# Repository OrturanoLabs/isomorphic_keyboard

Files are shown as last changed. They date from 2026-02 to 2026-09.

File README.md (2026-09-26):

# Isomorphic keyboard

An open-source, **modular isomorphic keyboard**. The instrument is built from identical
12-key tiles that plug into each other in any arrangement. A pico-ice (Lattice iCE40UP5K)
rediscovers the arrangement on every scan and plays it over **MIDI**. Tiles can be added,
removed and moved while playing.

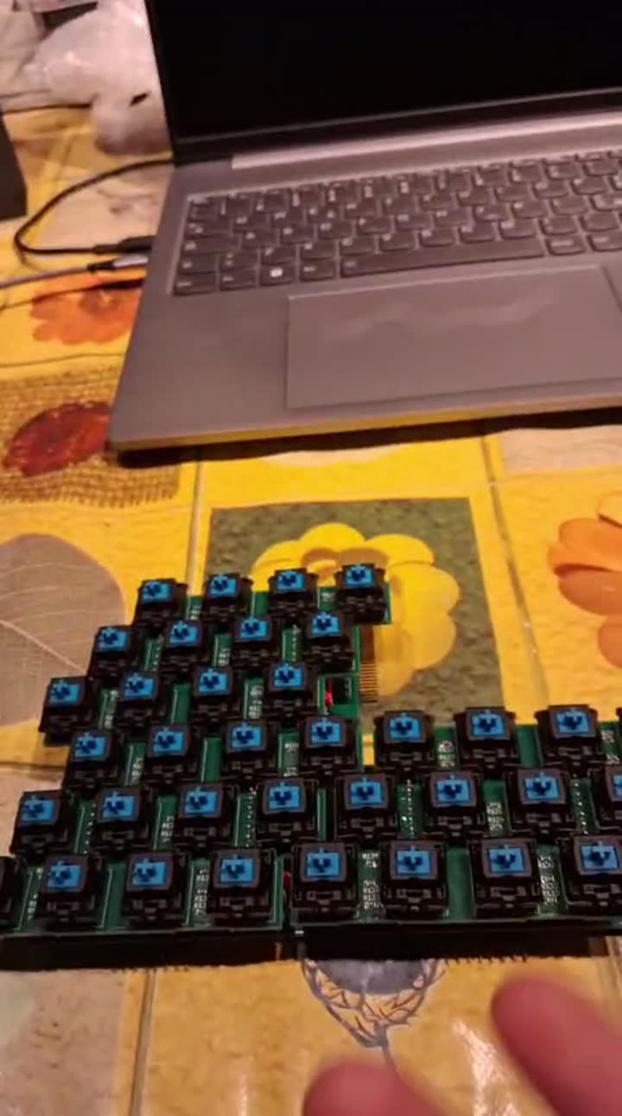
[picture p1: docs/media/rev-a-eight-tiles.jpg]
Eight rev-A tiles


## Status

- **rev A** (tag `rev-a-prototype`): working prototype. Double-stack tiles (key board over
  logic board), hot-plug, automatic above/below/beside detection, MIDI DIN output.
- **rev B** (branch `rev-b`, in progress): the same function with cleaner signals
  (termination, 4-layer stack-up) and a PCB ready for automated assembly.

## Repository layout

| Path | Content |
|---|---|
| `docs/` | documentation: [index](docs/index.md), [engineering ledger](docs/LEDGER.md) |
| `hardware/kicad/tile/` | KiCad project of the tile (key board + logic board) |
| `hardware/simulation/` | behavioural VHDL model of a tile and grid testbenches |
| `hardware/fabrication/rev-a/` | gerbers and BOM of the manufactured rev-A boards |
| `firmware/ice40/` | controller firmware (VHDL) for the pico-ice |
| `firmware/experiments/` | earlier bring-up designs, kept for reference |
| `tools/` | rootless container recipes, `kicad-cli` / OSS CAD Suite wrappers, check scripts |
| `LICENSES/` | full license texts |

## Quick start

```sh
# firmware (rootless podman)
podman build -t localhost/oss-cad-suite:2026-09-26 tools/containers/oss-cad-suite
cd firmware/ice40 && ../../tools/oss.sh make && make upload-flash

# hardware
flatpak install --user flathub org.kicad.KiCad
flatpak run org.kicad.KiCad hardware/kicad/tile/isomorphic_tile.kicad_pro
```

See [docs/build/firmware.md](docs/build/firmware.md) and
[docs/build/hardware.md](docs/build/hardware.md).

## Licenses

| Part | License |
|---|---|
| Hardware (`hardware/`) | CERN-OHL-S v2 |
| Firmware and tools (`firmware/`, `tools/`) | GPL-3.0 |
| Documentation (`docs/`) | CC BY 4.0 |
| Vendored Open Logic subset (`firmware/ice40/src/open-logic/`) | PSI HDL Library License 1.0 |

Full texts are in `LICENSES/`. Each top-level folder has its own `LICENSE.md`.

© Orturano Labs

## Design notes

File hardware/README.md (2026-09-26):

# Hardware

| Folder | Content |
|---|---|
| `kicad/tile/` | KiCad project `isomorphic_tile`: key board (12 Cherry MX keys) and logic board (shift registers, chaining logic, edge connectors), fabricated as one panel |
| `simulation/` | behavioural VHDL model of a tile (`tile.vhdl`, `74hc165.vhdl`) and grid testbenches (`tile_tb*.vhdl`); run with `make` (GHDL), view with GTKWave |
| `fabrication/rev-a/` | gerbers and BOM of the rev-A boards as manufactured |

Start with [docs/architecture/overview.md](../docs/architecture/overview.md) and
[docs/build/hardware.md](../docs/build/hardware.md). The latter covers the mandatory
ERC/DRC/invariant checks.

License: CERN-OHL-S v2 (see `LICENSE.md`).

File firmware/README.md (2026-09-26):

# Firmware

| Folder | Content |
|---|---|
| `ice40/` | controller for the pico-ice (iCE40UP5K): tile scan, topology discovery, debouncing, MIDI UART |
| `experiments/` | earlier bring-up designs: `i2c_picoice` (I2C master test), `scan_low_rate` (slow tile scan), `scan_low_rate_i2c` (slow scan + I2C output) |

There is no microcontroller firmware yet: the pico-ice FPGA sends MIDI directly.

Build, flash and simulation: [docs/build/firmware.md](../docs/build/firmware.md).
Protocol: [docs/architecture/protocol.md](../docs/architecture/protocol.md).

License: GPL-3.0 (see `LICENSE.md`). The vendored Open Logic subset keeps its own license.

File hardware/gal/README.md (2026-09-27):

# GAL experiment: rev-A/B glue logic in one ATF22V10C

`tile_glue.pld` puts the seven glue ICs of the rev-A/B tile (U101 2G126, U102 2G08,
U105 1G04, U106 2G32, U107 2G125, U108 2G74, U109 '161) into **one ATF22V10C** (Microchip,
in production, 5 V, TSSOP-24/SOIC-24). The two '165 shift registers stay, so a tile would
have 3 ICs instead of 9. The scan protocol and the FPGA firmware are unchanged.

| Macrocell | Function |
|---|---|
| Q0–Q3 (buried) | 4-bit counter of board-clock edges, cleared by the latch ('161) |
| BW | sticky column-end flag = B_W output ('74 + 2G08 + 2G32) |
| TCLK / LCLK | board clock forwarded up (W = 0) or left (W = 1) ('125/'126) |
| LATCH / NPL | latch merge to the neighbours and, inverted, to the '165 /PL ('32 + '04) |
| DS | serial input of the '165 chain: left when W = 1, top otherwise |

**All 10 macrocells are used: no margin left.**

The 22V10 allows a **single product term** for both the output enable and the
asynchronous reset. That forced two adaptations:

- T_clk is driven **low** when unselected instead of floating. At most this makes a
  falling edge, and the registers count rising edges.
- The asynchronous reset (AR) uses the feedback of the LATCH output.

Build (open source, rootless):

```sh
podman build -t localhost/galette tools/containers/galette
cd hardware/gal && podman run --rm --userns=keep-id -v "$PWD":/work:Z localhost/galette tile_glue.pld
```

This produces `tile_glue.jed`, plus `.chp` (pin diagram), `.fus` and `.pin`. Program it
with [Afterburner](https://github.com/ole00/afterburner), an open-source Arduino-based
GAL programmer. It lists ATF22V10B/CQZ; check ATF22V10C support before buying.

**Status:** assembled and fits. **Not simulated yet.** The equations were derived by
hand from the rev-A netlist.

**Verdict:** the GAL answers "fewer parts, no firmware on the tile". It does not provide
a return path for per-key LEDs, which is why rev C goes the microcontroller way.

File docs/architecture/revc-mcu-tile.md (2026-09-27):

# Rev C tile with a microcontroller (architecture draft)

Status: **draft for review**. It supersedes the "74xx logic folded on one board" idea of
[revc-single-board.md](revc-single-board.md). The geometry work there (lattice,
edge windows, contact placement) still applies.

## Why the architecture changes

Rev C goals (owner, 2026-09-27):

- a single board;
- the minimum equilateral MX lattice (18.36 mm);
- few, simple, widely available parts;
- modular;
- **strictly open-source tooling**;
- room for a **return path**: per-key LEDs, or any tile-side output.

With 74xx logic, a return path costs extra shift registers and 1–2 extra lines per edge
(7–9 contacts per edge). The 18.4 mm tile has no room for that: the 74xx version already
leaves 13 connections unrouted on 4 layers, and the top edge fits only 7 contacts.

A small microcontroller per tile replaces all nine logic ICs:

- one **bidirectional** data line per edge carries key events up and LED commands down,
  so no extra contacts are needed;
- per-key addressable LEDs hang off one pin.

Why not a small FPGA per tile: it would need 1.2 V + 3.3 V regulators, cannot use 5 V
I/O, needs an external configuration flash, comes in fine-pitch packages and costs
2–6 €, for a job (12 keys, a few messages, 12 LEDs) that a 1 € microcontroller does
easily. The FPGA stays where parallel work pays off: the controller.

## Tile block diagram

```
          top edge: VCC DATA_T GND                (passive pads)
        +-------------------------------------------------+
 left   |  12 x MX switch --> GPIO (internal pull-ups)     |  right
 edge   |                                                  |  edge
 pads   |  ATtiny1616 (VQFN-20, 5 V, 20 MHz)               |  springs
 VCC    |    DATA_L  DATA_R  DATA_T  DATA_B  (1 wire each) |  VCC
 GND    |    LED --> SK6812MINI-E x 12 (optional, chained)  |  GND
 DATA_L |    UPDI (programming pad)                        |  DATA_R
        +-------------------------------------------------+
          bottom edge: VCC DATA_B GND             (springs)
```

## Parts per tile

| Part | Qty | Notes |
|---|---|---|
| ATtiny1616-MNR (VQFN-20 3×3 mm; the SOIC-20 wide does not fit) | 1 | 1.8–5.5 V; 20 MHz at ≥ 4.5 V; open toolchain (avr-gcc, avrdude/pymcuprog, SerialUPDI) |
| 100 nF + 1–4.7 µF decoupling | 2 | |
| series resistor on each edge data line (~100 Ω) | 4 | edge-rate control and ESD/short protection on the hot-plug contacts |
| Kailh MX hot-swap socket | 12 | as rev B |
| SK6812MINI-E reverse-mount RGB LED + 100 nF | 12 + (3–12) | **optional**; in the Cherry MX drawing the LED window is **south** of the centre hole, opposite the pins/socket (north), so there is no conflict |
| edge contacts | 3 per edge | VCC, DATA, GND: springs on the right/bottom edges, pads on the left/top edges |

That is about 7 parts without LEDs, instead of about 63 in rev B. There are no key
resistors: the switch goes to GND and the pin uses its internal pull-up.

## Switches and LEDs

- The Cherry MX drawing ("1-Pole w/LED") puts the LED window **south** of the centre hole:
  two 1 mm holes at ±1.27 mm, 5.08 mm from the centre. The switch pins, and therefore the
  hot-swap socket, are **north**, so the LED and the socket do not collide.
- For a reverse-mount SMD LED under the PCB, use "RGB"/"SMD-ready" switches with a clear
  top housing or light pipe: Cherry MX RGB, and most Gateron/Kailh/Outemu RGB variants.
  The KiCad footprint `LED_SMD:LED_SK6812MINI-E_3.2x2.8mm_P1.5mm_ReverseMount` includes
  the PCB cut-out.
- SK6812MINI-E pins (KiCad symbol `LED:SK6812MINI-E`): 1 VSS, 2 DIN, 3 VDD, 4 DOUT.
- Keycaps: 3D printed. Use translucent material, or add a window over the LED.

## Pin budget (ATtiny1616, 20-pin; from the Microchip datasheet DS40002204A)

- 17 GPIO are usable, because PA0 stays **UPDI** so the tile can always be reprogrammed.
- Use: 12 keys + 4 edge data lines + 1 LED data = **17**.
- The one USART can map its TX pin to PB2 (default) or PA1 (alternate), and supports
  one-wire half-duplex (loop-back + open-drain). So 2 edges use the hardware USART and
  the other 2 use timer/pin-change based software serial. At the planned 100–250 kbit/s
  and 20 MHz this is comfortable.
- Which port carries which key, edge line or LED data is decided by the board layout (pin
  swapping, see below) and stored in `hardware/kicad/revc-mcu-tile/pinmap.json`.

## Power (5 V)

- The whole tile runs from 5 V, with no regulator (MCU and LEDs are specified for 5 V).
- The controller side (pico-ice, 3.3 V I/O) needs **one** level-shifted adapter to the
  first tile's bottom edge.
- LED budget: about 5 mA average per LED at moderate brightness × 120 keys (10 tiles) ≈
  0.6 A, all flowing through the contacts near the controller. Use 2 VCC + 2 GND
  contacts per edge, have the firmware cap the brightness, and feed from USB (≤ 0.9 A for
  USB 3, 0.5 A for USB 2) or an external 5 V supply.

## Protocol (first sketch)

- **Physical:** each edge is one open-drain, pulled-up line (idle high) with half-duplex
  UART framing. An unconnected edge reads high with no traffic, and a neighbour answers
  a probe, which gives presence detection without the rev-A/B GND tricks.
- **Enumeration:** the controller talks to the tile on its bottom edge. Each tile
  forwards discovery on its other edges, and the result is a spanning tree rooted at the
  controller with a relative position (row, column) for every tile, the same information
  the rev-A/B W/first/endcol logic produces.
- **Hot-plug:** periodic re-discovery (every ~100 ms) plus an event when an edge changes
  state.
- **Upstream:** key-down / key-up events, (tile id, key).
- **Downstream:** LED frames (tile id, 12 × RGB) and configuration.
- **Latency:** ~10 hops at 250 kbit/s with small frames is well under 1 ms.

## Controller

- The pico-ice RP2040 (pico-sdk, BSD) runs the tile protocol, the note mapping, USB-MIDI
  and DIN MIDI.
- The iCE40 is no longer required for scanning. It stays available for other uses.

## Open questions

1. ATtiny1616 (≈1.2 $, most established open toolchain, SOIC hand-solderable) vs
   CH32V003 (≈0.14 $, TSSOP-20, open ch32fun toolchain). The draft uses the ATtiny1616.
2. ~~SOIC-20 vs VQFN-20~~: VQFN-20 (the SOIC does not fit between sockets and LEDs).
3. ~~Contact count~~: 3 per edge (VCC, DATA, GND).
4. Programming in production: UPDI pad per tile, or UPDI through an edge contact to
   flash tiles in place.

## Design flow: circuit -> schematic -> board

`hardware/kicad/tile/scripts/revc_mcu_route.sh` runs the whole flow, open source end to end
(KiCad 10 + KiCadRoutingTools in a rootless container):

1. `revc_mcu_circuit.py` defines the circuit once: parts, fixed pin roles, nets, chain
   order. The assignment of the 15 interchangeable MCU pins comes from
   `hardware/kicad/revc-mcu-tile/pinmap.json` (step 3).
2. `revc_mcu_schematic.py` draws it as a KiCad schematic (`revc_mcu.kicad_sch`, stock KiCad
   symbols embedded, stable UUIDs so the file diffs cleanly).
3. `kicad-cli` exports the netlist; `revc_mcu_build.py` builds the board and takes **every
   net** from that netlist. It stops if the board and the schematic do not have the same
   components and footprints, and it links each footprint to its symbol. After placement it
   does the **pin swapping**: it gives the 15 interchangeable signals (12 keys, top and
   left edge lines, LED data) the MCU pins whose angle around the package matches, in
   order, the direction each signal goes, so that the fan-out of the 0.4 mm-pitch VQFN has
   no crossings. If that changes `pinmap.json`, the flow redraws the schematic and builds
   the board again. `pinmap.json` is also what the firmware reads (port of each key, edge
   line and LED data). Fixed by design: PA0 = UPDI, PB2 and PA1 = bottom and right edges
   (USART TX, default and alternate location).
4. ERC on the schematic (errors stop the flow).
5. Routing (below), then DRC **with the schematic parity check**: the board must match the
   schematic net by net, footprint by footprint, field by field.

The result is kept in `hardware/kicad/revc-mcu-tile/` (schematic, board, project, DRC rules,
footprint libraries) and opens as a normal KiCad project: "Update PCB from Schematic" works.
To change the circuit, edit `revc_mcu_circuit.py` and re-run the flow; edits made by hand
in the schematic are overwritten by the next run.

## Routed layout (2 layers)

The routed board passes ERC (clean), DRC with 0 errors, 0 unconnected items and 0 schematic
parity issues. `tools/scripts/check_via_in_pad.py` finds no via within 0.2 mm of a same-net
SMD pad.

- **Stack-up:** 2 layers. The top (switch side, no parts) is an almost continuous GND
  plane, the reference for every signal. The bottom carries all parts, the signals, VCC as
  0.3–0.4 mm tracks and a GND pour stitched to the top plane on a 3 mm grid.
- **Rules:** 0.15 mm track and clearance (needed by the 0.40 mm-pitch VQFN), 0.6/0.3 mm
  vias, 0.25 mm hole clearance, 0.3 mm from the board edge.
- **No via-in-pad:** a via-only rule area surrounds every SMD land (0.3 mm, 0.2 mm on the
  MCU), so no pad needs filled and capped vias.
- **LED chain:** it starts at D6, next to the MCU (which sits between D6 and D7), and every
  link goes to a neighbouring key: D6 D5, D1 D2 D3 D4, D8 D7, D12 D11 D10 D9. LEDs whose
  chain runs left to right are turned 180° so that DOUT faces the next LED. The chain
  order by key index is `5 4 0 1 2 3 7 6 11 10 9 8` (`CHAIN` in `revc_mcu_circuit.py`);
  the firmware maps chain positions with it.
- **Reference designators:** SW1–SW12 and D1–D12 follow the keys in row-major order (row 0
  = top row, left to right), with D<n> under SW<n>. J1–J4 are the edge contacts (right,
  left, bottom, top), R1–R4 the series resistors (bottom, right, top, left edge), C1–C6
  the capacitors, TP1 the UPDI pad.
- **MCU orientation:** the flow tries the orientation of the last clean board (stored in
  `pinmap.json`), then the one that faces the VDD pin to C1, then all four, and keeps the
  first board that is fully clean. The routing result depends on small placement details,
  so a search is more reliable than a single fixed choice. The stored board has the MCU at
  90°.
- **LED cut-outs:** a track-and-via rule area fences each reverse-mount LED cut-out (routers
  see only the outer outline). A custom DRC rule (`revc_mcu.kicad_dru`) accepts the
  library land pattern's pads next to their own cut-out.
- **Decoupling:** 100 nF + 4.7 µF at the MCU (C1, C2) and 100 nF next to the corner LEDs
  (C3–C6 at D1, D4, D9, D12).

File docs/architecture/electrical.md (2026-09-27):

# Electrical design (rev A)

Source: `hardware/kicad/tile/isomorphic_tile.kicad_sch` with the hierarchical sheets
`tile`, `counter`, `keyboard` and `power`.

## Power

- A single 3.3 V rail (`VCC`) comes from the controller and is chained through pin 1 of
  every edge connector. There is no regulator on the tile.
- The key board has its own `VCC_T` / `GND_T` nets, joined to `VCC` / `GND` through the
  stacking connectors (J105/J106 ↔ J108/J107, pins 1 and 8).
- Decoupling on the logic board is 2 × 100 nF (0805), 2 × 4.7 µF (1206) and 1 × 100 µF
  electrolytic (THT).

## Logic parts

The symbol values and the ordered part numbers disagree in rev A. Until the chip markings
of a built tile have been checked, treat the **MPN column** as the intended part.

| Ref | Function | Symbol value (rev A) | MPN (rev A BOM) |
|---|---|---|---|
| U101 | 2× buffer, active-high OE (`L_clk` out, `L_data` in) | 74AUC2G126 | 74LVC2G126DCTRG4 |
| U102 | 2× AND (W, column-end detect) | 74AUC2G08 | SN74LVC2G08IDCTRQ1 |
| U103, U104 | 8-bit PISO shift register | 74HC165 | SN74LVC165ADR |
| U105 | inverter (latch → `~rst`) | 74AHC1G04 | SN74LVC1G04DBVR |
| U106 | 2× OR (latch merge, flag feedback) | 74LVC2G32 | SN74LVC2G32DCTR |
| U107 | 2× buffer, active-low OE (`T_clk` out, `T_data` in) | 74AUC2G125 | SN74LVC2G125DCTR |
| U108 | D flip-flop (column-end flag, `B_W`) | 74LVC2G74 | SN74LVC2G74DCTR |
| U109 | 4-bit counter (frame boundary `Tc`) | 74LS161 | SN74HC161DR |

74AUC parts are specified only up to 2.7 V. They must not be used on the 3.3 V rail.

## Keys

Each key connects `VCC_T` to a node with a 10 kΩ pull-down (R122–R133). A 100 Ω series
resistor (R110–R121) connects that node to the stacking header. Pressed = '1'.

## Signal integrity (rev A)

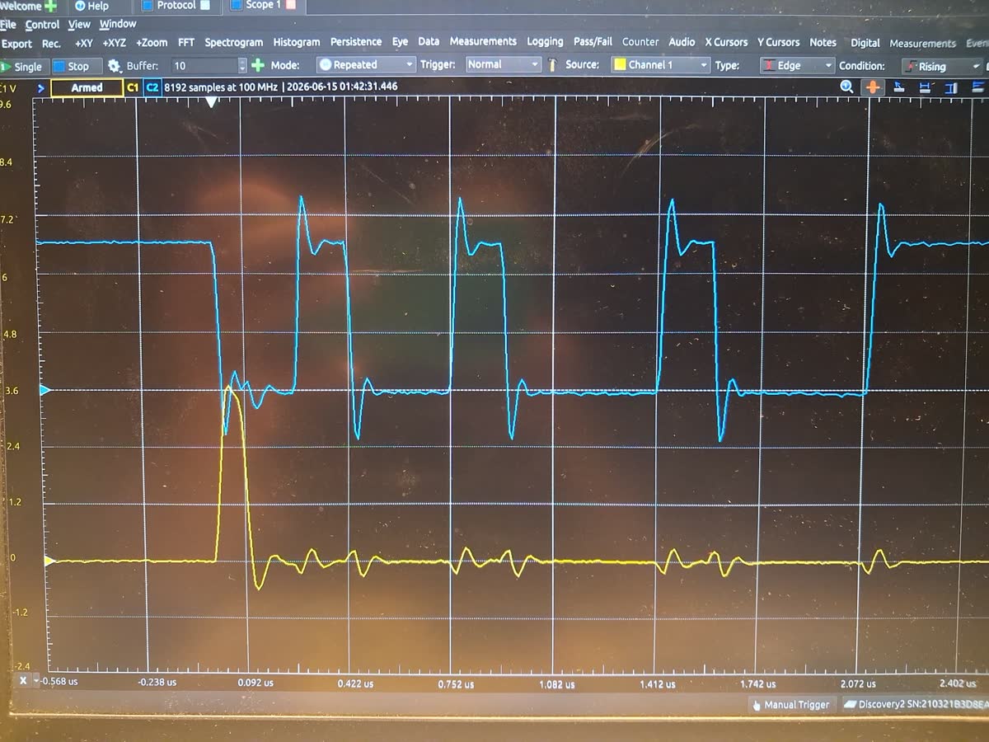
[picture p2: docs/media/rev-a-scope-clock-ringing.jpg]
AD2 capture of the rev-A clock


The 2026-06-15 capture shows the following on the board clock:

- about 40 % overshoot;
- about 1 V undershoot below ground;
- 20–30 MHz ringing after every edge;
- coupled spikes on the neighbouring channel.

Contributing factors found in the rev-A design:

- **No source termination.** The LVC drivers (U101, U107, U104 Q7, U106, U108) have
  about 15–25 Ω output impedance and edges of about 1–2 ns, which is fast enough for a
  few centimetres of track plus a connector to act as a transmission line. They drive the
  inter-board lines directly.
- **Multi-drop nets.** `B_clk` is 141 mm long and joins J103, J104, a pull-up and 6 IC
  inputs. `L_latch` and `B_data` each leave through two connectors.
- **Return path.** The board has 2 layers, with a GND pour on top and a VCC pour on the
  bottom, and both pours are cut up by tracks. Signals on B.Cu are referenced to VCC. The
  edge connectors have few ground pins (J101: 1 of 6; J103: 2 of 8).
- **Measurement set-up.** The Analog Discovery 2 has about 30 MHz of bandwidth, the probe
  had a long ground lead, and the controller link used 20 cm dupont wires without a
  ground alongside. All of these add ringing of their own.

### Rev B (branch `rev-b`)

The rev-B work addresses these points without changing the logic,
the connector pinout or the connector positions. It adds series resistors at the drivers,
per-IC decoupling, a 4-layer stack-up with a solid ground plane, and controlled-impedance
routing of the inter-board nets. Results will be recorded here and in
[the ledger](../LEDGER.md).

Rev-B design, function unchanged:

- 33 Ω series resistors R201–R207 at every driver that leaves the tile: `L_clk`, `T_clk`,
  `L_latch`, `T_latch`, `B_data`, `R_data` and `B_W`. The driver side is named `*_drv`.
- One 100 nF (0603) capacitor next to each logic IC (C201–C209).
- A 4-layer, 1.6 mm stack-up: L1 signal, L2 GND (`GND_T` on the key board), L3 VCC
  (`VCC_T`), L4 signal. The prepreg is 0.21 mm, so the 0.3 mm `Interboard` tracks are about
  55 Ω. There is a 4 mm grid of ground stitching vias.

### Simulation results (`hardware/si/`, updated 2026-09-27)

Models:

- The TI parts use their **vendor IBIS data** (`models/*.ibs`, converted by
  `ibis_lite.py`). LVC outputs switch in about 0.5–0.75 ns, and LVC inputs have **no clamp
  to VCC** (they are 5 V tolerant), so overshoot is not limited by the receivers.
- The pico-ice driver and the dupont link are **calibrated on the rev-A capture**, which
  was digitised from the phone photo (`digitize_scope.py`, `fit_measurement.py`). The AD2
  front end is modelled as 24 pF || 1 MΩ with a 30 MHz Butterworth.

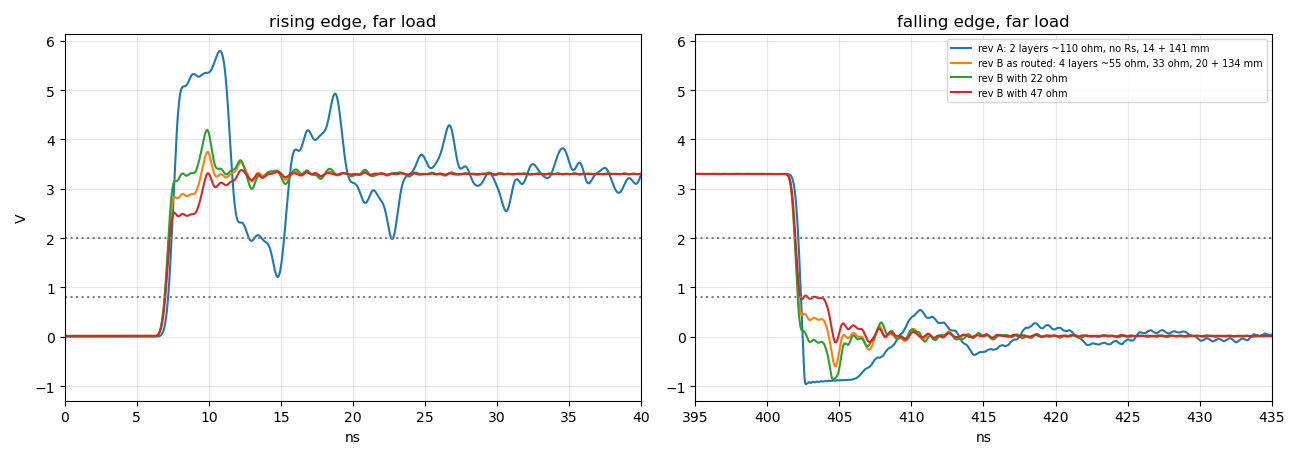
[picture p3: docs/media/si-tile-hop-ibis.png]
Tile hop with IBIS models


| Tile-to-tile clock hop (IBIS, far load) | Overshoot | Undershoot | Crossings of VIH on a rising edge |
|---|---|---|---|
| rev A (2 layers, ~110 Ω, no series R) | 76 % | −0.96 V | **7: the edge rings back below 2.0 V** |
| rev B as routed (4 layers, ~55 Ω, 33 Ω) | 14 % | −0.60 V | 1 |
| rev B with 22 Ω | 27 % | −0.86 V | 1 |
| rev B with 47 Ω | 2 % | −0.11 V | 1 (but the falling edge dwells on VIL) |

These are lossless, typical-corner models, so they are pessimistic: rev A does work on
the bench. The conclusion is relative: **rev A has little or no margin against double
clocking, rev B with 33 Ω has a large one.** 33 Ω is the right value; 47 Ω makes the far
end step at the threshold.

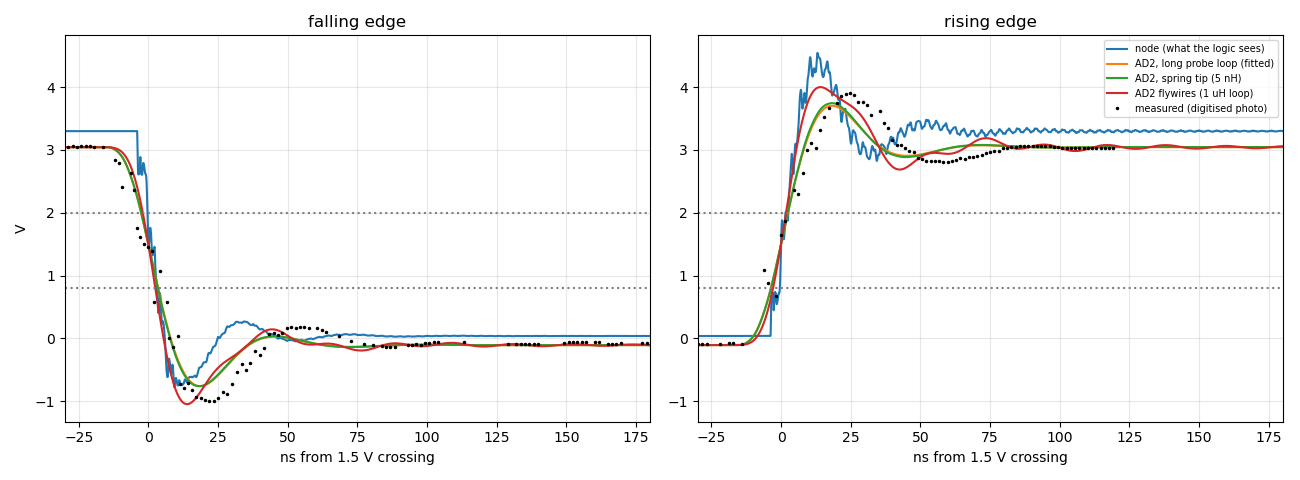
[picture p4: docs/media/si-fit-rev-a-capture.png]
Calibrated model vs the rev-A capture


Controller link (pico-ice → first tile over dupont wires), calibrated model (RMS error
0.20 V against the digitised capture):

- The AD2 view reproduces the capture. The node the logic sees has about **38 %
  overshoot, −0.8 V undershoot and a stepped rising edge**, most of which the 30 MHz AD2
  cannot show.
- A spring ground tip on the AD2 would barely change the picture (RMS 0.207 V vs 0.203 V).
  The instrument bandwidth, not the ground lead, hides the problem. See
  [measuring](../build/measuring.md).
- A series resistor at the pico-ice outputs (on an adapter board), from `controller_fix.py`:

| Series R | Overshoot | Undershoot | Clean single crossings |
|---|---|---|---|
| 0 Ω (today) | 38 % | −0.78 V | no (3 on VIH) |
| 100 Ω | 13 % | −0.35 V | **yes** |
| 150–220 Ω | 1–5 % | ≈0 V | no (slow step on VIH) |

  **Recommendation: 100 Ω.** Confirm it on the bench: the fitted driver resistance ended
  at its bound, so the model is not unique.

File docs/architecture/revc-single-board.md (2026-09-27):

# Rev C study: a single-board tile

Question: can the double stack (key board over logic board) become **one PCB**, keeping
the key lattice and the logic unchanged?

Short answer: **the electronics fit, the edge connectors do not.** A single-board tile is
geometrically possible only with a new tile-to-tile contact system. Such a tile would be a
new generation: it can mate with other rev-C tiles but not with rev-A/B tiles.

All numbers below come from scripts in `hardware/kicad/tile/scripts/revc_*.py` run on the
rev-B board. Outputs are written to `production/revc/`.

## Geometry of the stack (rev A/B)

- The logic board sits under the key board. J105/J106 on the logic board mate with J107/J108
  under the key board, which gives the transform logic → key coordinates
  **(+10.96, −60.90) mm**. Rev A has a 0.04 mm mismatch between the two stacking connector
  pairs.
- Tile lattice (from the edge connectors, 13.9 mm between mated header and socket pads):
  - right neighbour **(+80, 0) mm**, with a 3 mm gap between the key boards;
  - upper neighbour **(+10, −51.96) mm**, which is 3 rows of 17.32 mm, with about 1 mm gap.
- The right-angle 2.54 mm edge connectors live **under** the neighbour's key-board
  overhang, about 11 mm below the keys. That free space is what makes the stack work.

## The skew: oblique tiles, orthogonal links

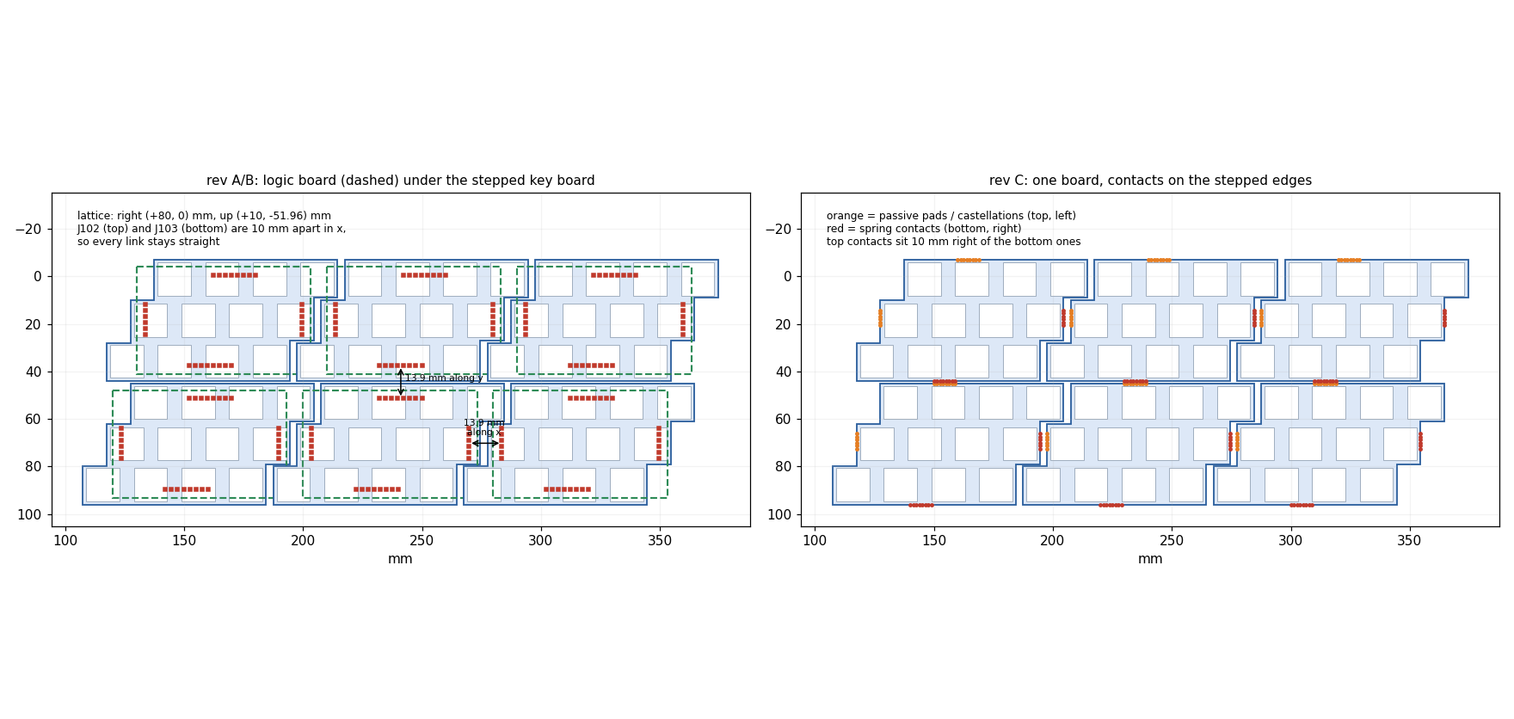
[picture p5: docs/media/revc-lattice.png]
Tiling of rev A/B and rev C


The key lattice is hexagonal: every row is shifted by 10 mm. The tiles therefore repeat
on an **oblique** lattice (right +80/0 mm, up +10/−51.96 mm), and the key board has a
stepped outline so that neighbours interlock.

**How rev A/B solve it.** The logic board is an ordinary rectangle, and so are its edge
links:

- left/right links are pure x;
- top/bottom links are pure y.

The skew is absorbed by the connector **positions**: the top connector J102 is 10 mm to
the right of the bottom connector J103, which is exactly the lattice shift of the tile
above. The rectangles do not interlock. The 13.9 mm of mated header+socket sit in the
free space under the neighbour's overhanging key board, about 11 mm below the keys.

**How rev C solves it.** The stepped outline is made only of horizontal and vertical
segments, so the links can stay orthogonal on the key board itself:

- **left/right**: the vertical edge segments of the same row face each other with a 3 mm
  gap (row 1: x 204.5 ↔ 207.5, row 2: 194.5 ↔ 197.5, row 3: 184.5 ↔ 187.5), so a contact
  row on the row-2 segment mates along x;
- **top/bottom**: the top edge (y 45, x 127.5–204.5) faces the bottom edge of the tile above
  (y 44.04, x 117.5–194.5) over 67 mm with a 0.96 mm gap, so contacts mate along y. As in
  rev A/B, the top contacts sit 10 mm to the right of the bottom contacts.

The skew is still absorbed by positions, only now at the edges instead of on a hidden
rectangle. The oblique tiling also gives each tile up to 6 neighbours (up-right and
down-left touch too, along short step segments). They are not needed electrically,
because the scan chain uses the same 4 directions as today.

**Putting a tile in place (compare the 2026-06-30 videos).** With 2.54 mm headers a tile
is re-attached by **sliding it sideways** into its neighbour. A tile that has neighbours
on two orthogonal sides has to enter along two directions at once, and this only works
thanks to the play of the pins. Spring contacts with a lead-in (or pogo pins with rounded
tips) plus magnets would let a rev-C tile be **dropped in from above** and pulled into
place, whatever neighbours it has. This is a usability gain, not only a manufacturing one.

## Folding the logic board onto the key-board bottom

`revc_feasibility.py` moves every logic footprint by the stack transform, flips it to the
bottom side (the top carries the switches), removes J105–J108 and the logic-board outline,
and closes the key-board outline.

**Edge connectors at their rev-A/B positions: 61 conflicts.** Every pin of J101–J104 lands
under a switch body (the THT pin end would stick up into the switch). Many of them also
hit a 4 mm centre hole, a 3 mm switch-pin hole, a 1.75 mm peg hole, or a hot-swap socket
pad. The connectors cannot stay where they are.

**Logic parts:** with the collision-free placer from rev B:

| Variant | Placed | No room |
|---|---|---|
| rev-B parts as they are | 40 / 42 | U109 (SOIC-16), C105 (6.3 mm electrolytic) |
| U109 as TSSOP-16 (same chip, SN74HC161PWR), C105 as a 1210 ceramic | **42 / 42** | – |

The same logic ICs and the same schematic function fit between the hot-swap sockets on
the bottom of the key board. Changing only the package of U109 is not a logic change.

## Room for tile-to-tile contacts

`revc_edges.py` measures the free windows along every edge on the bottom side. It keeps
0.5 mm clear of the switch holes (the switch posts stick out below the board) and 0.3 mm
clear of the socket pads and courtyards. Main results:

| Edge | At 0.5 mm from the edge | At 2 mm | At 4 mm |
|---|---|---|---|
| top (77 mm) | 76.4 mm continuous | windows of 6.2 mm (between sockets) | 4.2 mm |
| bottom segments | 10–27 mm | 10–27 mm | 10–27 mm |
| left segments (16–18 mm) | 9–10 mm | 7.7–10.3 mm | 6.8–8.1 mm |
| right segments (16–18 mm) | 15–17 mm | 11–12 mm | 6.4–7.1 mm |

Consequences:

- A 2.54 mm right-angle header (≥ 8 mm deep) cannot sit at any edge.
- A contact row at 1.27 mm pitch fits: 6 contacts = 7.6 mm and 8 contacts = 10.2 mm.
  It fits on every edge if the **passive half** (castellated half-holes or edge pads,
  ≤ 0.5 mm deep) is on the **top and left** edges, where only a thin strip is free, and the
  **active half** (spring contacts or right-angle pogo pins, 2–4 mm deep) is on the
  **bottom and right** edges, where the windows are deep.
- The gaps to the neighbours are about 3 mm (left/right) and about 1 mm (top/bottom). That
  is within the travel of common spring contacts. Magnets in the free bottom windows would
  give alignment and retention.
- Hot-plug: make the GND contact first-mate (longer spring or wider pad), as rev A/B
  implicitly do.

## Could the edge connectors stay through-hole (everything else SMD)?

No. `revc_tht_search.py` tries **every** position (0.25 mm grid) for a right-angle THT edge
connector:

- 1x6 columns for left/right, 1x8 rows for top/bottom;
- 2.54 mm pitch (1.7 mm pads) and 1.27 mm pitch (1.0 mm pads).

A position is valid only if:

- the pads are fully on the board, with 0.3 mm to the edge;
- on the switch side, no pad lands in a switch body or hole;
- on the bottom, the connector body has a clear corridor from the pin row to the edge (no
  socket, no switch post).

**Result: 0 feasible positions on every edge, for both pitches.** On the top side the switch
bodies come within 1.1–1.5 mm of every edge, so a THT pad near the edge is impossible.
Further inside, the body would have to run under a row of switches (posts, sockets) to
reach the edge. So a single-board tile is necessarily **all-SMD, connectors included**
(SMD right-angle 1.27 mm pairs, or spring contacts + pads).

## Pros and cons

| | Double stack (rev A/B) | Single board (rev C concept) |
|---|---|---|
| PCBs per tile | 2 (1 panel) | 1 |
| Hand-soldered parts | 4 edge + 4 stacking connectors | none (springs/castellations are SMD or part of the PCB) |
| Height | about 11 mm stack + switches | 1.6 mm + switches |
| Tile-to-tile link | robust 2.54 mm headers, also the mechanical joint | spring contacts + magnets; mechanical design needed |
| Compatible with rev A/B tiles | yes | **no** (the contacts are at a different height) |
| Interchangeable key layouts on one logic board | yes | no |
| Assembly | two sides (key board B, logic board F) | one side (bottom) + switches pushed in |

## Routability

`revc_route_test.py` runs the rev-B flow on the folded board:

1. merge the stacking-connector nets 1:1 (`BTNs_L<k>` ↔ `BTNs<k>`, `VCC_T`/`GND_T` →
   `VCC`/`GND`);
2. inner GND/VCC planes over the whole board and power fan-out;
3. Freerouting, then ground pours and zone fill.

Result: **routed completely, KiCad DRC 0 errors and 0 unconnected items.** The edge
contacts are not on the board yet. Remaining warnings: silkscreen and library notes.

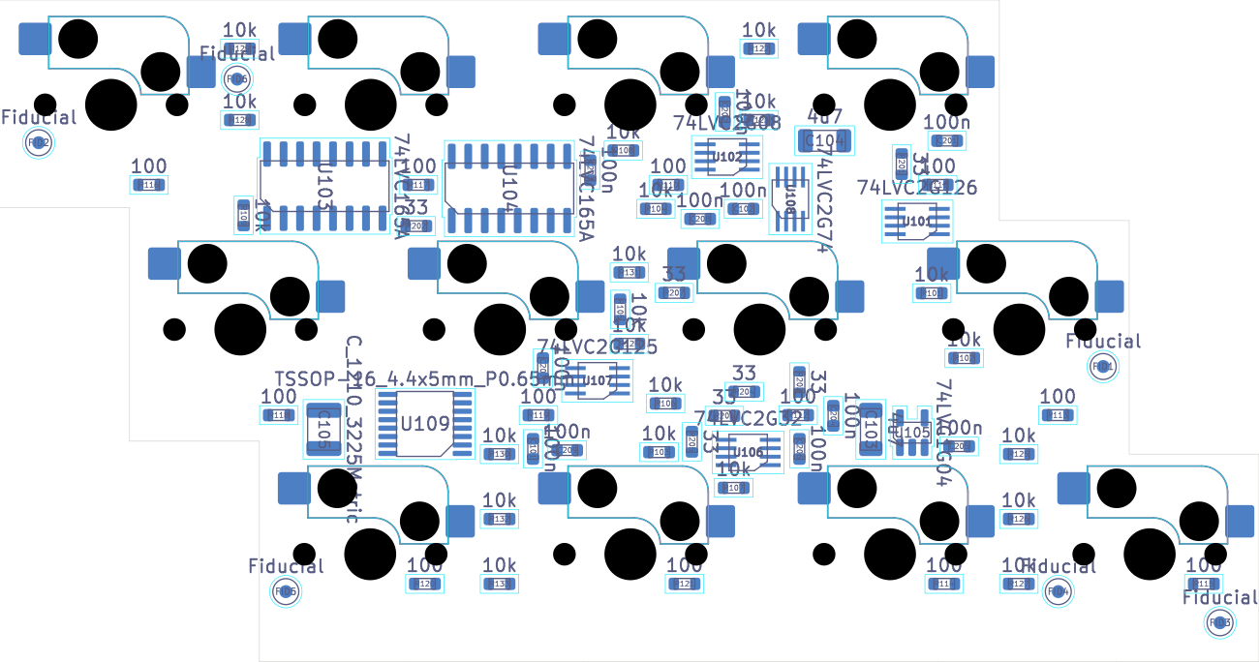
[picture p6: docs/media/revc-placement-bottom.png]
Rev C placement, bottom side


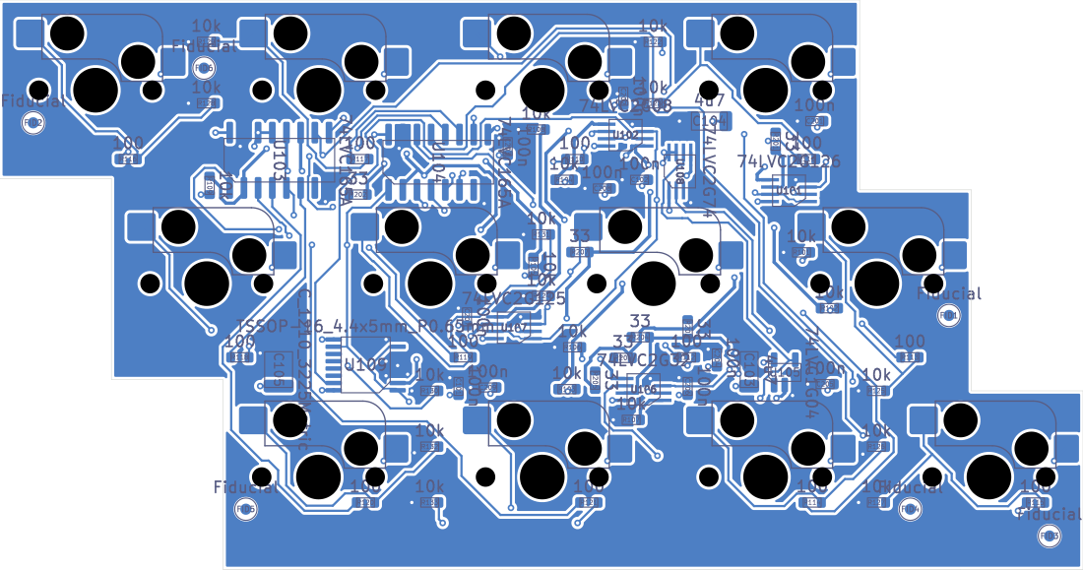
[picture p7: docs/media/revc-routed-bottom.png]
Rev C routed, bottom side


## Verdict and next steps

1. A single-board tile is **feasible**. The same logic fits and routes on the bottom of the
   key board with 4 layers; only U109 changes package (TSSOP-16) and C105 becomes a 1210
   ceramic.
2. It needs a **new edge-contact system**: castellations on the top and left edges, spring
   contacts on the bottom and right edges, and magnets. The 2.54 mm headers cannot be used.
   This is the real design work: part selection (contact travel ≥ gap tolerance), contact
   resistance on the clock/latch nets, first-mate GND, and mechanical retention.
3. Rev-C tiles would be a new generation, not mixable with rev A/B, unless an adapter tile
   is made.
4. Prototype suggestion before committing: order one rev-B panel (the function is proven)
   and, in parallel, a small rev-C test coupon with two half-tiles to qualify the spring
   contacts for hot-plug and for the SI of the scan clock through a spring contact.

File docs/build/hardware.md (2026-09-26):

# Working on the hardware

## KiCad project

- Project: `hardware/kicad/tile/isomorphic_tile.kicad_pro`. It is one project that
  contains both the key board and the logic board (see [mechanical](../architecture/mechanical.md)).
- Rev A is saved in the **KiCad 9** format. The project will be migrated to **KiCad 10** in
  a dedicated commit after rev A is merged into `main`. After that, KiCad 9 can no longer
  open it.
- KiCad is installed as a user-level flatpak:

  ```sh
  flatpak install --user flathub org.kicad.KiCad
  tools/kicad-cli.sh version          # kicad-cli wrapper
  ```

  The flatpak sandbox has its own private `/tmp`. Give it access to extra host paths with
  `KICAD_EXTRA_FS=/path/one:/path/two tools/kicad-cli.sh ...`.
- `kicad-cli` rewrites `*.kicad_prl` even for read-only commands. The file is git-ignored.

## Checks before every hardware commit

```sh
# reference design (tag rev-a-prototype) -> production/reference/ref.{kicad_pcb,net}
tools/scripts/export_reference.sh

cd hardware/kicad/tile
K=../../../tools/kicad-cli.sh
KICAD_EXTRA_FS=/tmp $K sch erc --format json -o /tmp/erc.json isomorphic_tile.kicad_sch
KICAD_EXTRA_FS=/tmp $K pcb drc --schematic-parity --format json -o /tmp/drc.json isomorphic_tile.kicad_pcb
$K sch export netlist --format kicadsexpr -o ../../../production/new.net isomorphic_tile.kicad_sch
cd ../../..
tools/scripts/check_invariants.py pcb production/reference/ref.kicad_pcb hardware/kicad/tile/isomorphic_tile.kicad_pcb
tools/scripts/check_invariants.py netlist production/reference/ref.net production/new.net \
    --series <added series resistors> --ignore <added capacitors>
```

(In zsh, `$K` must be a single word such as the script path above. zsh does not split a
variable that holds a whole command line.)

`check_invariants.py` fails when a switch or connector has moved or rotated, when the
outline has changed, or when any logic connection has changed. Series resistors inserted
into a net and decoupling capacitors that were only added are tolerated when you list them.

## Rev-B PCB pipeline (scripted)

The rev-B board was produced from the rev-A board by scripts, so every step can be
repeated and reviewed:

```sh
# 0. rev-B schematic edits (already applied; the script refuses to run twice)
#    hardware/kicad/tile/scripts/revb_schematic.py
# 1. netlist of the current schematic
(cd hardware/kicad/tile && ../../../tools/kicad-cli.sh sch export netlist --format kicadsexpr \
    -o ../../../production/new.net isomorphic_tile.kicad_sch)
# 2. stage 1: footprints from the netlist, 4 layers + inner planes, single-sided placement,
#    fiducials, power fan-out, DSN export -> production/isomorphic_tile.dsn
#    (start from the rev-A board: git show <rev-a commit>:hardware/kicad/tile/isomorphic_tile.kicad_pcb)
flatpak run --filesystem="$PWD" --command=python3 org.kicad.KiCad \
    hardware/kicad/tile/scripts/revb_pcb.py production/new.net
# 3. autoroute (rootless container, about 3 minutes)
podman build -t localhost/freerouting:2.4.1 tools/containers/freerouting
(cd production && podman run --rm --userns=keep-id -e HOME=/tmp -v "$PWD":/work:Z -w /work \
    localhost/freerouting:2.4.1 -de isomorphic_tile.dsn -do isomorphic_tile.ses -mp 40 --gui.enabled=false)
# 4. stage 2: import the routes, ground stitching, outer pours, zone fill, clean-ups
flatpak run --filesystem="$PWD" --command=python3 org.kicad.KiCad \
    hardware/kicad/tile/scripts/revb_pcb.py --route-in "$PWD/production/isomorphic_tile.ses"
```

The autorouted result is a **starting point for review in the KiCad GUI**, not a finished
layout. It passes DRC with 0 errors, 0 unconnected items and 0 schematic-parity issues;
the remaining warnings are silkscreen cosmetics. A human should still review the clock
routing, the silkscreen and the courtyard edits before ordering.

## Behavioural simulation of the tiles

```sh
cd hardware/simulation
../../tools/oss.sh make          # runs tile_tb and tile_tb_2, VCD in build/
make TB=tile_tb wave             # GTKWave on the host
```

## Fabrication records

`hardware/fabrication/rev-a/` holds the gerbers and the BOM of the boards that were
actually manufactured for rev A. Newer outputs are generated into `production/`, which is
git-ignored and published as release assets.

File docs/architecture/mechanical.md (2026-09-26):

# Mechanical design (rev A)

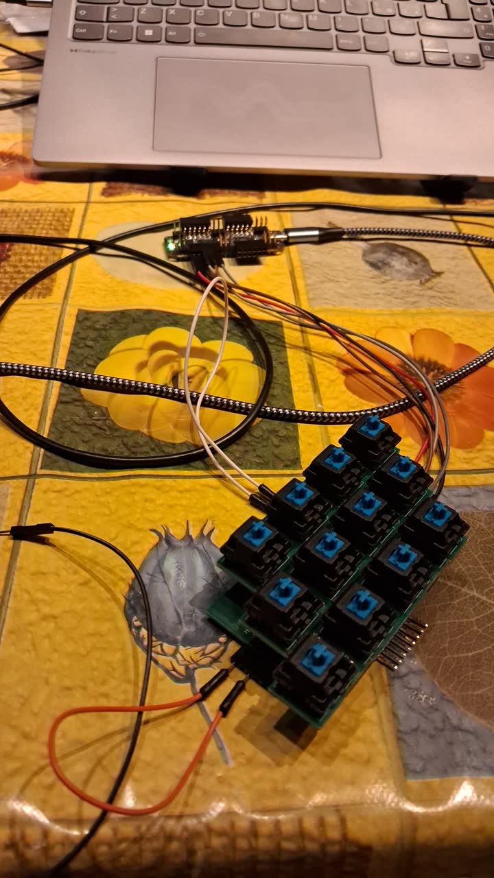
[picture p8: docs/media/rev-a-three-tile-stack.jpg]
Three stacked tiles on the bench


## Tile

- Board thickness 1.6 mm, 2 layers (rev A).
- The **key board** is 97 × 51 mm with a stepped outline so that neighbouring tiles
  interlock. It carries 12 Cherry MX 1u switches in 3 rows of 4:
  - key pitch 20 mm horizontally;
  - row pitch 17.32 mm (20 mm × sin 60°);
  - each row is shifted by 10 mm, which gives a hexagonal lattice.
- The **logic board** is 73.25 × 45.25 mm and sits under the key board. The two are joined
  by stacking connectors J105/J106 (vertical sockets on the logic board) and J107/J108
  (vertical headers on the key board).
- Both boards are fabricated as one panel. They are joined by two tabs at x = 118.5–132.25
  and x = 159.5–173.25, with 0.5 mm NPTH mouse bites at y = 95.75 and y = 109.
- Tile to tile, the logic boards use right-angle 2.54 mm connectors:

| Ref | Edge | Type |
|---|---|---|
| J101 | left | 1×6 socket, horizontal |
| J104 | right | 1×6 header, horizontal |
| J102 | top | 1×8 socket, horizontal |
| J103 | bottom | 1×8 header, horizontal |

**Frozen for all future revisions:** switch positions, connector positions and rotations,
connector pinouts, and the board outlines. `tools/scripts/check_invariants.py pcb`
enforces the switch and connector positions and the outline against the rev-A reference.

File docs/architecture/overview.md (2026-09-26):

# System overview

Eight rev-A tiles playing

The keyboard is built from identical **tiles**. Each tile carries 12 keys on a hexagonal
(isomorphic) lattice. Tiles plug into each other edge to edge (above, below, left, right),
and any contiguous arrangement of columns is read by a single controller. The controller
rediscovers the arrangement on **every scan**, so tiles can be unplugged, moved and
replugged while the instrument is playing. The rev-A prototype does exactly this
(videos of 2026-06-30).

```
             ┌────────┐┌────────┐
             │ tile   ││ tile   │      clock / latch flow up each column and then left
             └───┬────┘└───┬────┘      data flows back down and right
   ┌────────┐┌───┴────┐┌───┴────┐
   │ tile   ││ tile   ││ tile   │
   └────────┘└────────┘└───┬────┘
                           │ J103 (bottom of the bottom-right tile)
                    ┌──────┴──────┐
                    │  pico-ice   │  iCE40UP5K: scan, debounce, MIDI
                    └──────┬──────┘
                           │ MIDI (31250 baud, DIN)
```

## Building blocks

| Block | Where | What |
|---|---|---|
| Key board | `hardware/kicad/tile` (sheet `keyboard`) | 12 Cherry MX switches, 10 kΩ pull-downs, 100 Ω series resistors, stacking headers J107/J108 |
| Logic board | `hardware/kicad/tile` (sheets `tile`, `counter`, `power`) | two '165 shift registers, chaining logic (W buffers, column-end detector), edge connectors J101–J104, stacking sockets J105/J106 |
| Controller | `firmware/ice40` | pico-ice (iCE40UP5K @ 12 MHz): scan FSM, debouncers, change detection, MIDI UART |
| Tile model | `hardware/simulation` | behavioural VHDL model of a tile and grid testbenches |

The key board and the logic board of a tile are two PCBs **stacked** on top of each other
(hence the branch name `double_stack`). They are fabricated together in one panel from a
single KiCad project and separated along mouse-bite tabs.

Further reading:

- [Scan protocol and topology discovery](protocol.md)
- [Electrical design](electrical.md)
- [Mechanical design](mechanical.md)
- [Known issues](../known-issues.md)

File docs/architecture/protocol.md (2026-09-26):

# Scan protocol and topology discovery

This page describes how the controller reads an arbitrary arrangement of tiles through a
single 3-wire link. It is derived from the rev-A schematic
(`hardware/kicad/tile/`) and the firmware (`firmware/ice40/src/top.vhd`).

## Signals between tiles

Every tile has four edge connectors. The mating pairs are top↔bottom and left↔right:

| Pin | J102 top (socket) | J103 bottom (header) | J101 left (socket) | J104 right (header) |
|---|---|---|---|---|
| 1 | VCC | VCC | VCC | VCC |
| 2 | `T_clk` (out) | `B_clk` (in, pull-up) | `L_clk` (out) | `B_clk` (in, same net as J103.2) |
| 3 | `T_data` (in, pull-down) | `B_data` (out) | `L_data` (in, pull-down) | `B_data` (out, same net as J103.3) |
| 4 | `T_endcol` (in, pull-up) | GND | `L_endrow` (in, pull-up) | GND |
| 5 | GND | `B_first` (in, pull-up) | `L_latch` (out) | `R_latch` (in, pull-down) |
| 6 | `L_latch` (out) | `B_latch` (in, pull-down) | GND | GND |
| 7 | `T_W` (in, pull-up) | `B_W` (out) | – | – |
| 8 | GND | GND | – | – |

The controller (pico-ice) is attached to the **bottom connector J103 of the bottom-right
tile**. It drives `B_clk` and `B_latch` and reads `B_data`. `B_first` is left open, so the
pull-up makes that tile "first".

Presence detection is passive:

- A tile above pulls our `T_endcol` low: its J103.4 is GND.
- A tile to the left pulls our `L_endrow` low: its J104.4 is GND.
- A tile below pulls our `B_first` low: its J102.5 is GND.

## Inside a tile

- **Two '165 shift registers** (U104 feeds the output, U103 feeds U104), loaded in parallel
  while the latch is high:
  - U104 D7…D0 hold keys 0…7.
  - U103 D7…D4 hold keys 8…11.
  - U103 D3 and D2 are tied to VCC (two marker bits that are always '1').
  - U103 D1 is `L_endrow` and D0 is `T_endcol`.
- **Latch:** `B_latch OR R_latch` (U106A) is inverted by U105 into `~rst`, which drives the
  '165 `~PL`, the '161 `~MR` and the '74 `~CLR`. The OR output is forwarded to the left and
  top neighbours (`L_latch`, one net on J101.5 and J102.6).
- **Clock:** `B_clk` (one net for the bottom and right connectors) clocks the registers.
  It is re-driven towards **either** the top or the left neighbour:
  - U107 ('125, active-low OE) drives `T_clk` when W = 0.
  - U101 ('126, active-high OE) drives `L_clk` when W = 1.
- **Serial input** (U103 DS) comes from `T_data` through U107 when W = 0, or from `L_data`
  through U101 when W = 1.
- **W** = `T_W AND B_first` (U102B). Only the **bottom tile of a column** (`B_first` = 1)
  can switch to W = 1, and only once the tile above has asserted its `B_W`.
- **Column-end detector:**
  - U109 ('161) counts clocks since the latch. Its terminal count `Tc` marks the 16th bit
    of every frame boundary.
  - U108 ('74) is a sticky flag: `D = Q OR (B_data AND Tc)`, clocked by `B_clk`,
    cleared by the latch. Its Q is `B_W`.
  - When a frame whose last bit (`T_endcol`) is '1' passes through the tile, the flag sets.
    That frame comes from the top tile of the column, so the flag signals "the top of the
    column has been read".
  - The flag propagates down the column. When it reaches the bottom tile, that tile
    switches its serial input and its clock output to the left neighbour. The chain then
    continues with the next column to the left.

## Frame format

After the latch, each tile contributes 16 bits. The FPGA shifts them in MSB-first
(`tile_stream <= tile_stream(14 downto 0) & BOARD_DATA`), so after 16 bits:

| `tile_stream` bit | Meaning |
|---|---|
| 15 … 4 | key states (key 0 at bit 15 … key 11 at bit 4), '1' = pressed |
| 3, 2 | markers, always '1'; anything else is a framing error |
| 1 | `L_endrow`: '0' = there is a tile to the left |
| 0 | `T_endcol`: '1' = this tile is the top of its column |

`map_pbs()` in the firmware reorders bits 15…4 into the physical key order.

## Scan sequence (firmware `pull_fsm`)

1. `r1`: `BOARD_LATCH` high for one scan tick. All tiles load their keys and their flags
   clear. The coordinates reset to column 1, row 0.
2. For every tile, 16 × (`get_bit`: sample `BOARD_DATA`; `c1`: `BOARD_CLK` high for one
   tick). One tick is 17 cycles of the 12 MHz clock (≈1.42 µs), so one bit takes ≈2.8 µs
   (≈350 kHz shift rate).
3. If the marker bits are not `11`, go to `err`. This is a sticky state, the red LED turns
   on, and only a reset clears it.
4. `load`: store the frame and its (row, column) in `keyboard_state`. If bit 1 is '0', a
   further column exists.
5. If bit 0 = '1' (top of column): continue with a new column if one was seen, otherwise
   the scan is done. If bit 0 = '0', read the next tile of the same column.
6. Repeat forever.

## From keys to MIDI

- Each tile slot has a 12-channel debouncer (open-logic `olo_intf_debounce`, 2 ms).
- A change detector XORs the debounced state with its value one clock earlier and
  accumulates the result in `keyboard_pending`.
- A serializer walks the pending bits and computes absolute key coordinates:
  - `y = (row − 1) · 3 + key / 4`
  - `x = (col − 1) · 4 + key mod 4 + row − 1` (each row of tiles is shifted by one key)
- Pitch = `ref_pitch − 2·x + 7·y` with `ref_pitch` = 60 (C4). One key to the left is
  −2 semitones and one row up is +7 semitones.
- It sends `0x90 pitch 0x64` (note on) or `0x80 pitch 0x00` (note off) on a 31250 baud UART,
  output inverted on `PACKAGE_MIDI` for the DIN interface.

See [known issues](../known-issues.md) for the limits of this implementation.

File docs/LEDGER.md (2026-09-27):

# Engineering ledger

Chronological log of attempts, tool setups, measurements and lessons learned.
Its purpose is to stop future sessions from repeating the same mistakes.
Newest entries at the bottom. Each entry has: **Goal**, **What was done**, **Result**,
**Lesson** (when there is one).

Conventions (apply to every session):

- Everything in the repository is written in English (docs, comments, commit messages).
- Software is installed only as a user-level flatpak (`flatpak --user`) or as a rootless
  podman container. Container recipes live in `tools/containers/`.
- Function freeze for rev B: switch positions, connector positions, connector pinouts and
  logic ICs must not change. The rev-A prototype behaviour is the regression baseline
  (hot-plug of tiles, any arrangement, automatic above/below/beside detection, MIDI out).

---

## 2026-09-26 — Kick-off: review of the prototype material

**Goal:** understand the state of the double-stack prototype before planning the doc/reorg,
signal-integrity and PCBA work.

**What was done**

- Reviewed the WhatsApp media dropped in the repo root (not committed):
  - `WhatsApp Image 2026-09-26 at 15.04.20.jpeg`: an Analog Discovery 2 capture from
    2026-06-15 (100 MS/s, 8192 samples). Channel 2 (blue) is a board clock and channel 1
    (yellow) a neighbouring line.
  - ZIP with 3 photos and 2 videos. Two of the photos (2026-06-25) show an HP monitor and
    are **unrelated to the project**. The 2026-06-13 photo shows a 3-board stack wired to the
    pico-ice with ~20 cm dupont wires.
  - Videos (2026-06-30): ~8 tiles played live. Tiles are unplugged and replugged while the
    system runs, rearranged, and still located correctly. The audio contains synth output
    (scales and chords) and ~11 s of speech.
- Audio was extracted with ffmpeg and inspected as a spectrogram
  (`ffmpeg -i x.mp4 -ac 1 -ar 16000 x.wav`, then
  `-lavfi showspectrumpic=s=1600x500:scale=log:stop=4000`).
  No speech-to-text tool was installed, so the author summarised the speech: the videos
  demonstrate hot-plug and auto-arrangement, and **this must not regress**.

**Result (scope capture):** ~40 % overshoot, ~1 V undershoot below GND and ~20–30 MHz
ringing after every clock edge. The adjacent channel shows ~0.4 V spikes coupled at every
edge (ground bounce/crosstalk).

**Lesson**

- The AD2 analog bandwidth is only ~30 MHz. A long probe ground lead plus dupont wiring
  adds its own LC ringing. Re-measure with a spring ground tip at the receiver pins before
  drawing conclusions about the PCB alone.
- Media dropped in the root can contain unrelated files; check before committing anything.

## 2026-09-26 — Hardware facts extracted from the KiCad project

- `hardware/kicad/module-tile/tastiera_isomorfa.*` is KiCad 9 format (pcb `20241229`,
  sch `20250114`). A single PCB file contains **two boards**:
  - the key board: 12 Cherry MX switches, R110–R133, stacking headers J107/J108;
  - the logic board: U101–U109, inter-tile connectors J101–J104, stacking sockets
    J105/J106.

  They are separated by 68 custom 0.5 mm NPTH footprints called `Senza-titolo` (mouse bites).
- 2 layers, no stackup defined. GND pour on F.Cu and VCC pour on B.Cu, both cut up by
  FreeRouting-autorouted 0.2 mm tracks. A single netclass. Only 2×100 nF + 2×4.7 µF + 100 µF
  of decoupling for 9 ICs.
- Signal directions: clock and latch enter from the bottom/right connectors (J103/J104) and
  are re-buffered outward (U101 → L_clk, U107 → T_clk, U106 → L_latch). Data returns inward
  (U104 Q7 → B_data, which drives **both** J103 and J104). `B_clk` is a 141 mm multi-drop net.
  No driver has a series termination.
- BOM inconsistency: the symbol values (74AUC2G126/125/08, 74HC165, 74LS161) do not match
  the ordered parts (74LVC2G…, SN74LVC165A, SN74HC161). 74AUC is **not rated for 3.3 V**.
  Check the chip markings on a built tile before trusting either list.

## 2026-09-26 — Tooling setup

- **OSS CAD Suite** as a rootless podman image built from
  `tools/containers/oss-cad-suite/Containerfile` (release 2026-09-26):

  ```
  podman build -t localhost/oss-cad-suite:2026-09-26 tools/containers/oss-cad-suite
  podman run --rm --userns=keep-id -v "$PWD":/work:Z -w /work localhost/oss-cad-suite:2026-09-26 make
  ```

  It works. The build of the unmodified rev-A firmware is **deterministic**:
  `hardware.bin` sha256 `e3a7eaf9facde7d328df700aebb1f1d297bbbdcd1ccf5ca79be39f0315fec8d5`.
  3608/5280 LCs (68 %), Fmax 18 MHz at 12 MHz.
  The bitstream committed in git (`c11659f2…`) was built with an older toolchain, so its
  hash differs. **Always compare against the container build, not the committed binary.**
- The `ghdl` calls in the original Makefile have no path prefix, so they rely on `PATH`.
  Inside the container this works because `/opt/oss-cad-suite/bin` is on `PATH`.
- **KiCad**: `flatpak install --user flathub org.kicad.KiCad` installs **KiCad 10.0.6**.
  Flathub only offers the `stable` branch, and there is no easy way to pin 9.x. Decision
  (project owner): **migrate the project to KiCad 10** in one dedicated commit, after rev A
  has been merged into `main`. Until then, use kicad-cli 10 only for read-only checks.
  Never save the v9 files with v10 by accident.
- `kicad-cli` wrapper: `tools/kicad-cli.sh`.
  - Flatpak's `/tmp` is private, so pass host paths with
    `KICAD_EXTRA_FS=/path/a:/path/b`.
  - In zsh, `K="flatpak run …"; $K` fails because zsh does not word-split variables. Use
    the wrapper script instead.
- kicad-cli **rewrites `*.kicad_prl`** even for read-only commands such as ERC/DRC/export.
  Revert it with `git checkout`; it will be ignored by `.gitignore` anyway.
- Alternative kept in reserve: the KiKit container `docker.io/yaqwsx/kikit:v1.8.1-v10`
  (use `-v9` for KiCad 9).

## 2026-09-26 — Baseline checks of rev A (kicad-cli 10.0.6, read-only)

- Netlist export: OK. Kept as the reference for the connectivity-invariant checks.
- ERC: 4 errors `power_pin_not_driven` (no PWR_FLAG). The remaining 201 are warnings:
  122 `lib_symbol_issues` and 75 `footprint_link_issues`, both caused by v9/v10 library
  differences, plus 4 `multiple_net_names`.
- DRC: 0 errors and 0 unconnected items.
  - Warnings: 68 `missing_courtyard` (the mouse-bite footprints) and 67
    `lib_footprint_issues`.
  - Schematic parity: 68 `extra_footprint` (mouse bites have no symbol), 50
    `duplicate_footprints` (the mouse bites reuse `REF**n`) and 67
    `footprint_symbol_field_mismatch`.
- Git tag `rev-a-prototype` → commit `96515e9` (the last commit before any cleanup).

## 2026-09-26 — Phase 1: cleanup, English translation, documentation

**What was done**

- Untracked the generated files and added `.gitignore`. Git history was **not** rewritten.
- Moved folders with `git mv`:
  - `firmware/iCE40_firmware` → `firmware/ice40`
  - `firmware/test_parziali/*` → `firmware/experiments/*`
  - `hardware/kicad/module-tile` → `hardware/kicad/tile`
- Renamed the KiCad project `tastiera_isomorfa` → `isomorphic_tile`. This is a plain `sed`
  over `*.kicad_sch`, `*.kicad_pcb` and `*.kicad_pro`. It also rewrites the
  `(project "…")` instance blocks and the `(sheetfile "…")` references in the PCB. The
  netlist stayed identical.
- Renamed the KiCad field `Codice` → `MPN` and the footprint `Senza-titolo` →
  `MouseBite_NPTH_0.5mm` with text edits. Netlist, invariants and DRC counts are unchanged.
- Translated all comments to English. The firmware Makefile no longer hardcodes
  `~/Pacchetti/...` and no longer calls `sudo`.
- Pruned the vendored open-logic 4.5.0 to the 9 files used and added the upstream
  `License.txt` (PSI HDL Library License 1.0 = LGPL with an FPGA/static-link exception).
- Added `tools/scripts/check_invariants.py`, `tools/scripts/export_reference.sh`,
  `tools/oss.sh` and `tools/kicad-cli.sh`, plus the whole `docs/` tree.

**Result:** after every step the firmware bitstream hash stays at `e3a7eaf9…`, and the
tile netlist is identical to rev A.

**Lesson**

- **Comments and line shifts do not change the bitstream** with this toolchain (checked
  by adding lines at the top of `top.vhd`). The bitstream hash is therefore a valid
  regression check for text-only firmware changes.
- The OSS CAD Suite GHDL (2026-09-26) needs **glibc ≥ 2.38 and a C compiler** to
  elaborate simulations. The `bookworm` base failed with `cc not found`, then with
  `undefined reference to __isoc23_strtol`. Use `debian:trixie-slim` + `gcc libc6-dev
  zlib1g-dev`.
- With `podman --userns=keep-id`, `HOME` points at the work directory. yosys then drops
  `.config/` and `.local/` into the repo. `tools/oss.sh` sets `-e HOME=/tmp`.
- A bare `build/` line in `.gitignore` also ignores `docs/build/`. Anchor such patterns
  (`firmware/**/build/`).
- kicad-cli 10 writes the netlist as multi-line s-expressions. Parsers must be
  whitespace-agnostic (`check_invariants.py` initially found 0 nets).
- Always run a negative test of a checker (move one switch by 0.04 mm, swap one pin) to
  prove that it can fail.

## 2026-09-26 — First SPICE model of the board clock (preliminary)

**Goal:** check whether simulation can show, before fabrication, that rev B is better.

**What was done:** built the ngspice container (`tools/containers/ngspice`, ngspice 44.2)
and wrote `hardware/si/clock_link.py`. The model uses generic parameters:

- pico-ice driver: 20 Ω, 1.5 ns edges;
- 20 cm dupont wire: 200 Ω T-line plus 150 nH of return inductance;
- 70 mm tile track: 100 Ω;
- 30 pF of lumped load.

It sweeps the series resistor Rs at the driver.

**Result (at the tile inputs)**

| Rs | Overshoot | Undershoot | Rise 10–90 % | Falling edge rings back above VIL (0.8 V)? |
|---|---|---|---|---|
| 0 Ω (rev A) | 72 % | −2.4 V | 3.7 ns | **yes, twice (up to 1.7 V) → risk of double clocking** |
| 33 Ω | 40 % | −1.3 V | 4.4 ns | no |
| 68 Ω | 19 % | −0.6 V | 5.3 ns | no |
| 150 Ω | 0 % | +0.05 V | 9.9 ns | no |

- The model rings at about 22 MHz, like the scope (20–30 MHz). The amplitude, however,
  is larger than measured: 72 % vs about 40 %.
- Missing from the model: the input ESD clamp diodes, which limit the undershoot to about
  −0.5 V; conductor and dielectric losses; and the AD2 bandwidth (about 30 MHz, which
  attenuates the peaks).

**Lesson**

- Plain T-lines plus ideal loads over-predict the ringing. Use **IBIS models** of the
  actual parts: TI publishes them for the LVC parts, and the iCE40UP5K model is published
  by Lattice. ngspice/KiCad can use them through KiCad's KIBIS converter.
- Calibrate the model against a clean measurement first (spring ground tip); only then
  compare the rev-B options.
- The scan clock is slow (≈350 kHz), so slowing the edges (Rs ≈ 68–150 Ω into the load
  capacitance) costs nothing in timing. Check the input transition-rate limit in the
  LVC datasheets (Δt/ΔV).
- Only the controller → first-tile link was modelled. The tile → tile hops
  (U101/U107 → connector → neighbour) still need their own model.

## 2026-09-27 — Which logic parts are mounted? (open)

- The project owner does not know the chip markings, and they cannot be read from the
  media: the videos are 474×850 and the ICs are hidden under the key board.
- **Working assumption for rev B: the ordered parts** (74LVC family, SN74HC161; see
  `hardware/fabrication/rev-a/bom.csv`). The rev-B schematic values will state these parts.
  SI models use LVC/HC IBIS data.
- A marking-code table was added to `docs/build/bom.md` so that anyone can check a built
  tile in one minute. Update this entry once a tile has been checked.
- Source: TI datasheets downloaded from `https://www.ti.com/lit/ds/symlink/<part>.pdf`.
  `pdftotext -layout` is available on the host and extracts the "Device Marking" column.

## 2026-09-27 — KiCad 10 migration and SI models with input clamps

- **Migration:** `kicad-cli sch upgrade` on every sheet, plus `pcb upgrade`.
  - Netlist identical, invariants OK, same ERC/DRC counts.
  - Committed on its own on `rev-b`.
- **Library warnings after the migration:** the flatpak starts without global library
  tables, which caused the ERC warnings `lib_symbol_issues` and `footprint_link_issues`.
  Fix, once per machine:
  `cp /app/extensions/Library/template/{sym,fp}-lib-table ~/.var/app/org.kicad.KiCad/config/kicad/10.0/`
  (run inside the flatpak).
  - The library files live on the host in
    `~/.local/share/flatpak/runtime/org.kicad.KiCad.Library.Footprints/x86_64/stable/active/files/footprints`.
- **pcbnew Python API:** available in the flatpak.
  `flatpak run --filesystem=<dir> --command=python3 org.kicad.KiCad script.py` gives
  KiCad 10.0.6 on Python 3.13.
- **Inter-board net lengths (rev A)**, measured with pcbnew:

  | Net | Length | Vias |
  |---|---|---|
  | B_clk | 141 mm | 6 |
  | L_clk | 14 mm | 0 |
  | T_clk | 8 mm | 0 |
  | L_latch | 83 mm | 3 |
  | B_data | 87 mm | 2 |
  | B_W | 34 mm | 0 |
- **SI models now include input clamp diodes.** This changes the picture a lot compared
  with the plain T-line model.
  - `clock_link.py` (pico-ice → first tile over dupont wires):
    - Rs 0 Ω: 26 % overshoot, −0.86 V undershoot;
    - Rs 68 Ω: 19 %, −0.59 V;
    - Rs 150 Ω: 0 %, no undershoot, rise time 9.9 ns;
    - no double threshold crossings in any case.
  - `tile_hop.py` (U101/U107 → connector → neighbour's B_clk tree):
    - rev A (2 layers, about 110 Ω, 141 mm tree): 22 % overshoot, −0.73 V, single
      crossings;
    - rev B (4 layers, about 55 Ω, 100 mm tree) with Rs = 33 Ω: 0 % overshoot, −0.01 V.
- **Conclusion (preliminary, generic models):** rev A is noisy but within the thresholds
  in the model. The ringing on the scope is dominated by the controller link (dupont wires
  + probe).
- **Decisions:**
  - rev B: 33 Ω series resistors at every driver that leaves the tile;
  - controller link: an adapter with about 100–150 Ω series resistance and a GND wire
    next to each signal.
- **Metric pitfall:** "value one ns after the crossing" gives false alarms on slow edges.
  Count threshold crossings instead (a clean edge crosses once).

## 2026-09-27 — Rev-B schematic and scripted PCB transformation

**Schematic** (`hardware/kicad/tile/scripts/revb_schematic.py`, applied once)

- The inter-board hierarchical labels on the driver side became local `*_drv` labels. New
  33 Ω resistors R201–R207 run from those labels to new hierarchical labels with the
  original names, so the root sheet and the connectors are untouched.
- Added C201–C209 (100 nF per IC) and PWR_FLAGs on VCC, GND, VCC_T and GND_T.
- Result: netlist identical to rev A after `--series R201..R207 --ignore C201..C209`.
  ERC: 0 errors (4 in rev A).
- The ERC errors on `VCC_T`/`GND_T` came from **power symbols in the root sheet whose value
  names the net** (`power:VCC` with value `VCC_T`). The PWR_FLAG has to sit on those same
  symbols.

**Key-switch footprint:** `SW_Cherry_MX_1.00u_PCB` (KiCad stock library) has its origin on
**pin 1**, i.e. the centre plus (+2.54, −5.08). The Kailh hot-swap footprint (vendored from
keyswitch-kicad-library v2.3) has its origin on the **centre**.
`check_invariants.py` therefore locates switches by their 4 mm centre hole. The hot-swap
pads 1 and 2 sit where the Cherry pins 2 and 1 were. This is harmless for a switch.

**pcbnew Python API (KiCad 10.0.6) pitfalls, all hit today**

- `board.Remove(item)` → segfault on the next board access. Use `board.Delete(item)`.
- `fp.SetLayerAndFlip()` on a footprint not yet added to the board → segfault.
  `board.Add(fp)` first.
- `zone.SetOutline(SHAPE_POLY_SET(...))` takes ownership of a Python temporary →
  segfault in `SaveBoard`. Append to `zone.Outline()` in place instead.
- `ZONE_FILLER.Fill()` segfaulted right after creating the zones. Call
  `board.BuildConnectivity()` first, and only fill after routing.
- Other API differences:
  - `LIB_ID.Format()` is not callable from Python; use `GetLibNickname()` / `GetLibItemName()`.
  - `FOOTPRINT.GetFieldByName` does not exist; use `HasField` / `GetField` / `SetField`.
    There is no `RemoveField`.
  - `GetBoardPolygonOutlines(outline, infer)` needs 2 arguments.
  - `BOARD_STACKUP` is not exposed, so the stack-up block is written as text into `(setup)`.
- Wrap scripts with `faulthandler.enable()` to get a Python stack when pcbnew segfaults.
- Net-class patterns are wildcards (`*`, `?`) only; `[LTBR]_*` silently matched nothing.

**Tools**

- Freerouting 2.4.1 needs **Java 25** (class file 69). The `eclipse-temurin:21` image fails
  with `UnsupportedClassVersionError`.
- Headless flags: `-de in.dsn -do out.ses -mp N --gui.enabled=false`.
- Layer SVG export for review: `kicad-cli pcb export svg --mode-single --layers ... --fit-page-to-board`,
  then `rsvg-convert` (on the host) to get a PNG.

## 2026-09-27 — Rev-B PCB produced by script + Freerouting

**Result:** 4-layer board. KiCad DRC: **0 errors, 0 unconnected items, 0 schematic-parity
issues**. Remaining warnings: 41 silk over copper, 23 silk overlap, 8 silk-to-edge (these
three are cosmetic), 11 connection width, and 11 library-footprint mismatches (the rev-A
connector footprints come from the v9 library). Switch/connector/outline invariants OK.

**Iterations and lessons**

1. First routing run: 34 unrouted. They were almost all power pads.
   **Freerouting does not connect SMD pads to plane layers.** Fix: a scripted fan-out (stub
   + via) for every SMD power pad, done **before** routing so the router works around the
   vias. Done after routing, U106/U107 pads could not find room.
2. Copper text "TORTIRE v0.1" on B.Cu (rev A) collided with the hot-swap sockets. Moved to
   silkscreen.
3. The placer checked courtyards only. The hot-swap socket **pads stick out of the socket
   courtyard**, so a fiducial landed on a pad. SMD pads are now obstacles too.
4. The left socket pad came 0.06 mm from the stepped outline (SW102/104/106). Local
   footprint variant `SW_Hotswap_Kailh_MX_1.00u_EdgeTrim` with pad 1 trimmed by 0.3 mm on
   the outer side.
5. `R_latch` stayed unrouted twice: U106 pin 2 was boxed in. Placing **U106 at 180°** (its
   inputs facing R106/J104) fixed it. A second Freerouting pass on the routed board did not.
6. J107 (frozen) vs SW111 socket: the courtyards overlapped by 0.1 mm, while the bodies are
   0.49 mm apart. A DRC exclusion in `.kicad_pro` did not match: the key format
   (`type|x|y|uuid|uuid`, marker position in nm) needs the exact marker position, which
   kicad-cli does not print. `pcbnew.WriteDRCReport` from Python asserts outside the GUI
   (`Pgm()`). Instead, the J107 courtyard edge towards the socket was pulled in to a
   0.3 mm margin.
7. `SetField()` creates **visible** silkscreen fields (MPN/Manufacturer showed up on the
   silk). Hide every field except Reference/Value.
8. Board-only items (mouse bites, fiducials): `SetBoardOnly`, `SetAllowMissingCourtyard`,
   excluded from BOM/CPL, unique references MB1..MB68. This cleared 124 parity warnings.
9. Freerouting's own "violations" count (181) did not correspond to KiCad DRC errors.
   **Always judge with KiCad DRC.**

**Rev-B routed lengths:**

| Net | Length |
|---|---|
| B_clk | 141 mm (the two input connectors are far apart) |
| L_clk_drv / L_clk | 2.5 / 17.9 mm |
| T_clk_drv / T_clk | 3.8 / 23.1 mm |
| data_drv | 34 mm (4 vias) |
| latch_drv | 33 mm |

SPICE for the hop as routed, with 33 Ω: 1 % overshoot, −0.03 V undershoot. Rev A: 22 %,
−0.73 V.

**Follow-up (same day):** the placer now places the series resistors **before** the
decoupling caps.

- Every series resistor is now 1.9–2.6 mm (straight line) from its driver pin.
- `data_drv` (53 mm) and `latch_drv` (30 mm) are still long, but only because those nets
  also feed internal inputs (U102.1 column-end detector, U105 latch inverter). The
  inter-board side starts at the resistor.
- The whole PCB is rebuilt in about 3 minutes by
  `hardware/kicad/tile/scripts/revb_pipeline.sh`.
  - Result: DRC 0 errors / 0 unconnected / 0 parity; invariants OK.
  - Remaining warnings: silkscreen cosmetics, 11 library mismatches, 3 connection widths.

**Open for human review:** silkscreen cleanup, 3D stack-height check (C105 is 7.7 mm tall),
C105 MPN, and the clock routing in the GUI.

## 2026-09-27 — Production outputs and panel

- `production.sh` (kicad-cli only) first runs ERC/DRC with `--exit-code-violations
  --severity-error` and stops on errors. It then exports:
  - Gerber X2 for 4 layers, Excellon drill files and drill maps;
  - IPC-2581, BOM, pick-and-place, assembly PDFs, schematic PDF, STEP.
- `zip` is not installed on the host; use `python3 -m zipfile -c`.
- **Pick-and-place pitfall:** the Kailh hot-swap footprint sits on F.Cu, with the socket
  pads on B.Cu. KiCad therefore reports the sockets as `top`. The script rewrites SW*
  rows as `bottom` and `FAB-NOTES.md` asks the assembler to verify their orientation.
  Also use `--smd-only`, so the hand-soldered THT connectors are left out.
- **KiKit** `docker.io/yaqwsx/kikit:v1.8.1-v10` works rootless (it prints a harmless
  wx assert at start-up).
  - Without `--post 'refillzones: true'` the panel has 199 `hole_clearance` errors: the
    old zone fills overlap the new mouse-bite holes.
  - With the refill: panel DRC 0 errors.

## 2026-09-27 — SPICE refinement without new hardware (branch `rev-b`)

- **Digitised the scope photo** (`hardware/si/digitize_scope.py`).
  - Grid lines are detected by colour, and there is a keystone correction (the photo is
    oblique: 215 px/div at the top vs 210 px/div at the bottom).
  - Channel 2 has a +3.6 V display offset.
  - Pitfalls: `np.interp` clamps outside the calibration range (use a linear fit), and the
    WaveForms toolbar has blue/yellow pixels (ignore y < 250 px).
  - Result: levels 3.05 / −0.1 V, overshoot to 3.9 V, undershoot to −1.0 V, ringing
    ~16–20 MHz, and only 10 ns per sample (100 MS/s).
- **Vendor models:** TI IBIS files come from `https://www.ti.com/lit/zip/<id>`. The IDs
  are listed on the product pages: SCEM288 (LVC2G125), SCEM283 (LVC2G126), SCEM216
  (LVC1G04); the `.cir` SPICE models (SCEM6xx) are TINA behavioural models from datasheet
  values, less useful. No IBIS was found for SN74LVC165A or the iCE40UP5K. LVC inputs have
  a GND clamp only.
- `ibis_lite.py`: IBIS → ngspice with B-sources + `pwl()` tables, and linear switching
  coefficients from `[Ramp]`.
- **Bug found and fixed:** my AD2 Butterworth had Q = 1.41 instead of 0.707, so it rang
  by itself (30 % overshoot). Always check a filter's step response
  (now 4.3 % overshoot and 11.4 ns rise, as expected). The first calibration run, done
  with the bad filter, was thrown away.
- **Calibration** (Nelder–Mead on 9 parameters, about 10 minutes): RMS 0.20 V. Several
  parameters hit their bounds, so the model is plausible but not unique.
  - The AD2 views, the node view and the controller-R sweep are in
    `docs/architecture/electrical.md`.
  - Main answers: the spring tip barely matters with a 30 MHz instrument; the real node at
    the first tile rings more than the capture shows; a series resistor at the pico-ice
    (about 100 Ω) fixes the controller link.
- **IBIS tile hop:** rev A far load 76 % overshoot with 7 VIH crossings (pessimistic
  lossless model); rev B with 33 Ω: 14 %, clean. 47 Ω dwells on VIL, so 33 Ω stays.
- **ngspice pitfalls:**
  - Some parameter corners make ngspice crawl. Every run now has a subprocess timeout,
    and the fit treats a timeout as a high cost.
  - A 200 MHz front-end view stalled the solver, so it was dropped (the node view is the
    ideal-instrument reference).
- **Shell pitfall:** `pkill -f <pattern>` / `pgrep -f` also match the invoking shell when
  the pattern appears in the same command line, and exit 144 kills the tool call. Kill by
  PID or with `pgrep -x ngspice`.

## 2026-09-27 — Autorouter comparison: KiCadRoutingTools vs Freerouting (rev B)

- KiCadRoutingTools (KRT, MIT, <https://github.com/drandyhaas/KiCadRoutingTools>) runs
  rootless in `tools/containers/kicad-routing-tools` (prebuilt Rust core downloaded by
  `build_router.py`). Freerouting 2.4.1 runs in `tools/containers/freerouting`.
- Same input for both: the rev-B stage-1 board (placement, planes, power fan-out). Same
  finishing and the same DRC rules afterwards (`production/bench/finish.py`).

  | | KRT (default options) | Freerouting (no optimiser) |
  |---|---|---|
  | Time | ~24 s (routing core 1.8 s) | 100 s |
  | Unconnected | 0 | 1 |
  | Track length | 1843 mm | 1889 mm |

- **KRT's fab check found a real defect in the committed rev B:** 83 vias within 0.2 mm
  of an SMD pad. My fan-out put the via right at the pad edge, and the same-net pads of
  U109 pins 3–6 sat next to each other. Fixed: via centre ≥ half-pad + 0.65 mm, same-net
  pads are obstacles too. New check `tools/scripts/check_via_in_pad.py`, run by the
  pipeline and by `production.sh`. The new rev B has 0.
- KRT caveats:
  - By default it **escalates** (smaller vias, 0.175 mm clearance) and puts **vias in
    pads** to finish. Use `--escalation board`, `--same-net-pad-clearance 0.3` and
    `--hole-to-hole-clearance 0.25`.
  - **Copy the `.kicad_pro` next to the board it reads.** Otherwise it ignores the
    project rules (hole clearance 0.25 → 5 DRC errors) and writes its own `.kicad_pro`.
  - With strict options it leaves 1–2 connections open around U101/U107/U103 on this
    placement, whatever the ordering, grid (0.05 mm), rip-up or pass order. A Freerouting
    "completion pass" on the KRT board did not keep the KRT wiring (it restarted from 128
    unrouted nets). **Decision:** pipeline default `ROUTER=freerouting` (DRC clean);
    `ROUTER=krt` available. Loosen the placement around U101/U107/U103 before switching.
- zsh pitfall: `$BASE:hardware/...` is parsed as the zsh `:h` modifier. Write `${BASE}:...`.
## 2026-09-27 — Rev C study: single-board tile (branch `rev-c`)

- Worked in a separate git worktree (`../isomorphic_keyboard-revc`), so rev-B SI work
  could run in parallel.
- Stack transform logic → key board: (+10.96, −60.90) mm, from the J105/J106 ↔ J107/J108
  pads. Rev A has a 0.04 mm mismatch between the two stacking pairs. Tile lattice:
  right (+80, 0), up (+10, −51.96); mated edge header/socket pads are 13.9 mm apart.
- Folding the logic onto the key-board bottom: the edge connectors at their rev-A/B
  positions produce 61 conflicts (pins under switch bodies, in the 4/3/1.75 mm switch
  holes, on socket pads). **Infeasible with 2.54 mm right-angle headers.**
- The logic parts fit: 40/42 as they are, **42/42** with U109 in TSSOP-16 and C105 as a
  1210 ceramic.
- Free windows along the edges (bottom side), measured by `revc_edges.py`:
  - top edge: 76 mm free at 0.5 mm depth, only 6.2 mm windows at 2 mm depth;
  - bottom edge: 10–27 mm windows;
  - left edges: 8–10 mm windows;
  - right edges: 11–12 mm windows.

  This leads to the concept of passive castellations on top/left and spring contacts on
  bottom/right, at 1.27 mm pitch.
- The route test routes completely: DRC 0 errors / 0 unconnected.
- **Pitfalls:**
  - Freerouting's optimiser can run for a long time after routing is done. Killing it with
    `timeout` leaves no SES at all. Use `--router.optimizer.enabled=false` for feasibility
    runs.
  - When merging nets, map both names to one canonical name (the key-board name, with
    `*_T` rails → main rails). A one-directional map renamed VCC to VCC_T.

## 2026-09-27 — Rev C: through-hole edge connectors ruled out

- Asked: single board, all SMD **except the connectors** (keep THT).
- `revc_tht_search.py` runs an exhaustive search (0.25 mm grid; 1x6 left/right, 1x8
  top/bottom; 2.54 and 1.27 mm pitch). Pads must be on free top-side copper with 0.3 mm
  to the edge, and the bottom needs a clear corridor to the edge. **0 positions everywhere.**
- Pitfall: the first run reported 48–237 "feasible" positions because only the pad
  centre was tested against the outline (pins exactly on the edge). Test the whole pad
  plus edge clearance.

## 2026-09-27 — Rev C rework: minimum equilateral lattice for Cherry MX (work in progress)

- The switch body sets the pitch, not the keycap (keycaps will be custom, 3D printed).
  Cherry MX body is 15.6 × 15.6 mm (0.61", Cherry datasheet); Choc v1 is 15.0 × 15.0 mm
  (Kailh drawing).
- On a triangular lattice the rows are only 0.866 × pitch apart, so the diagonal
  neighbours touch first: pitch ≥ (body + margin) / 0.866. With a 0.3 mm margin:
  **p = 18.36 mm, rows 15.9 mm**. A "squeezed" lattice would allow 15.9 × 15.9 mm, but the
  owner chose the equilateral one (figure: `docs/media/revc-pitch-comparison.png`).
- Hot-swap sockets and switch holes on the bottom are not the limit (clear down to about
  15.5 mm).
- `hardware/kicad/tile/scripts/revc_build.py` builds the concept board:
  - switches re-placed on the new lattice (same topology);
  - stepped outline with 1 mm gaps on every side;
  - lattice right (+73.44, 0), up (+9.18, −47.70);
  - logic folded on the bottom (U103/U104/U109 in TSSOP-16, C105 1210);
  - contact rows replace J101–J104 with the same pin order and nets.
- **Stage 1: all 42 logic parts, 24 resistors, 3 fiducials and 4 contact rows placed.**
- First routing, with 2 signal layers: 11 unconnected. DRC: 30 edge-clearance errors on
  the passive edge pads (fixed by marking them castellated), 3 errors on FID1 (fiducial
  now has a 1 mm clearance), 4 clearance errors, 1 hole-clearance error.
- Second attempt (In2 as a signal layer with a VCC pour): **stopped by the system for low
  memory** during Freerouting. Not re-run yet.
- Lesson: Freerouting in a container plus KiCad in parallel can exhaust RAM on this
  machine. Run one heavy job at a time and don't leave several flatpak/podman jobs in the
  background.
- Re-run with Freerouting capped (`--memory 2500m`, `JAVA_TOOL_OPTIONS=-Xmx1500m`): runs
  fine. The memory pressure came from other programs (opencode about 8.7 GB,
  rust-analyzer, 3 Julia language servers), not from the routing.
- Trial 2 (In2 as a signal layer, VCC pour): 17 unconnected (VCC pour broken into islands);
  the stitching vias shorted In2 tracks because `via_fits` only checked F/B. It now checks
  all four copper layers.
- Trial 3 (solid VCC plane on In2, stubs from the edge pads, fiducial rule areas):
  **13 unconnected, 7 DRC errors.**
  - 5 unconnected + errors: the top passive contacts sit in the 0.67 mm band between the
    top edge and the row-0 sockets. The only ways out are the 3 inter-socket gaps
    (~2.3 mm) + ~1.3 mm at the right end, i.e. 2 contacts per gap at 1.27 mm, 7 in total.
  - 8 unconnected: internal nets. The tile area is fixed by the pitch, so two signal layers
    are not enough.
- **Open decisions (owner):** 7 top/bottom contacts (drop the duplicate GND) or 8 at 1.0 mm
  pitch; 6-layer PCB vs 4 layers.

## 2026-09-27 — Rev C microcontroller tile: first placement

- `revc_mcu_build.py` builds the concept tile:
  - ATtiny1616 at 5 V, 12 keys on internal pull-ups, 4 × 100 Ω edge data lines;
  - 12 SK6812MINI-E reverse-mount LEDs south of each switch, chained;
  - UPDI pad and 5 contacts per edge (VCC GND DATA GND VCC).
- The SOIC-20 wide package (≈13 × 10 mm with pads) does not fit between sockets and
  LEDs; the VQFN-20 3 × 3 mm (0.40 mm pitch, 1.7 mm EP; DS40002204A §39.4) does.
- The Cherry MX drawing puts the LED window **south** of the centre hole and the pins
  (socket) **north**. SK6812MINI-E pins (KiCad symbol): 1 VSS, 2 DIN, 3 VDD, 4 DOUT.
- **Geometric conflict found:** the top contacts can only sit in the gaps between the row-0
  sockets. The up-lattice shift (P/2 = 9.18 mm) maps those x positions exactly onto the
  row-2 key centres, where the reverse-mount LED cut-outs reach within 1 mm of the bottom
  edge. Image: `docs/media/revc-mcu-bottom-conflict.png`.
- Options for the owner: (1) top-side 2 × 2 mm addressable LEDs under the switch window,
  no cut-out, at the cost of two-sided assembly; (2) data-only vertical link (the
  contact still collides, and power distribution breaks for isolated columns);
  (3) no LEDs on the bottom row. Leaning to (1), after checking the MX RGB housing
  clearance.

## 2026-09-27 — GAL experiment (for comparison)

- An EPROM alone is combinational memory: no state, so it cannot replace a counter, a flag
  and shift registers without extra register chips. Its 1980s sibling with registers,
  the GAL/PLD, can.
- `hardware/gal/tile_glue.pld`: the 7 rev-A/B glue ICs in one **ATF22V10C**. galette 0.3.0
  (Rust, open source, container `tools/containers/galette`) assembles it: **10/10
  macrocells used**, JEDEC produced.
- galasm/galette syntax lessons:
  - tri-state outputs need `.T` plus `.E`;
  - in the 22V10 **OE and AR are single product terms**, so there is no OR. T_clk became
    "driven low when unselected", and AR uses the LATCH output feedback.
- Not simulated. Kept as a documented alternative: it gives no LED return path.
- Owner's friend: with a microcontroller tile the PCB can be **2 layers** (no fast
  inter-tile clock any more, low density, the top side is free for a GND pour).
  To confirm when routing the MCU tile.

## 2026-09-27 — Rev C microcontroller tile: 3 contacts, routed on 2 layers

- 3 contacts per edge (VCC, DATA, GND) instead of 5: the top pads fit in the row-0 socket
  gaps, and the bottom springs fall between the row-2 LEDs.
- Routing with KiCadRoutingTools (`revc_mcu_route.sh`). The attempts, in order:
  - Parts packed around the MCU: 13 nets open. Spreading them by function, a 2.5 mm
    placement ring around the VQFN and 0.15 mm clearance brought it to 2.
  - Routers route through the reverse-mount LED cut-outs, so a rule area now fences each
    one. KiCad flagged the library land pattern's pads against their own cut-out;
    a custom rule allows it. `A.Parent.Reference == 'D*'` did not match; the rule
    works with `A.memberOfFootprint('D*')`.
  - GND pours on both sides plus stitching, with VCC routed: GND islands and 3 open VCC
    links.
  - VCC plane on top (KRT `route_planes.py`), GND routed: GND never closed. KRT's default
    layer costs (F.Cu 1, B.Cu 3) also put signals on the plane side and cut it. A sweep of
    layer costs (1/1, 1.5/1, 2/1, 1/2, 3/1, 4/1) gave no clean run.
  - KRT dropped **vias inside boxed-in pads** (LED DOUT, MCU, edge contacts) even with
    `--same-net-pad-clearance 0.3`, and marked them "filled + capped" (IPC-4761 type VII,
    an expensive process). A via-only rule area around every SMD land prevents it. It is
    0.3 mm around every land except the MCU, which needs 0.2 mm or its pins cannot escape.
  - The MCU paste-only sub-pads had been given the GND net; KRT then tried to route pads
    that have no copper. They now have no net.
  - The LED chain in row-major order made a 60 mm link (D4 → D5) across the board. It is
    now a serpentine: every link goes to a neighbour.
  - The repair passes read only the "open" nets. Nets they ripped up and could not restore
    ("ripped_open") stayed broken; the loop now re-queues them, up to 10 passes with
    rotating search settings.
  - **Final scheme:** GND plane on top (the net with the most pads, about 37, reaches it
    with one via each), VCC as tracks on the bottom, GND pour on the bottom stitched to the
    top.
- **Result:** KiCad DRC 0 errors, 0 unconnected; no via within 0.2 mm of a same-net SMD
  pad. Warnings only: silkscreen overlaps, library footprint notes.
- The routed board is kept in `hardware/kicad/revc-mcu-tile/` (`production/` is ignored).
  It still needs a human review in KiCad.

## 2026-09-27 — Rev C MCU tile: KiCad schematic in the flow

- Before this, the tile had no schematic: the build script set the nets on the board
  directly. Now:
  - `revc_mcu_circuit.py` defines the circuit;
  - `revc_mcu_schematic.py` writes a KiCad schematic with the stock symbols embedded
    (`extends` symbols flattened), one stub + global label, power symbol or no-connect
    flag per pin, and stable UUIDs;
  - the board build takes every net, value and field from the netlist `kicad-cli`
    exports, and links each footprint to its symbol;
  - the flow runs ERC and DRC with `--schematic-parity`.
- Parity findings, all fixed:
  - the footprints lacked the symbols' Manufacturer/MPN fields;
  - Description differed;
  - an unused pin must carry KiCad's `unconnected-(...)` net rather than no net.
- Pitfalls:
  - `pcbnew.FootprintLibCreate`/`FootprintSave` find no plugin for a new path, so the
    flow uses `PCB_IO_KICAD_SEXPR()` directly;
  - reference designators changed: C1–C4 (contacts) became J1–J4, C10–C15 became C1–C6,
    and SW101–SW112 became SW1–SW12 in key order.
- Routing after the change was harder, with 1–3 open nets around the MCU in every run and
  every MCU orientation. Fixes:
  - the LED chain now starts at D6, next to the MCU (it used to start at D1, in a corner);
  - **pin swapping**: the 15 interchangeable signals get the MCU pins in the same angular
    order as their destinations. It is stored in `pinmap.json`, drawn in the schematic and
    meant for the firmware;
  - the flow tries the MCU orientations (stored, VDD towards C1, then all four) and keeps
    the first fully clean board.
- The router's results vary from run to run with small changes, hence the search.
- **Result** (MCU at 90°): ERC clean; DRC 0 errors, 0 unconnected, 0 schematic-parity
  issues; no via within 0.2 mm of a same-net SMD pad. The folder
  `hardware/kicad/revc-mcu-tile/` opens as a normal KiCad project.

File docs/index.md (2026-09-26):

# Isomorphic keyboard — documentation

- **Architecture**
  - [Overview](architecture/overview.md): tiles, stacking, controller
  - [Scan protocol and topology discovery](architecture/protocol.md): connector pinout,
    frame format, how the grid is rediscovered on every scan, MIDI mapping
  - [Electrical design](architecture/electrical.md): parts, power, signal integrity
  - [Mechanical design](architecture/mechanical.md): dimensions, key lattice, frozen
    geometry
- **Build**
  - [Firmware](build/firmware.md): toolchain, build, flash, simulation
  - [Hardware](build/hardware.md): KiCad set-up, mandatory checks, tile simulation
  - [Bill of materials](build/bom.md)
  - [Assembly](build/assembly.md)
- [Known issues](known-issues.md)
- [Engineering ledger](LEDGER.md): what was tried, what failed, and why. Read it before
  starting a work session.

## Revisions

| Revision | State | Git |
|---|---|---|
| rev A | working prototype (double-stack tiles, hot-plug, MIDI DIN) | tag `rev-a-prototype` / `rev-a` |
| rev B | signal-integrity fixes and assembly-ready PCB, same function | branch `rev-b` |

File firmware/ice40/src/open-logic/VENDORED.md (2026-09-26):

# Vendored: Open Logic (subset)

- Upstream: https://github.com/open-logic/open-logic
- Version: 4.5.0 (from the `olo_*_dev.core` files of the original full copy)
- License: PSI HDL Library License 1.0 (LGPL v2 or later with an exception for
  static linking / use in FPGA bitstreams), see `License.txt`. The per-file copyright
  headers are kept unchanged.

Only the files used by `../top.vhd` are kept (the full copy is in git history
before the reorganisation):

| File | Used by |
|---|---|
| base/vhdl/olo_base_pkg_{array,attribute,logic,math,string}.vhd | packages |
| base/vhdl/olo_base_strobe_gen.vhd | debounce tick, UART bit timing |
| intf/vhdl/olo_intf_sync.vhd | input synchronisers |
| intf/vhdl/olo_intf_debounce.vhd | 12-channel key debouncers |
| intf/vhdl/olo_intf_uart.vhd | MIDI UART (31250 baud) |

To update: copy the same files from a newer upstream tag, rebuild, and log the new
bitstream hash in docs/LEDGER.md.

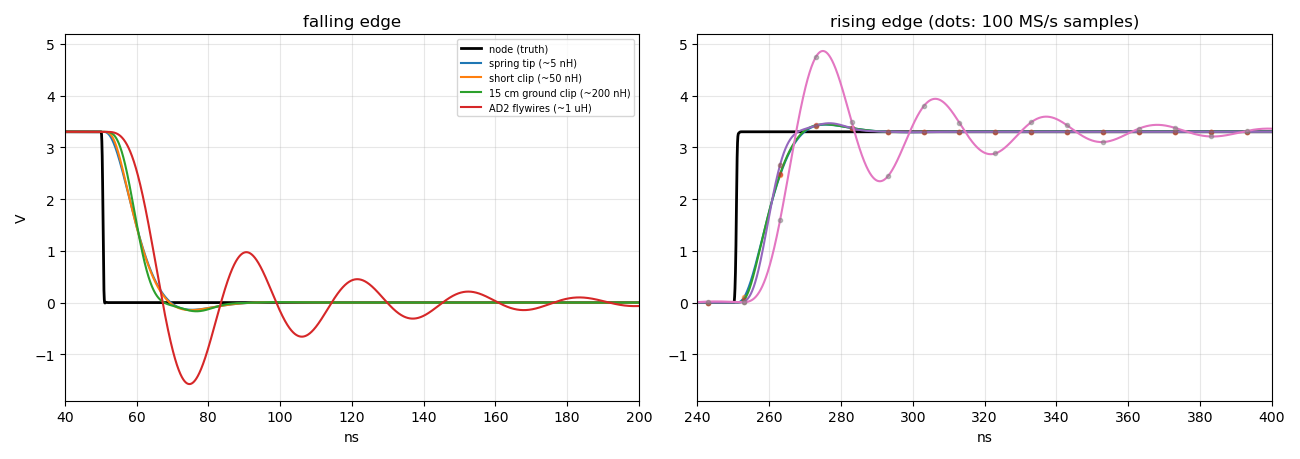
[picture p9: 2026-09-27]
docs/media/si-probe-effect.png

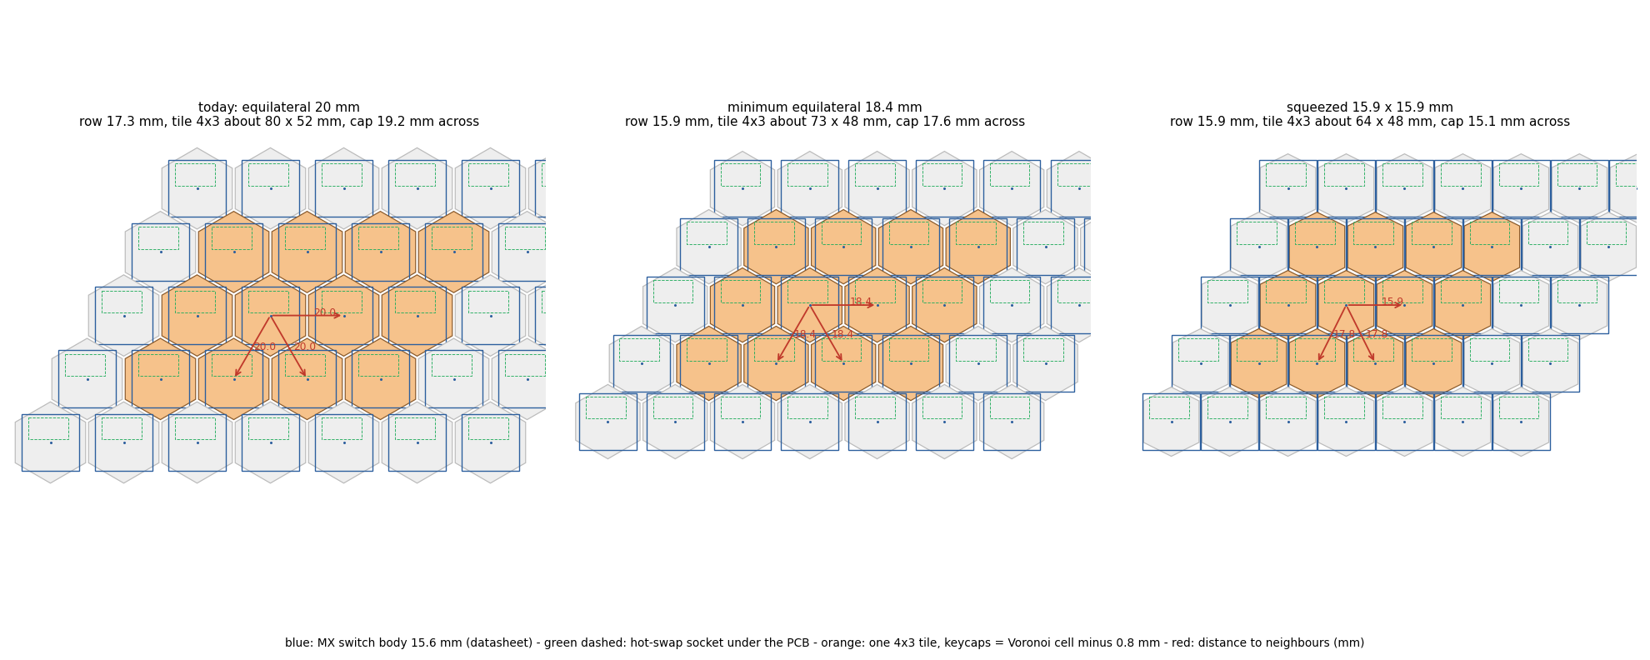
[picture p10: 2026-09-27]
docs/media/revc-pitch-comparison.png

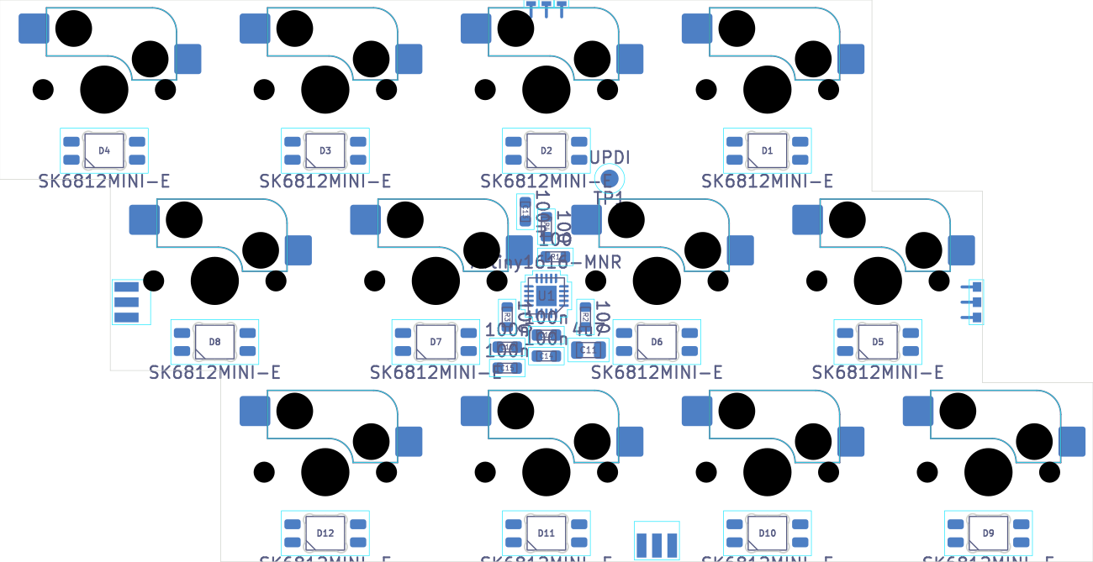
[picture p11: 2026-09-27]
docs/media/revc-mcu-bottom-3contacts.png

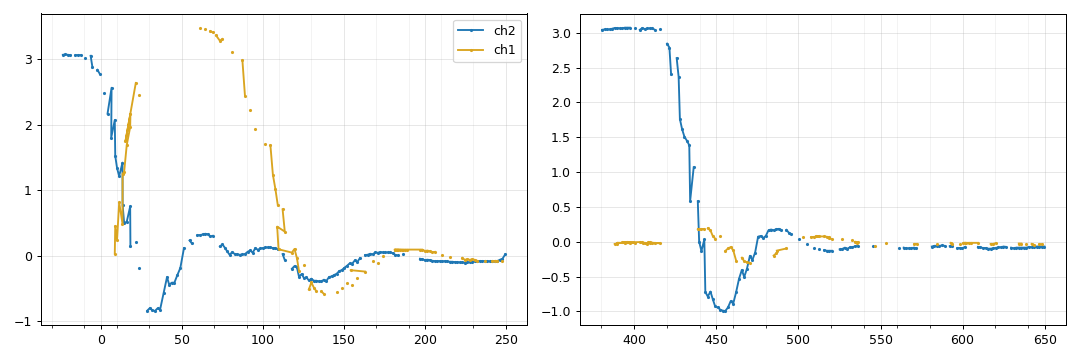
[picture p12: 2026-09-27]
docs/media/si-scope-digitised.png

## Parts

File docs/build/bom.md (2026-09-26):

# Bill of materials (rev A, per tile)

Source: `hardware/fabrication/rev-a/bom.csv`, exported from the rev-A schematic and kept
unchanged as the record of what was ordered. The values below were corrected where the
symbol value disagreed with the ordered part (see [electrical](../architecture/electrical.md)).

| Refs | Qty | Part | MPN (rev A) | Footprint |
|---|---|---|---|---|
| SW101–SW112 | 12 | Cherry MX compatible switch | – | Cherry MX 1u, THT |
| R101–R109, R122–R133 | 21 | 10 kΩ 1 % | RMCF0805FT10K0 | 0805 |
| R110–R121 | 12 | 100 Ω 1 % | CRCW0805100RFKEA | 0805 |
| C101, C102 | 2 | 100 nF X7R 50 V | C0805C104K5RACTU | 0805 |
| C103, C104 | 2 | 4.7 µF X7R 25 V | CL31B475KAHNNNE | 1206 |
| C105 | 1 | 100 µF electrolytic | 860040573004 | radial 6.3 mm, THT |
| U101 | 1 | 2× buffer, OE high | 74LVC2G126DCTRG4 | VSSOP-8 (DCT) |
| U102 | 1 | 2× AND | SN74LVC2G08IDCTRQ1 | VSSOP-8 (DCT) |
| U103, U104 | 2 | 8-bit PISO shift register | SN74LVC165ADR | SOIC-16 |
| U105 | 1 | inverter | SN74LVC1G04DBVR | SOT-23-5 |
| U106 | 1 | 2× OR | SN74LVC2G32DCTR | VSSOP-8 (DCT) |
| U107 | 1 | 2× buffer, OE low | SN74LVC2G125DCTR | VSSOP-8 (DCT) |
| U108 | 1 | D flip-flop | SN74LVC2G74DCTR | VSSOP-8 (DCT) |
| U109 | 1 | 4-bit binary counter | SN74HC161DR | SOIC-16 |
| J101 | 1 | 1×6 socket, 2.54 mm, right angle | 613010143121 | THT |
| J102 | 1 | 1×8 socket, 2.54 mm, right angle | 613010143121 | THT |
| J103 | 1 | 1×8 header, 2.54 mm, right angle | 61300811021 | THT |
| J104 | 1 | 1×6 header, 2.54 mm, right angle | 61300811021 | THT |
| J105, J106 | 2 | 1×8 socket, 2.54 mm, vertical | – | THT |
| J107, J108 | 2 | 1×8 header, 2.54 mm, vertical | – | THT |

The rev-A PCB uses the KiCad `MSOP-8_3x3mm_P0.65mm` footprint for the DCT-package parts.
Rev B will define fields for MPN, manufacturer and alternates on every symbol, and export
the BOM with `kicad-cli` (see [assembly](assembly.md)).

## Identifying the mounted logic parts

Small packages carry a short marking code instead of the part name. The codes below come
from the TI datasheets (package option addendum, fetched 2026-09-27). The marking may
carry an extra date/lot character. Read it with a magnifier or a phone macro photo:

- U101, U104, U107 and U109 are on the **bottom** of the logic board;
- the other ICs are on the top, under the key board.

| Ref | Ordered part (rev A) | Marking if ordered part | Marking if the symbol value was fitted instead |
|---|---|---|---|
| U101 | 74LVC2G126DCTRG4 | `C26` | 74AUC2G126: `U26` |
| U102 | SN74LVC2G08IDCTRQ1 | automotive part, check its own datasheet | 74AUC2G08: `U08` |
| U103, U104 | SN74LVC165ADR | `LVC165A` | 74HC165: `HC165` |
| U105 | SN74LVC1G04DBVR | `C04` + one character | 74AHC1G04: `A04` + one character |
| U106 | SN74LVC2G32DCTR | `C32` | – |
| U107 | SN74LVC2G125DCTR | `C25` | 74AUC2G125: `U25` |
| U108 | SN74LVC2G74DCTR | `C74` | – |
| U109 | SN74HC161DR | `HC161` | 74LS161: `LS161` |

A `U..` code (74AUC) on a 3.3 V tile is out of specification and must be replaced by the
LVC equivalent, which has the same pinout.

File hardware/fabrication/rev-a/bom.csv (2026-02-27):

Reference | Qty | Value | Footprint | Codice | Link
C101,C102 | 2 | 100n | Capacitor_SMD:C_0805_2012Metric_Pad1.18x1.45mm_HandSolder | C0805C104K5RACTU | https://www.digikey.it/it/products/detail/kemet/C0805C104K5RACTU/411169
C103,C104 | 2 | 4u7 | Capacitor_SMD:C_1206_3216Metric_Pad1.33x1.80mm_HandSolder | CL31B475KAHNNNE | https://www.digikey.it/it/products/detail/samsung-electro-mechanics/CL31B475KAHNNNE/3886713
C105 | 1 | 100u | Capacitor_THT:CP_Radial_D6.3mm_P2.50mm | 860040573004 | https://www.digikey.it/it/products/detail/w%C3%BCrth-elektronik/860040573004/5727450
J101 | 1 | Conn_LEFT | Connector_PinSocket_2.54mm:PinSocket_1x06_P2.54mm_Horizontal | 613010143121 | https://www.digikey.it/it/products/detail/w%C3%BCrth-elektronik/613010143121/2508632
J102 | 1 | Conn_TOP | Connector_PinSocket_2.54mm:PinSocket_1x08_P2.54mm_Horizontal | 613010143121 | https://www.digikey.it/it/products/detail/w%C3%BCrth-elektronik/613010143121/2508632
J103 | 1 | Conn_BOTTOM | Connector_PinHeader_2.54mm:PinHeader_1x08_P2.54mm_Horizontal | 61300811021 | https://www.digikey.it/it/products/detail/w%C3%BCrth-elektronik/61300811021/4846838
J104 | 1 | Conn_RIGHT | Connector_PinHeader_2.54mm:PinHeader_1x06_P2.54mm_Horizontal | 61300811021 | https://www.digikey.it/it/products/detail/w%C3%BCrth-elektronik/61300811021/4846838
J105 | 1 | BTNs_L_MSB | Connector_PinSocket_2.54mm:PinSocket_1x08_P2.54mm_Vertical
J106 | 1 | BTNs_L_LSB | Connector_PinSocket_2.54mm:PinSocket_1x08_P2.54mm_Vertical
J107 | 1 | BTNs_MSB | Connector_PinHeader_2.54mm:PinHeader_1x08_P2.54mm_Vertical
J108 | 1 | BTNs_LSB | Connector_PinHeader_2.54mm:PinHeader_1x08_P2.54mm_Vertical
R101,R102,R103,R104,R105,R106,R107,R108,R109,R122,R123,R124,R125,R126,R127,R128,R129,R130,R131,R132,R133 | 21 | 10k | Resistor_SMD:R_0805_2012Metric_Pad1.20x1.40mm_HandSolder | RMCF0805FT10K0 | https://www.digikey.it/it/products/detail/stackpole-electronics-inc/RMCF0805FT10K0/1760676
R110,R111,R112,R113,R114,R115,R116,R117,R118,R119,R120,R121 | 12 | 100R | Resistor_SMD:R_0805_2012Metric_Pad1.20x1.40mm_HandSolder | CRCW0805100RFKEA | https://www.digikey.it/it/products/detail/vishay-dale/CRCW0805100RFKEA/1175523
SW101,SW102,SW103,SW104,SW105,SW106,SW107,SW108,SW109,SW110,SW111,SW112 | 12 | SW_Push | Button_Switch_Keyboard:SW_Cherry_MX_1.00u_PCB
U101 | 1 | 74AUC2G126 | Package_SO:MSOP-8_3x3mm_P0.65mm | 74LVC2G126DCTRG4 | https://www.digikey.it/it/products/detail/texas-instruments/74LVC2G126DCTRG4/2047054
U102 | 1 | 74AUC2G08 | Package_SO:MSOP-8_3x3mm_P0.65mm | SN74LVC2G08IDCTRQ1 | https://www.digikey.it/it/products/detail/texas-instruments/SN74LVC2G08IDCTRQ1/1592267
U103,U104 | 2 | 74HC165 | Package_SO:SOIC-16_3.9x9.9mm_P1.27mm | SN74LVC165ADR | https://www.digikey.it/it/products/detail/texas-instruments/SN74LVC165ADR/26490310
U105 | 1 | 74AHC1G04 | Package_TO_SOT_SMD:SOT-23-5_HandSoldering | SN74LVC1G04DBVR | https://www.digikey.it/it/products/detail/texas-instruments/SN74LVC1G04DBVR/385716
U106 | 1 | 74LVC2G32 | Package_SO:MSOP-8_3x3mm_P0.65mm | SN74LVC2G32DCTR | https://www.digikey.it/it/products/detail/texas-instruments/SN74LVC2G32DCTR/484828
U107 | 1 | 74AUC2G125 | Package_SO:MSOP-8_3x3mm_P0.65mm | SN74LVC2G125DCTR | https://www.digikey.it/it/products/detail/texas-instruments/SN74LVC2G125DCTR/412008
U108 | 1 | 74LVC2G74 | Package_SO:MSOP-8_3x3mm_P0.65mm | SN74LVC2G74DCTR | https://www.digikey.it/it/products/detail/texas-instruments/SN74LVC2G74DCTR/484721
U109 | 1 | 74LS161 | Package_SO:SOIC-16_3.9x9.9mm_P1.27mm | SN74HC161DR | https://www.digikey.it/it/products/detail/texas-instruments/SN74HC161DR/562878

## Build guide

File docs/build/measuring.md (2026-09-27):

# Measuring the tile signals (Analog Discovery 2)

The 2026-06-15 capture (`hardware/si/measurements/`) showed about 27 % overshoot, −1.0 V
undershoot and 16–20 MHz ringing on the board clock. The simulations in `hardware/si/`
separate what the tile really does from what the measurement adds.

## What the instrument can and cannot show

- The AD2 analog inputs have about 30 MHz of bandwidth: the displayed **10–90 % rise time
  is about 11 ns**, even for a 1 ns edge. The LVC parts switch in about 0.5–1 ns, so the AD2
  never shows the real edge or the real overshoot peak. It shows a smoothed version.
- At 100 MS/s there is one sample every 10 ns, i.e. 2–5 samples per ringing period. What
  WaveForms draws between the samples is interpolation.
- The probe ground loop forms an LC resonator with the 24 pF input. Simulated view of
  a **clean** edge (`probe_effect.py`):

| Probe connection | Apparent overshoot | Apparent undershoot |
|---|---|---|
| spring ground tip (~5 nH) | 4 % | −0.14 V |
| short ground clip (~50 nH) | 4 % | −0.15 V |
| 15 cm ground clip (~200 nH) | 5 % | −0.17 V |
| AD2 flywires, signal + ground (~1 µH loop) | **47 %** | **−1.57 V** |

The first three rows are simply the AD2 front end (a 30 MHz Butterworth has 4 %
overshoot). With a 30 MHz instrument, a spring tip is not a big improvement over a short
clip. **The flywire loop, however, invents ringing of the same size as the one in the
capture.**

## Recipe for a meaningful measurement

1. Use the AD2 **BNC adapter + a 10× passive probe**, not the flywires. Connect the probe
   ground with the **spring tip or a clip shorter than 3 cm**, to a GND pin next to the
   signal. On the edge connectors, the GND pins are J103.4/J103.8 and J101.6.
2. Probe **at the receiving pins**, not at the connector:
   - clock: U103/U104 pin 2 and U109 pin 2 of the **far** tile;
   - latch: U105 pin 2.
3. Set the probe to 10× in WaveForms and trigger on the channel itself.
4. Read the result against the simulated AD2 view (`fit_measurement.py` prints it), **not**
   against the node voltage. With a 30 MHz front end a clean rev-B edge looks like a ~11 ns
   ramp with ~4 % overshoot.
5. For the real overshoot of a 1 ns edge you need at least 300–500 MHz of bandwidth, e.g. a
   borrowed lab scope. Only then compare with `tile_hop_ibis.py`.
6. Functional check without any scope: the red LED of the pico-ice lights on a framing
   error (sticky). Leave the instrument scanning for 10 minutes while plugging and
   unplugging tiles. No red LED means no double-clocked frames.

## Test points for rev B (suggestion)

A 2-pin 1.27 mm footprint (signal + GND) next to the far `B_clk` load and next to U105
pin 2 would allow a spring-tip measurement without clip leads. It is a non-functional
PCB addition and can be added in the GUI review.

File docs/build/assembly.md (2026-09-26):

# Assembly

## Rev A (hand assembly)

- SMD parts sit on **both sides of both boards**, with hand-solder footprints.
  Assemble the SMD parts first and the THT parts last (switches, edge connectors,
  stacking connectors, C105).
- Snap the key board off the logic board along the mouse bites before soldering the
  stacking connectors.
- The edge connectors must sit flush and square to the board edge. Tiles that are not
  aligned stress the neighbouring connectors.

## Rev B (automated assembly, branch `rev-b`)

Goals, with switch/connector positions, outlines, pinouts and logic parts unchanged:

- all SMD parts of each board on a single side;
- standard (not hand-solder) footprints;
- no THT electrolytic capacitor;
- Kailh MX hot-swap sockets (SMD) on the key board, so the switches are inserted by hand
  after reflow;
- fiducials and a KiKit panel with rails and tooling holes;
- a generic, assembler-neutral output set generated by `kicad-cli`: Gerber X2 + drill,
  IPC-2581/ODB++, a BOM with MPNs, a pick-and-place file, assembly drawings, and fab notes
  (stack-up, impedance, finish).

Status on `rev-b`:

- [x] Key board: every SMD part on **B.Cu** (12 Kailh sockets `CPG151101S11`, R110–R133).
- [x] Logic board: every SMD part on **F.Cu**.
- [x] 0603 passives, TI DCT land pattern (`SSOP-8_2.95x2.8mm_P0.65mm`), SOT-23-5,
  SMD 100 µF (6.3 × 7.7 mm).
- [x] 3 fiducials per board (FID1–3 on the key board, B side; FID4–6 on the logic board,
  F side).
- [x] MPN and Manufacturer fields on every part. **C105 still needs an MPN**
  (100 µF, ≥ 10 V, SMD aluminium, 6.3 × 7.7 mm).
- [x] Assembly panel: `hardware/kicad/tile/scripts/panel.sh` (KiKit, rootless). Two
  tiles, 5 mm rails, 3 tooling holes, 3 panel fiducials, mouse-bite tabs; panel DRC
  0 errors.
- [x] Output set: `hardware/kicad/tile/scripts/production.sh`, which covers Gerber X2,
  drill, IPC-2581, BOM, pick-and-place, assembly PDFs, STEP and fab notes
  (`docs/build/fab-notes.md`).

The THT edge and stacking connectors remain a manual or selective-solder step.

Mechanical check still to do on the 3D model: stacked height with C105 (7.7 mm) on the
logic board top under the key board sockets, and the J107/SW111 clearance. The bodies are
about 0.5 mm apart; the J107 courtyard was pulled in to a 0.3 mm margin.

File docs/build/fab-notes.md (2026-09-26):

# Fabrication notes — isomorphic tile, rev B

| Item | Value |
|---|---|
| Layers | 4 (F.Cu signal / In1.Cu GND planes / In2.Cu VCC planes / B.Cu signal) |
| Thickness | 1.6 mm, FR-4, Tg ≥ 150 °C |
| Stack-up | 35 µm Cu / 0.21 mm prepreg / 15 µm Cu / 1.065 mm core / 15 µm Cu / 0.21 mm prepreg / 35 µm Cu |
| Impedance | not controlled by the fab; 0.3 mm outer tracks are ~55 Ω by design, ±15 % is fine |
| Min track / space | 0.15 mm / 0.2 mm |
| Min drill / via | 0.3 mm drill, 0.6 mm pad |
| Finish | ENIG |
| Solder mask / silkscreen | both sides / both sides |
| Outline | two boards (key board + logic board) joined by two tabs with 0.5 mm NPTH mouse bites; do not rout the tabs |
| Assembly | key board: SMD on **bottom** only (Kailh hot-swap sockets, 0603); logic board: SMD on **top** only; THT connectors hand/selective soldered after reflow |
| Fiducials | 1 mm copper, 2 mm mask opening: FID1–3 (key board, bottom), FID4–6 (logic board, top) |

## Assembly notes

- `assembly/pick_and_place.csv` contains SMD parts only; board coordinates in mm, viewed
  from the top, KiCad rotation convention.
- **SW101–SW112 are the Kailh CPG151101S11 hot-swap sockets, soldered on the bottom
  side.** Their footprint lives on the top layer (the switch is inserted from the top),
  so the position file rewrites them as `bottom`. Please verify their orientation against
  `assembly/assembly_bottom.pdf` during DFM.
- Not assembled by machine (hand/selective solder after reflow): J101–J104 (right-angle
  edge connectors), J105/J106 (vertical sockets, logic board top), J107/J108 (vertical
  headers, key board bottom). The MX switches are inserted by the user.
- Parts without an MPN yet: C105 (100 µF ≥ 10 V SMD aluminium, 6.3 × 7.7 mm) and
  J105–J108 (2.54 mm 1×8 vertical socket/header; the mated height sets the gap between the
  boards).

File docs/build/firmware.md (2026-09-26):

# Building and flashing the firmware

The controller firmware lives in `firmware/ice40/` and targets the **pico-ice**
(Lattice iCE40UP5K-SG48, 12 MHz clock), using the open-source flow:
GHDL + yosys (ghdl plugin) → nextpnr-ice40 → icepack.

## Toolchain

Pick one option:

1. **Rootless container (recommended, reproducible)**

   ```sh
   podman build -t localhost/oss-cad-suite:2026-09-26 tools/containers/oss-cad-suite
   cd firmware/ice40
   ../../tools/oss.sh make            # bitstream in build/hardware.bin
   ../../tools/oss.sh make sim        # GHDL simulation of sim/top_tb.vhd
   ```

2. **Local OSS CAD Suite:** `make OSS_CAD_SUITE=/path/to/oss-cad-suite`.
3. **Tools already on `PATH`:** `make`.

With the container image `oss-cad-suite:2026-09-26`, the reference bitstream of rev A has
sha256 `e3a7eaf9facde7d328df700aebb1f1d297bbbdcd1ccf5ca79be39f0315fec8d5`. A change that is
meant to be behaviour-neutral (comments, renames, refactoring) must reproduce this hash.

## Pinout (`constraints/up5k.pcf`)

| Signal | iCE40 pin | Function |
|---|---|---|
| `CLK_IN` | 35 | 12 MHz clock |
| `RESET_N` | 10 | reset button, active low |
| `BOARD_CLK` | 31 | scan clock → J103.2 of the first tile |
| `BOARD_LATCH` | 38 | latch → J103.6 |
| `BOARD_DATA` | 34 | serial data ← J103.3 |
| `PACKAGE_MIDI` | 21 | MIDI TX (inverted, to the DIN interface) |
| `LED_BLUE` / `LED_RED` / `LED_GREEN` | 40 / 41 / 39 | error of the main / scan / serializer FSM (active low) |

The tile ground and 3.3 V (J103.4/8 and J103.1) must come from the pico-ice as well.

## Flashing

`make upload-flash` (persistent, DFU alt 0) or `make upload-ram` (volatile, DFU alt 1)
uses `dfu-util`. When several boards are attached, select one with
`PICO_ICE_SERIAL=<serial>`. No `sudo` is needed once this udev rule is installed (one-time,
by an administrator):

```
# /etc/udev/rules.d/70-pico-ice.rules
SUBSYSTEM=="usb", ATTRS{idVendor}=="1209", ATTRS{idProduct}=="b1c0", MODE="0660", TAG+="uaccess"
```

Flashing through the container requires passing the USB device through
(`podman run --device /dev/bus/usb ...`). It is simpler to run `dfu-util` from the host.

## Simulation

- `make sim TB=top_tb STOP_TIME=15ms` builds and runs a testbench in `sim/build/`.
- `make wave` opens the waveform in GTKWave (`sim/gtkwave_dashboards/*.gtkw` hold saved
  views).

## Experiments

`firmware/experiments/` holds the earlier bring-up designs: I2C on the pico-ice, a slow
tile scan, and a slow scan with I2C output. They are kept for reference, and each builds
on its own with `make` in its folder.

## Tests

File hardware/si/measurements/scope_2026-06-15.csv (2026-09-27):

t_ns | ch1_V | ch2_V
-514.046 | nan | 3.075
-512.484 | nan | 3.075
-510.960 | nan | 3.065
-509.358 | nan | 3.075
-507.815 | nan | 3.070
-517.988 | nan | nan
-516.411 | nan | nan
-514.834 | nan | nan
-513.258 | nan | nan
-511.681 | nan | nan
-510.105 | nan | nan
-508.528 | nan | nan
-506.952 | nan | nan
-493.750 | nan | 3.070
-503.798 | nan | nan
-502.222 | nan | nan
-489.062 | nan | 3.070
-487.499 | nan | 3.070
-497.492 | nan | nan
-495.916 | nan | nan
-494.339 | nan | nan
-492.762 | nan | nan
-491.186 | nan | nan
-489.609 | nan | nan
-488.033 | nan | nan
-486.456 | nan | nan
-484.880 | nan | nan
-471.853 | nan | 3.075
-470.253 | nan | 3.085
-493.904 | -0.005 | nan
-478.573 | nan | nan
-476.997 | nan | nan
-464.077 | nan | 3.065
-487.531 | -0.005 | nan
-472.267 | nan | nan
-470.690 | nan | nan
-469.114 | nan | nan
-467.537 | nan | nan
-465.961 | nan | nan
-464.384 | nan | nan
-462.808 | nan | nan
-461.231 | nan | nan
-448.431 | nan | 3.070
-446.869 | nan | 3.070
-456.501 | nan | nan
-443.725 | nan | 3.075
-442.144 | nan | 3.080
-440.581 | nan | 3.080
-439.018 | nan | 3.080
-437.456 | nan | 3.080
-435.893 | nan | 3.080
-434.330 | nan | 3.080
-432.768 | nan | 3.080
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

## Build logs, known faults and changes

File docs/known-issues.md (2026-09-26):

# Known issues

Issues found while documenting rev A. Items marked *frozen* are deliberately **not** fixed
during the rev-B hardware work, because the functional behaviour is frozen. They are
candidates for a later firmware release.

## Firmware (`firmware/ice40/src/top.vhd`)

- *frozen* — **Tile slot 0 is never used.** `tile_counter` is incremented in state `r2`
  before the first `load`, so the first tile is stored in slot 1. With
  `keyboard_t` = `array (0 to 9)`, 9 tiles fit and a 10th would index out of range.
- *frozen* — **The framing error is sticky.** When the two marker bits are not `11`, the
  pull FSM stays in `err` (red LED) until a reset. A glitch on the board clock, such as a
  double-clocked shift register caused by ringing, stops the scan. This makes signal
  integrity visible to the player.
- *frozen* — `main_fsm` never reaches `done`, and the states `s1`/`s2` of the pull FSM are
  unused.
- The comment on `ref_pitch` said 96 = C7; the value is 60 = C4. The comment has been fixed.

## Hardware (rev A)

- The symbol values do not match the ordered parts (74AUC/74HC/74LS vs 74LVC/SN74HC).
  74AUC is not rated for 3.3 V. Check the chip markings on a built tile.
- There is no series termination on the inter-board drivers, and decoupling is limited.
  See [electrical](architecture/electrical.md).
- The ERC reports 4 errors `power_pin_not_driven`, because there is no PWR_FLAG on
  VCC/GND.
- The mouse-bite footprints have no courtyard and share `REF**n` references. They cause
  186 DRC/parity warnings.
- Components sit on both sides of both boards, which forces double-sided assembly.

## Repository

- History before the 2026-09 cleanup contains large generated files (bitstreams,
  waveforms, KiCad backups). The history was deliberately not rewritten.

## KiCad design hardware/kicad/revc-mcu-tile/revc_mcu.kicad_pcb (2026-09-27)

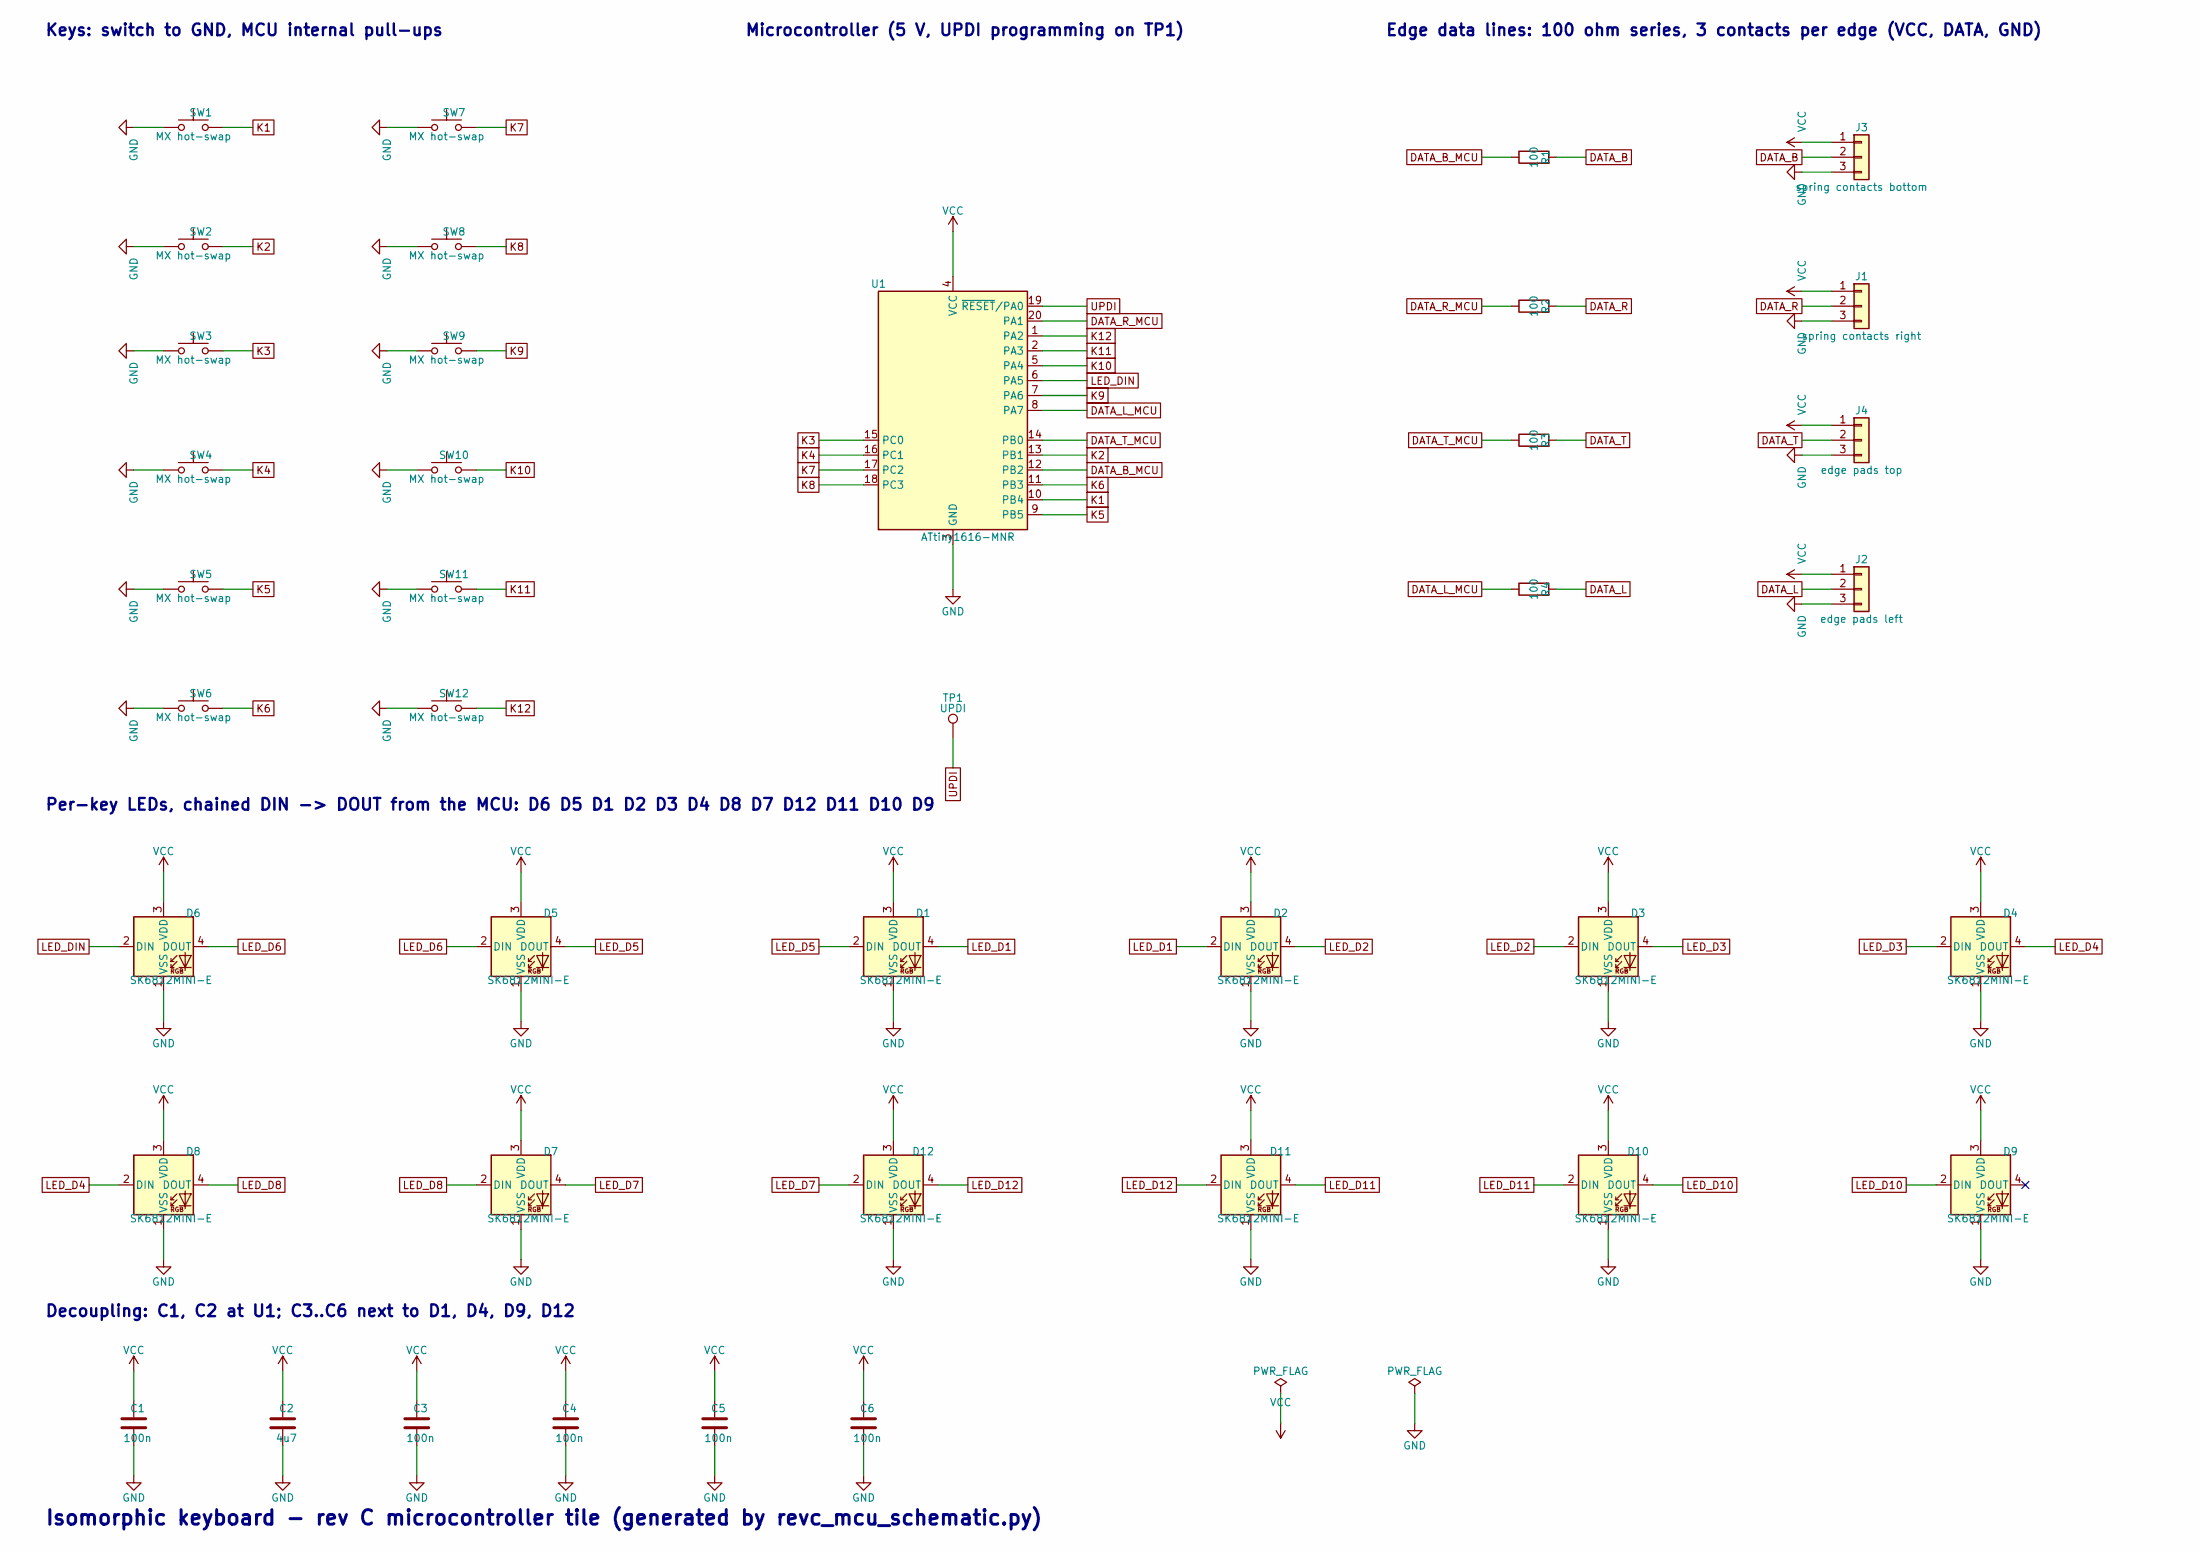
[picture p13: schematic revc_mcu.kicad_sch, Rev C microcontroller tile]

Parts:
C1, C3, C4, C5, C6: 100n; C_0603_1608Metric; MPN CL10B104KB8NNNC
C2: 4u7; C_0805_2012Metric; MPN CL21A475KAQNNNE
D1, D2, D3, D4, D5, D6, D7, D8, D9, D10, D11, D12: SK6812MINI-E; LED_SK6812MINI-E_3.2x2.8mm_P1.5mm_ReverseMount; MPN SK6812MINI-E
J1: spring contacts right; EdgeContacts_right
J2: edge pads left; EdgeContacts_left
J3: spring contacts bottom; EdgeContacts_bottom
J4: edge pads top; EdgeContacts_top
R1, R2, R3, R4: 100; R_0603_1608Metric; MPN RC0603FR-07100RL
SW1, SW2, SW3, SW4, SW5, SW6, SW7, SW8, SW9, SW10, SW11, SW12: MX hot-swap; SW_Hotswap_Kailh_MX_1.00u_EdgeTrim; MPN CPG151101S11
TP1: UPDI; TestPoint_Pad_D1.5mm
U1: ATtiny1616-MNR; VQFN-20-1EP_3x3mm_P0.4mm_EP1.7x1.7mm; MPN ATTINY1616-MNR

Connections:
DATA_B: J3.2, R1.2
DATA_B_MCU: R1.1, U1.12 (PB2)
DATA_L: J2.2, R4.2
DATA_L_MCU: R4.1, U1.8 (PA7)
DATA_R: J1.2, R2.2
DATA_R_MCU: R2.1, U1.20 (PA1)
DATA_T: J4.2, R3.2
DATA_T_MCU: R3.1, U1.14 (PB0)
GND: C1.2, C2.2, C3.2, C4.2, C5.2, C6.2, D1.1 (VSS), D2.1 (VSS), D3.1 (VSS), D4.1 (VSS), D5.1 (VSS), D6.1 (VSS), D7.1 (VSS), D8.1 (VSS), D9.1 (VSS), D10.1 (VSS), D11.1 (VSS), D12.1 (VSS), J1.3, J2.3, J3.3, J4.3, SW1.1, SW2.1, SW3.1, SW4.1, SW5.1, SW6.1, SW7.1, SW8.1, SW9.1, SW10.1, SW11.1, SW12.1, U1.3 (GND), U1.21 (GND)
K1: SW1.2, U1.10 (PB4)
K2: SW2.2, U1.13 (PB1)
K3: SW3.2, U1.15 (PC0)
K4: SW4.2, U1.16 (PC1)
K5: SW5.2, U1.9 (PB5)
K6: SW6.2, U1.11 (PB3)
K7: SW7.2, U1.17 (PC2)
K8: SW8.2, U1.18 (PC3)
K9: SW9.2, U1.7 (PA6)
K10: SW10.2, U1.5 (PA4)
K11: SW11.2, U1.2 (PA3)
K12: SW12.2, U1.1 (PA2)
LED_D1: D1.4 (DOUT), D2.2 (DIN)
LED_D2: D2.4 (DOUT), D3.2 (DIN)
LED_D3: D3.4 (DOUT), D4.2 (DIN)
LED_D4: D4.4 (DOUT), D8.2 (DIN)
LED_D5: D1.2 (DIN), D5.4 (DOUT)
LED_D6: D5.2 (DIN), D6.4 (DOUT)
LED_D7: D7.4 (DOUT), D12.2 (DIN)
LED_D8: D7.2 (DIN), D8.4 (DOUT)
LED_D10: D9.2 (DIN), D10.4 (DOUT)
LED_D11: D10.2 (DIN), D11.4 (DOUT)
LED_D12: D11.2 (DIN), D12.4 (DOUT)
LED_DIN: D6.2 (DIN), U1.6 (PA5)
UPDI: TP1.1, U1.19 (~RESET/PA0)
VCC: C1.1, C2.1, C3.1, C4.1, C5.1, C6.1, D1.3 (VDD), D2.3 (VDD), D3.3 (VDD), D4.3 (VDD), D5.3 (VDD), D6.3 (VDD), D7.3 (VDD), D8.3 (VDD), D9.3 (VDD), D10.3 (VDD), D11.3 (VDD), D12.3 (VDD), J1.1, J2.1, J3.1, J4.1, U1.4 (VCC)

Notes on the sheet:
Keys: switch to GND, MCU internal pull-ups
Microcontroller (5 V, UPDI programming on TP1)
Edge data lines: 100 ohm series, 3 contacts per edge (VCC, DATA, GND)
Per-key LEDs, chained DIN -> DOUT from the MCU: D6 D5 D1 D2 D3 D4 D8 D7 D12 D11 D10 D9
Decoupling: C1, C2 at U1; C3..C6 next to D1, D4, D9, D12
Isomorphic keyboard - rev C microcontroller tile (generated by revc_mcu_schematic.py)

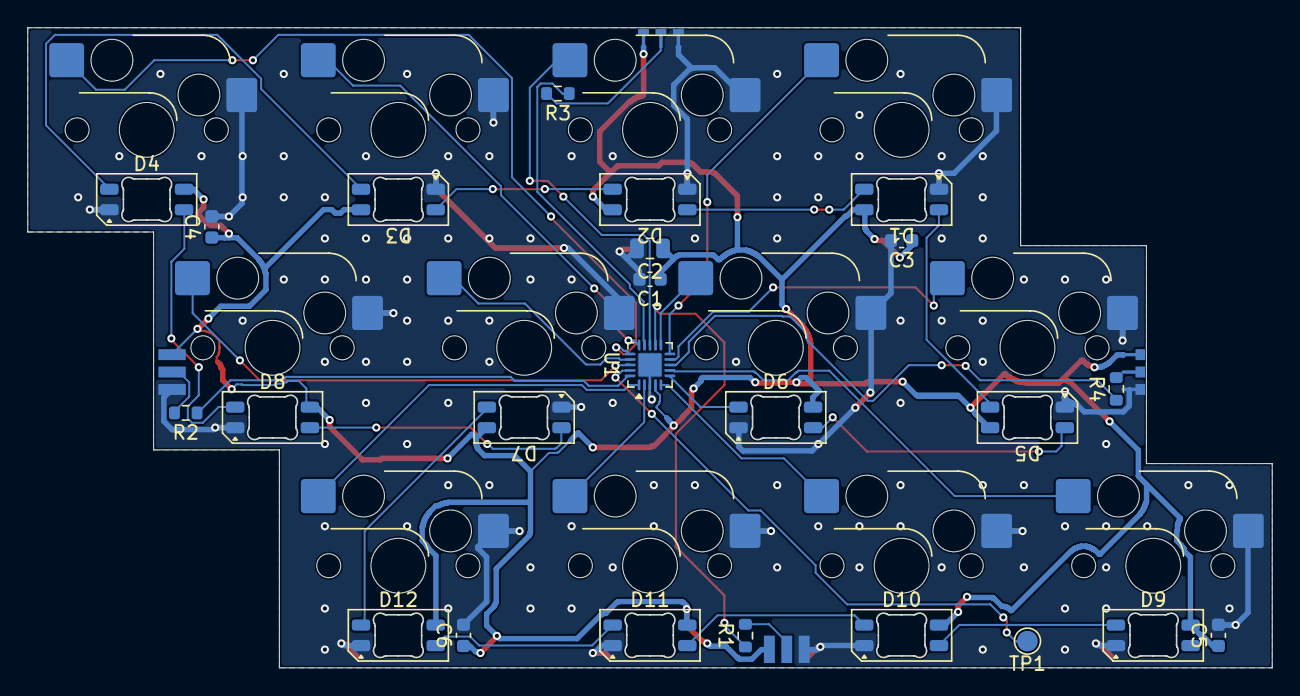
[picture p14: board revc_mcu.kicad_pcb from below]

Board: 2 copper layers, 90.8 x 46.7 mm, 40 parts (28 on the bottom side), 35 nets.

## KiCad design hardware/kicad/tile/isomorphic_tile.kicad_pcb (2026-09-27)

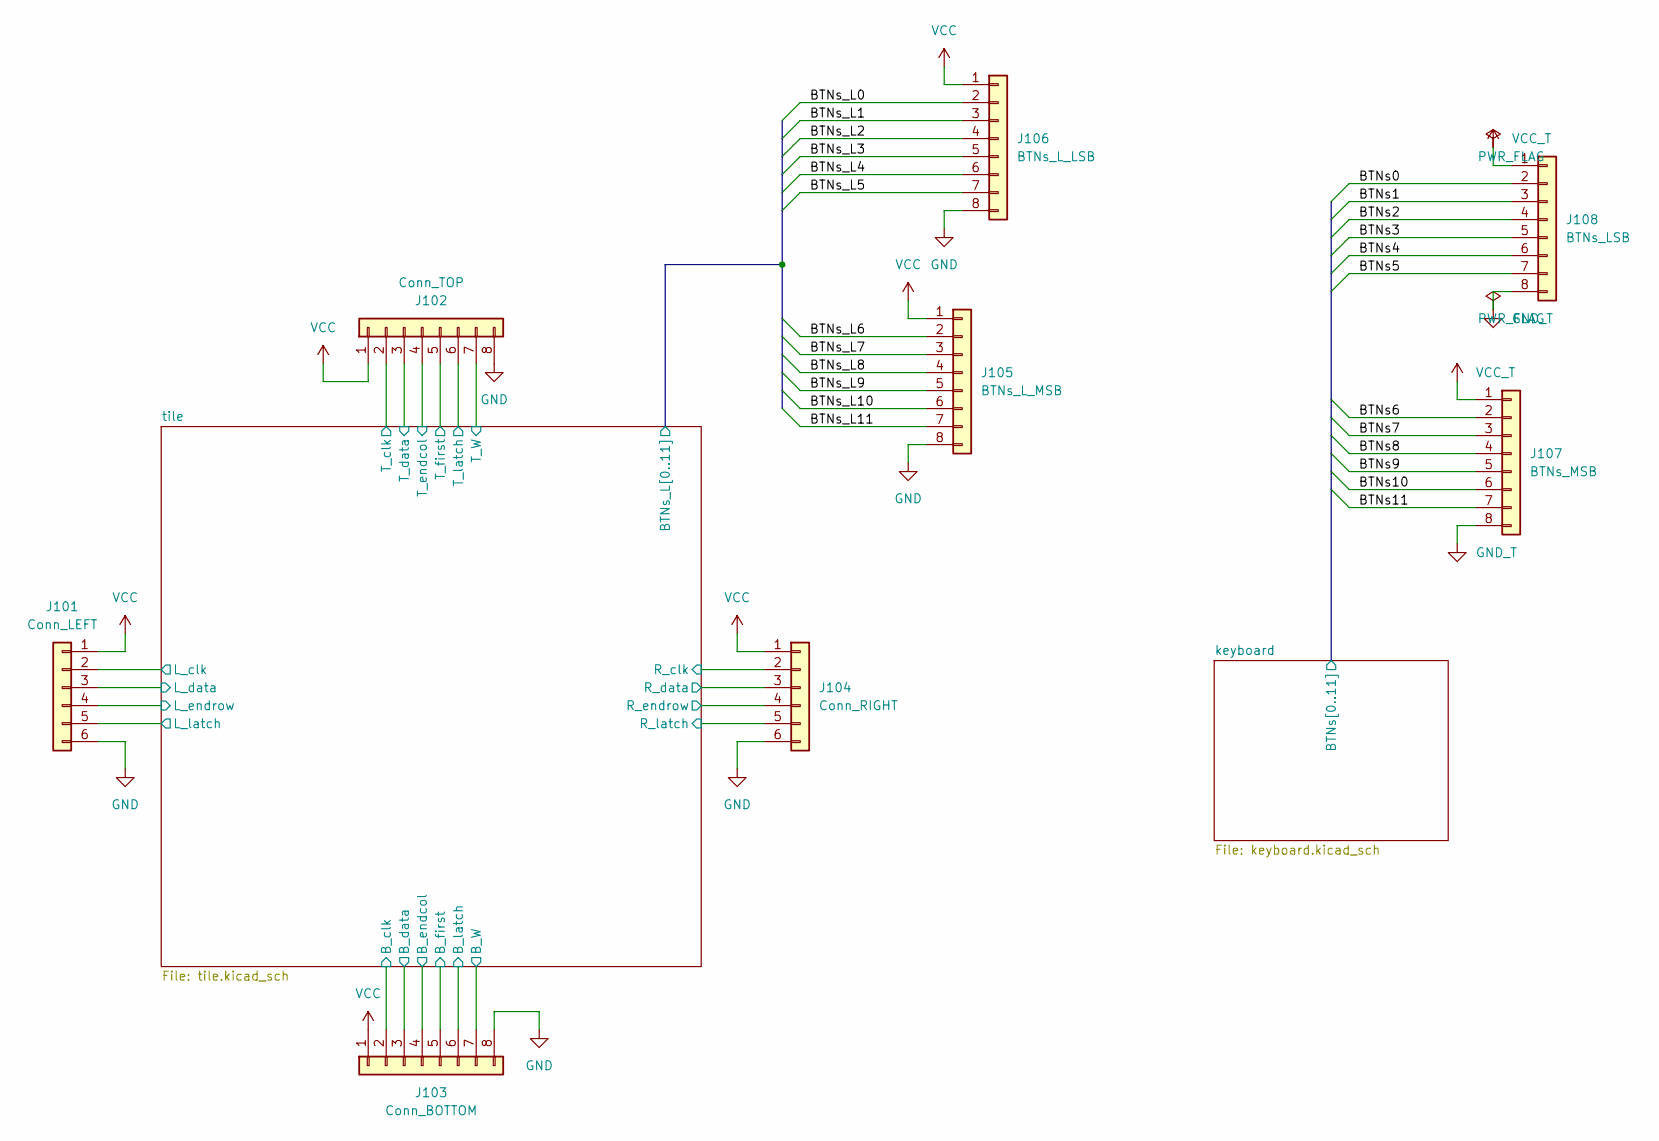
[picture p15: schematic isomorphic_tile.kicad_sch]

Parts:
J101: Conn_LEFT; PinSocket_1x06_P2.54mm_Horizontal; MPN 613010143121
J102: Conn_TOP; PinSocket_1x08_P2.54mm_Horizontal; MPN 613010143121
J103: Conn_BOTTOM; PinHeader_1x08_P2.54mm_Horizontal; MPN 61300811021
J104: Conn_RIGHT; PinHeader_1x06_P2.54mm_Horizontal; MPN 61300811021
J105: BTNs_L_MSB; PinSocket_1x08_P2.54mm_Vertical
J106: BTNs_L_LSB; PinSocket_1x08_P2.54mm_Vertical
J107: BTNs_MSB; PinHeader_1x08_P2.54mm_Vertical
J108: BTNs_LSB; PinHeader_1x08_P2.54mm_Vertical

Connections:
/keyboard/BTNs0: J108.2; also elsewhere on the board
/keyboard/BTNs1: J108.3; also elsewhere on the board
/keyboard/BTNs2: J108.4; also elsewhere on the board
/keyboard/BTNs3: J108.5; also elsewhere on the board
/keyboard/BTNs4: J108.6; also elsewhere on the board
/keyboard/BTNs5: J108.7; also elsewhere on the board
/keyboard/BTNs6: J107.2; also elsewhere on the board
/keyboard/BTNs7: J107.3; also elsewhere on the board
/keyboard/BTNs8: J107.4; also elsewhere on the board
/keyboard/BTNs9: J107.5; also elsewhere on the board
/keyboard/BTNs10: J107.6; also elsewhere on the board
/keyboard/BTNs11: J107.7; also elsewhere on the board
/tile/BTNs_L0: J106.2; also elsewhere on the board
/tile/BTNs_L1: J106.3; also elsewhere on the board
/tile/BTNs_L2: J106.4; also elsewhere on the board
/tile/BTNs_L3: J106.5; also elsewhere on the board
/tile/BTNs_L4: J106.6; also elsewhere on the board
/tile/BTNs_L5: J106.7; also elsewhere on the board
/tile/BTNs_L6: J105.2; also elsewhere on the board
/tile/BTNs_L7: J105.3; also elsewhere on the board
/tile/BTNs_L8: J105.4; also elsewhere on the board
/tile/BTNs_L9: J105.5; also elsewhere on the board
/tile/BTNs_L10: J105.6; also elsewhere on the board
/tile/BTNs_L11: J105.7; also elsewhere on the board
/tile/B_W: J103.7; also elsewhere on the board
/tile/B_clk: J103.2, J104.2; also elsewhere on the board
/tile/B_data: J103.3; also elsewhere on the board
/tile/B_first: J103.5; also elsewhere on the board
/tile/B_latch: J103.6; also elsewhere on the board
/tile/L_clk: J101.2; also elsewhere on the board
/tile/L_data: J101.3; also elsewhere on the board
/tile/L_endrow: J101.4; also elsewhere on the board
/tile/L_latch: J101.5; also elsewhere on the board
/tile/R_data: J104.3; also elsewhere on the board
/tile/R_latch: J104.5; also elsewhere on the board
/tile/T_W: J102.7; also elsewhere on the board
/tile/T_clk: J102.2; also elsewhere on the board
/tile/T_data: J102.3; also elsewhere on the board
/tile/T_endcol: J102.4; also elsewhere on the board
/tile/T_latch: J102.6; also elsewhere on the board
GND: J101.6, J102.5, J102.8, J103.4, J103.8, J104.4, J104.6, J105.8, J106.8; also elsewhere on the board
GND_T: J107.8, J108.8; also elsewhere on the board
VCC: J101.1, J102.1, J103.1, J104.1, J105.1, J106.1; also elsewhere on the board
VCC_T: J107.1, J108.1; also elsewhere on the board

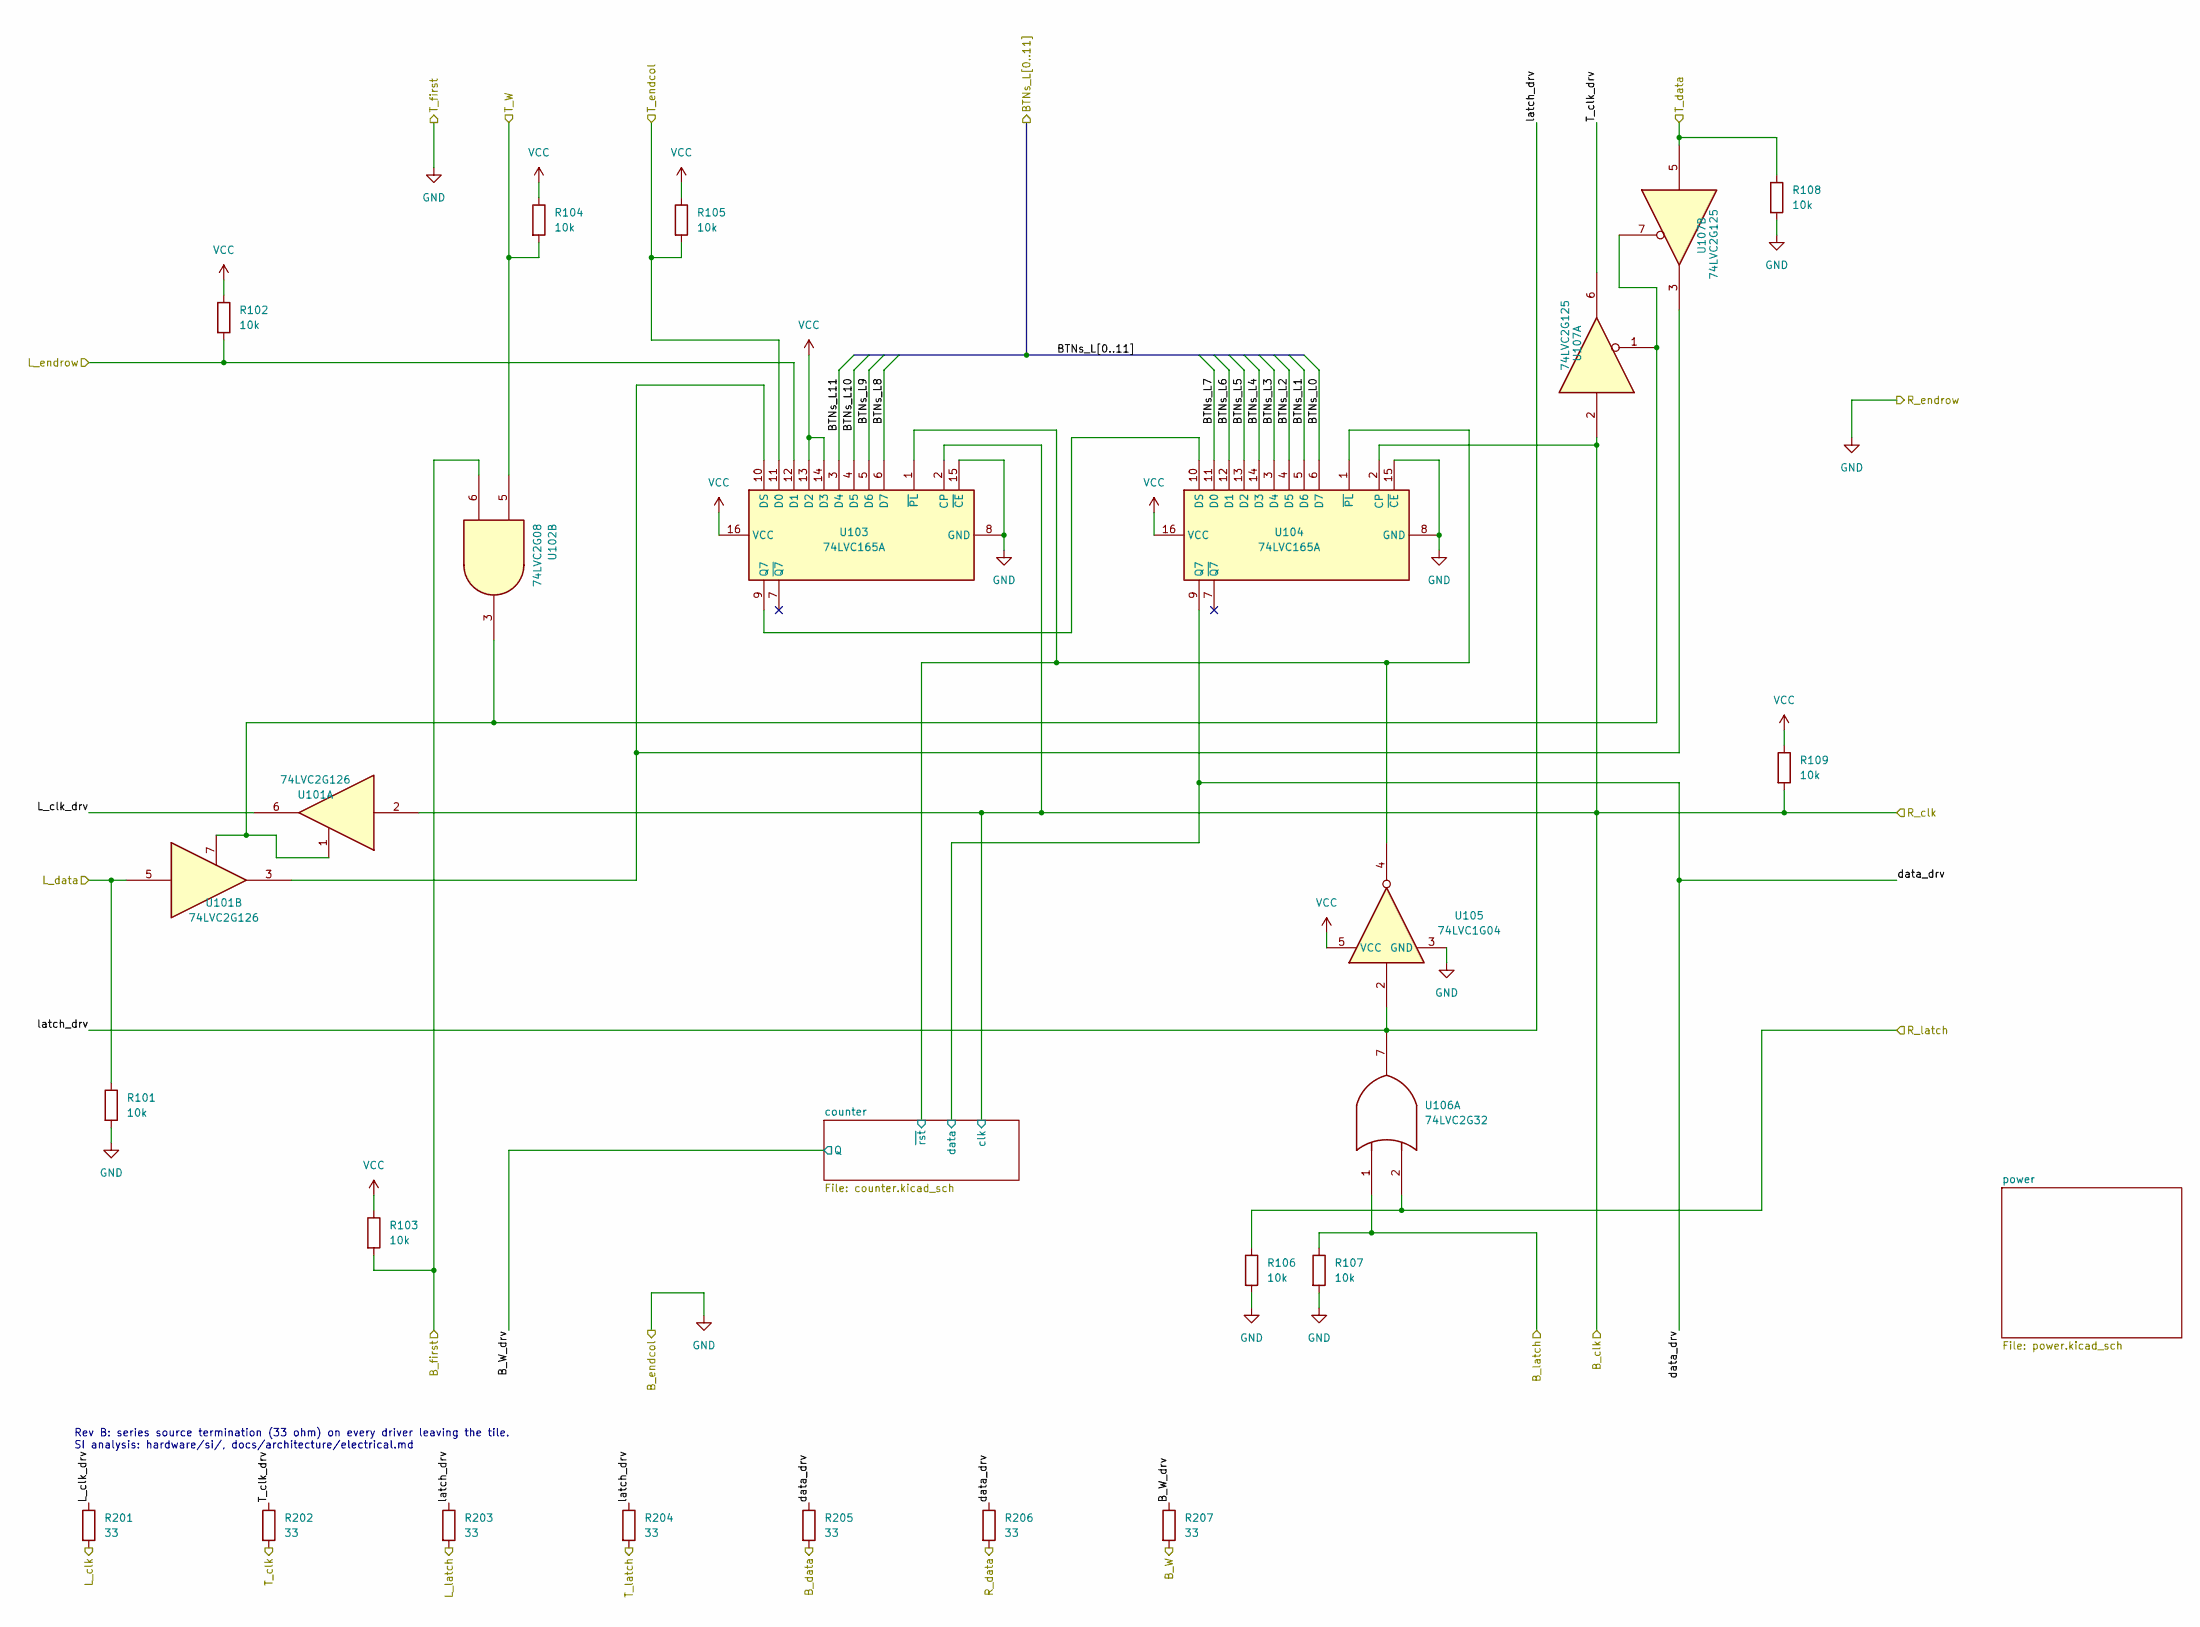
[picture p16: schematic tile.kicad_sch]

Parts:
R101, R102, R103, R104, R105, R106, R107, R108, R109: 10k; R_0603_1608Metric; MPN RC0603FR-0710KL
R201, R202, R203, R204, R205, R206, R207: 33; R_0603_1608Metric; MPN RC0603FR-0733RL
U101: 74LVC2G126; SSOP-8_2.95x2.8mm_P0.65mm; MPN SN74LVC2G126DCTR
U102: 74LVC2G08; SSOP-8_2.95x2.8mm_P0.65mm; MPN SN74LVC2G08DCTR
U103, U104: 74LVC165A; SOIC-16_3.9x9.9mm_P1.27mm; MPN SN74LVC165ADR
U105: 74LVC1G04; SOT-23-5; MPN SN74LVC1G04DBVR
U106: 74LVC2G32; SSOP-8_2.95x2.8mm_P0.65mm; MPN SN74LVC2G32DCTR
U107: 74LVC2G125; SSOP-8_2.95x2.8mm_P0.65mm; MPN SN74LVC2G125DCTR

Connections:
/tile/BTNs_L0: U104.6 (D7); also elsewhere on the board
/tile/BTNs_L1: U104.5 (D6); also elsewhere on the board
/tile/BTNs_L2: U104.4 (D5); also elsewhere on the board
/tile/BTNs_L3: U104.3 (D4); also elsewhere on the board
/tile/BTNs_L4: U104.14 (D3); also elsewhere on the board
/tile/BTNs_L5: U104.13 (D2); also elsewhere on the board
/tile/BTNs_L6: U104.12 (D1); also elsewhere on the board
/tile/BTNs_L7: U104.11 (D0); also elsewhere on the board
/tile/BTNs_L8: U103.6 (D7); also elsewhere on the board
/tile/BTNs_L9: U103.5 (D6); also elsewhere on the board
/tile/BTNs_L10: U103.4 (D5); also elsewhere on the board
/tile/BTNs_L11: U103.3 (D4); also elsewhere on the board
/tile/B_W: R207.2; also elsewhere on the board
/tile/B_W_drv: R207.1; also elsewhere on the board
/tile/B_clk: R109.2, U101.2, U103.2 (CP), U104.2 (CP), U107.2; also elsewhere on the board
/tile/B_data: R205.2; also elsewhere on the board
/tile/B_first: R103.2, U102.6; also elsewhere on the board
/tile/B_latch: R107.1, U106.1; also elsewhere on the board
/tile/L_clk: R201.2; also elsewhere on the board
/tile/L_clk_drv: R201.1, U101.6
/tile/L_data: R101.1, U101.5; also elsewhere on the board
/tile/L_endrow: R102.2, U103.12 (D1); also elsewhere on the board
/tile/L_latch: R203.2; also elsewhere on the board
/tile/R_data: R206.2; also elsewhere on the board
/tile/R_latch: R106.1, U106.2; also elsewhere on the board
/tile/T_W: R104.2, U102.5; also elsewhere on the board
/tile/T_clk: R202.2; also elsewhere on the board
/tile/T_clk_drv: R202.1, U107.6
/tile/T_data: R108.1, U107.5; also elsewhere on the board
/tile/T_endcol: R105.2, U103.11 (D0); also elsewhere on the board
/tile/T_latch: R204.2; also elsewhere on the board
/tile/counter/~rst: U103.1 (~PL), U104.1 (~PL), U105.4; also elsewhere on the board
/tile/data_drv: R205.1, R206.1, U104.9 (Q7); also elsewhere on the board
/tile/latch_drv: R203.1, R204.1, U105.2, U106.7
GND: R101.2, R106.2, R107.2, R108.2, U103.8 (GND), U103.15 (~CE), U104.8 (GND), U104.15 (~CE), U105.3 (GND); also elsewhere on the board
unnamed: U101.1, U101.7, U102.3, U107.1, U107.7
unnamed: U101.3, U103.10 (DS), U107.3
unnamed: U103.9 (Q7), U104.10 (DS)
VCC: R102.1, R103.1, R104.1, R105.1, R109.1, U103.13 (D2), U103.14 (D3), U103.16 (VCC), U104.16 (VCC), U105.5 (VCC); also elsewhere on the board

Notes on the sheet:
Rev B: series source termination (33 ohm) on every driver leaving the tile. SI analysis: hardware/si/, docs/architecture/electrical.md

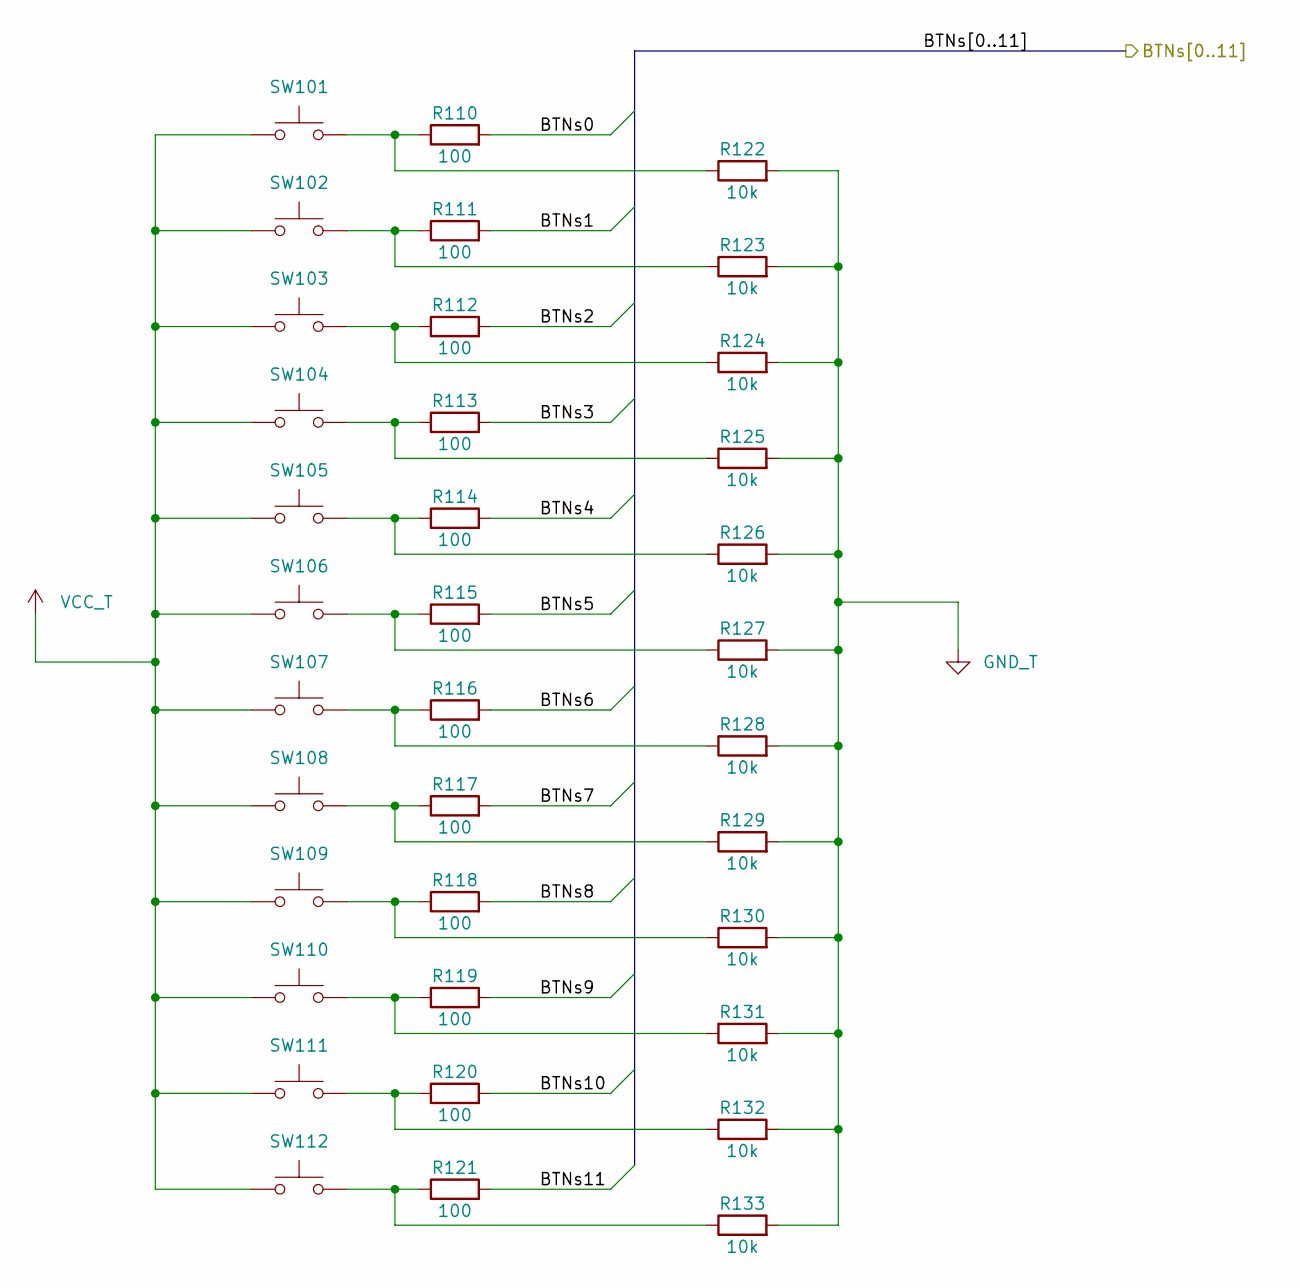
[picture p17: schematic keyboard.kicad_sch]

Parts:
R110, R111, R112, R113, R114, R115, R116, R117, R118, R119, R120, R121: 100; R_0603_1608Metric; MPN RC0603FR-07100RL
R122, R123, R124, R125, R126, R127, R128, R129, R130, R131, R132, R133: 10k; R_0603_1608Metric; MPN RC0603FR-0710KL
SW101, SW102, SW103, SW104, SW105, SW106, SW107, SW108, SW109, SW110, SW111, SW112: SW_Push; SW_Hotswap_Kailh_MX_1.00u_EdgeTrim; MPN CPG151101S11

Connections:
/keyboard/BTNs0: R110.2; also elsewhere on the board
/keyboard/BTNs1: R111.2; also elsewhere on the board
/keyboard/BTNs2: R112.2; also elsewhere on the board
/keyboard/BTNs3: R113.2; also elsewhere on the board
/keyboard/BTNs4: R114.2; also elsewhere on the board
/keyboard/BTNs5: R115.2; also elsewhere on the board
/keyboard/BTNs6: R116.2; also elsewhere on the board
/keyboard/BTNs7: R117.2; also elsewhere on the board
/keyboard/BTNs8: R118.2; also elsewhere on the board
/keyboard/BTNs9: R119.2; also elsewhere on the board
/keyboard/BTNs10: R120.2; also elsewhere on the board
/keyboard/BTNs11: R121.2; also elsewhere on the board
GND_T: R122.2, R123.2, R124.2, R125.2, R126.2, R127.2, R128.2, R129.2, R130.2, R131.2, R132.2, R133.2; also elsewhere on the board
unnamed: R110.1, R122.1, SW101.2
unnamed: R111.1, R123.1, SW102.2
unnamed: R112.1, R124.1, SW103.2
unnamed: R113.1, R125.1, SW104.2
unnamed: R114.1, R126.1, SW105.2
unnamed: R115.1, R127.1, SW106.2
unnamed: R116.1, R128.1, SW107.2
unnamed: R117.1, R129.1, SW108.2
unnamed: R118.1, R130.1, SW109.2
unnamed: R119.1, R131.1, SW110.2
unnamed: R120.1, R132.1, SW111.2
unnamed: R121.1, R133.1, SW112.2
VCC_T: SW101.1, SW102.1, SW103.1, SW104.1, SW105.1, SW106.1, SW107.1, SW108.1, SW109.1, SW110.1, SW111.1, SW112.1; also elsewhere on the board

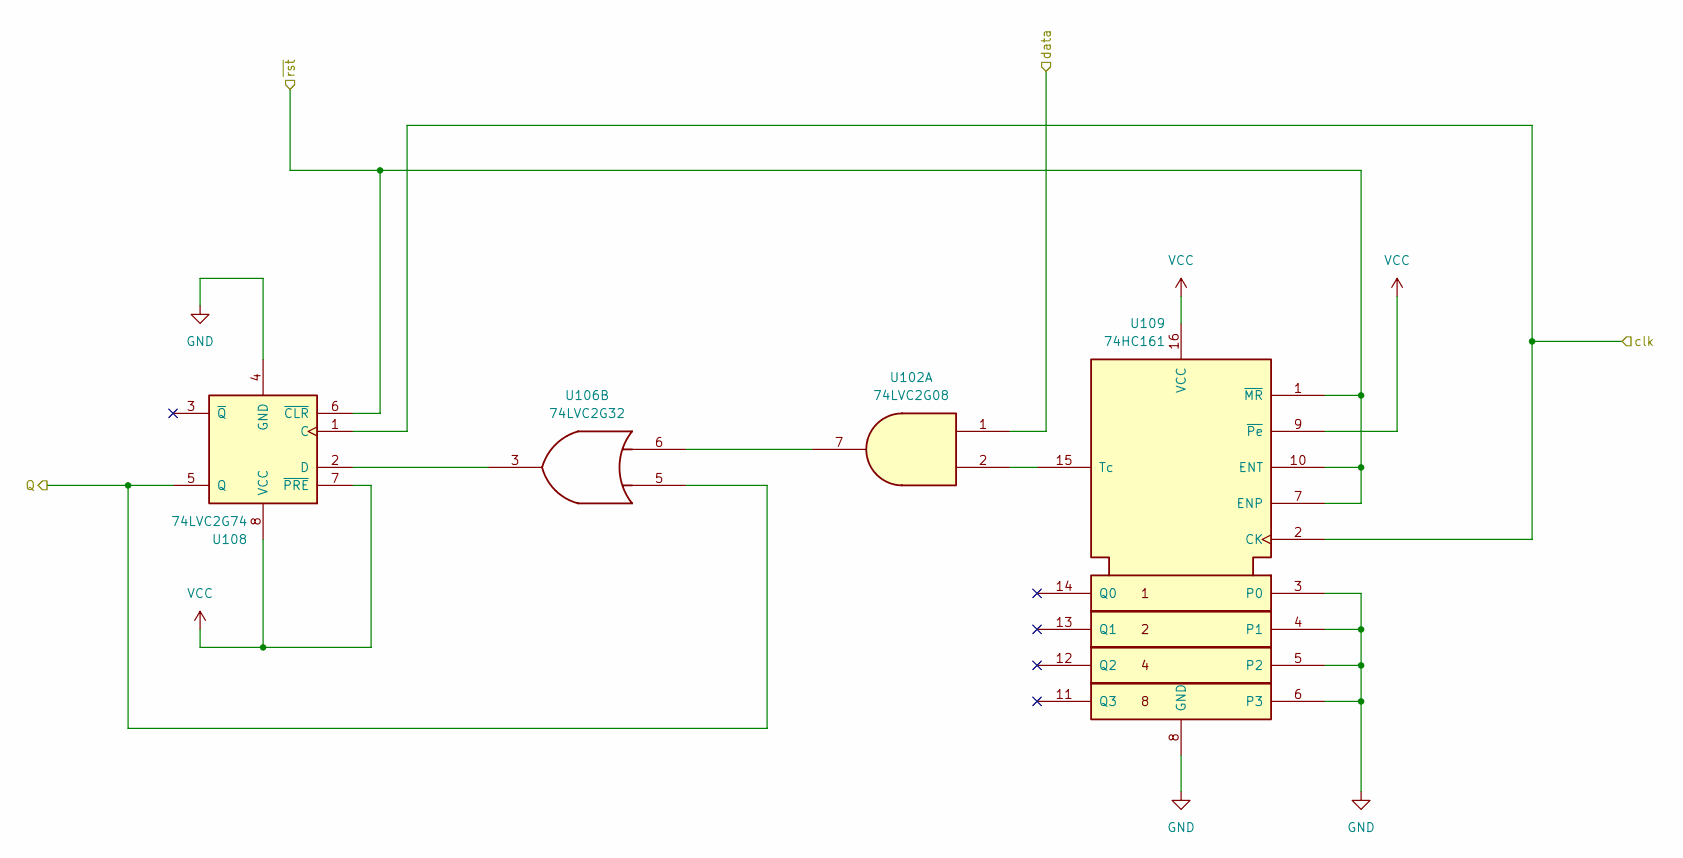
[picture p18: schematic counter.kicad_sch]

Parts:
U102: 74LVC2G08; SSOP-8_2.95x2.8mm_P0.65mm; MPN SN74LVC2G08DCTR
U106: 74LVC2G32; SSOP-8_2.95x2.8mm_P0.65mm; MPN SN74LVC2G32DCTR
U108: 74LVC2G74; SSOP-8_2.95x2.8mm_P0.65mm; MPN SN74LVC2G74DCTR
U109: 74HC161; SOIC-16_3.9x9.9mm_P1.27mm; MPN SN74HC161DR

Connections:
/tile/B_W_drv: U106.5, U108.5 (Q); also elsewhere on the board
/tile/B_clk: U108.1 (C), U109.2 (CK); also elsewhere on the board
/tile/counter/~rst: U108.6 (~CLR), U109.1 (~MR), U109.7 (ENP), U109.10 (ENT); also elsewhere on the board
/tile/data_drv: U102.1; also elsewhere on the board
GND: U108.4 (GND), U109.3 (P0), U109.4 (P1), U109.5 (P2), U109.6 (P3), U109.8 (GND); also elsewhere on the board
unnamed: U102.7, U106.6
unnamed: U106.3, U108.2 (D)
unnamed: U102.2, U109.15 (Tc)
VCC: U108.7 (~PRE), U108.8 (VCC), U109.9 (~Pe), U109.16 (VCC); also elsewhere on the board

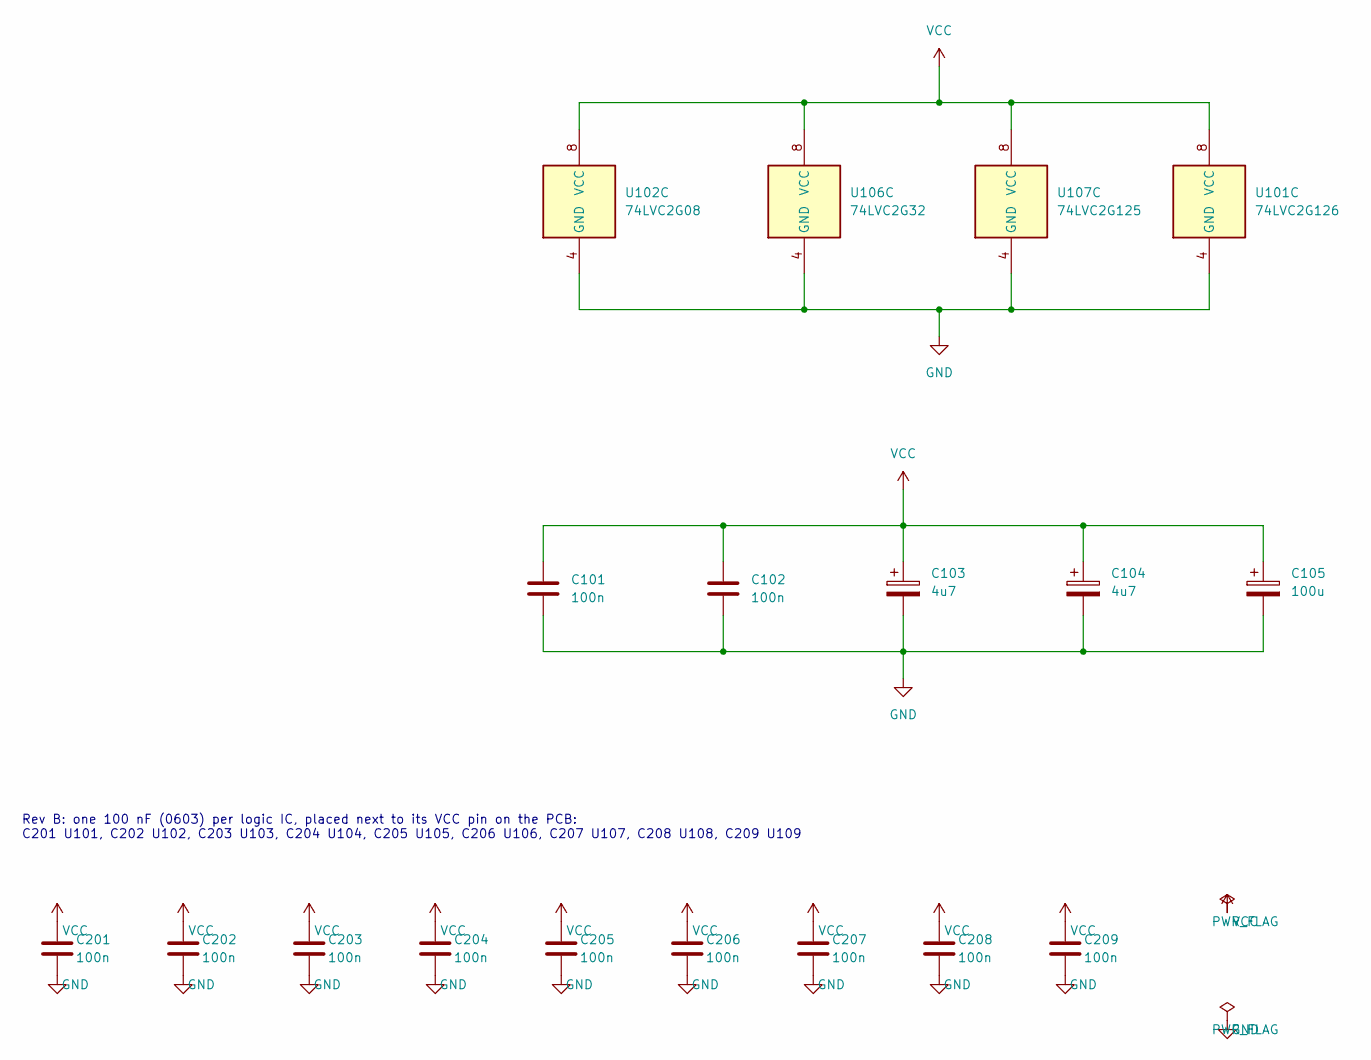
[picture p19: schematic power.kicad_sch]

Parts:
C101, C102, C201, C202, C203, C204, C205, C206, C207, C208, C209: 100n; C_0603_1608Metric; MPN CL10B104KB8NNNC
C103, C104: 4u7; C_1206_3216Metric; MPN CL31B475KAHNNNE
C105: 100u; CP_Elec_6.3x7.7
U101: 74LVC2G126; SSOP-8_2.95x2.8mm_P0.65mm; MPN SN74LVC2G126DCTR
U102: 74LVC2G08; SSOP-8_2.95x2.8mm_P0.65mm; MPN SN74LVC2G08DCTR
U106: 74LVC2G32; SSOP-8_2.95x2.8mm_P0.65mm; MPN SN74LVC2G32DCTR
U107: 74LVC2G125; SSOP-8_2.95x2.8mm_P0.65mm; MPN SN74LVC2G125DCTR

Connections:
GND: C101.2, C102.2, C103.2, C104.2, C105.2, C201.2, C202.2, C203.2, C204.2, C205.2, C206.2, C207.2, C208.2, C209.2, U101.4 (GND), U102.4 (GND), U106.4 (GND), U107.4 (GND); also elsewhere on the board
VCC: C101.1, C102.1, C103.1, C104.1, C105.1, C201.1, C202.1, C203.1, C204.1, C205.1, C206.1, C207.1, C208.1, C209.1, U101.8 (VCC), U102.8 (VCC), U106.8 (VCC), U107.8 (VCC); also elsewhere on the board

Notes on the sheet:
Rev B: one 100 nF (0603) per logic IC, placed next to its VCC pin on the PCB: C201 U101, C202 U102, C203 U103, C204 U104, C205 U105, C206 U106, C207 U107, C208 U108, C209 U109

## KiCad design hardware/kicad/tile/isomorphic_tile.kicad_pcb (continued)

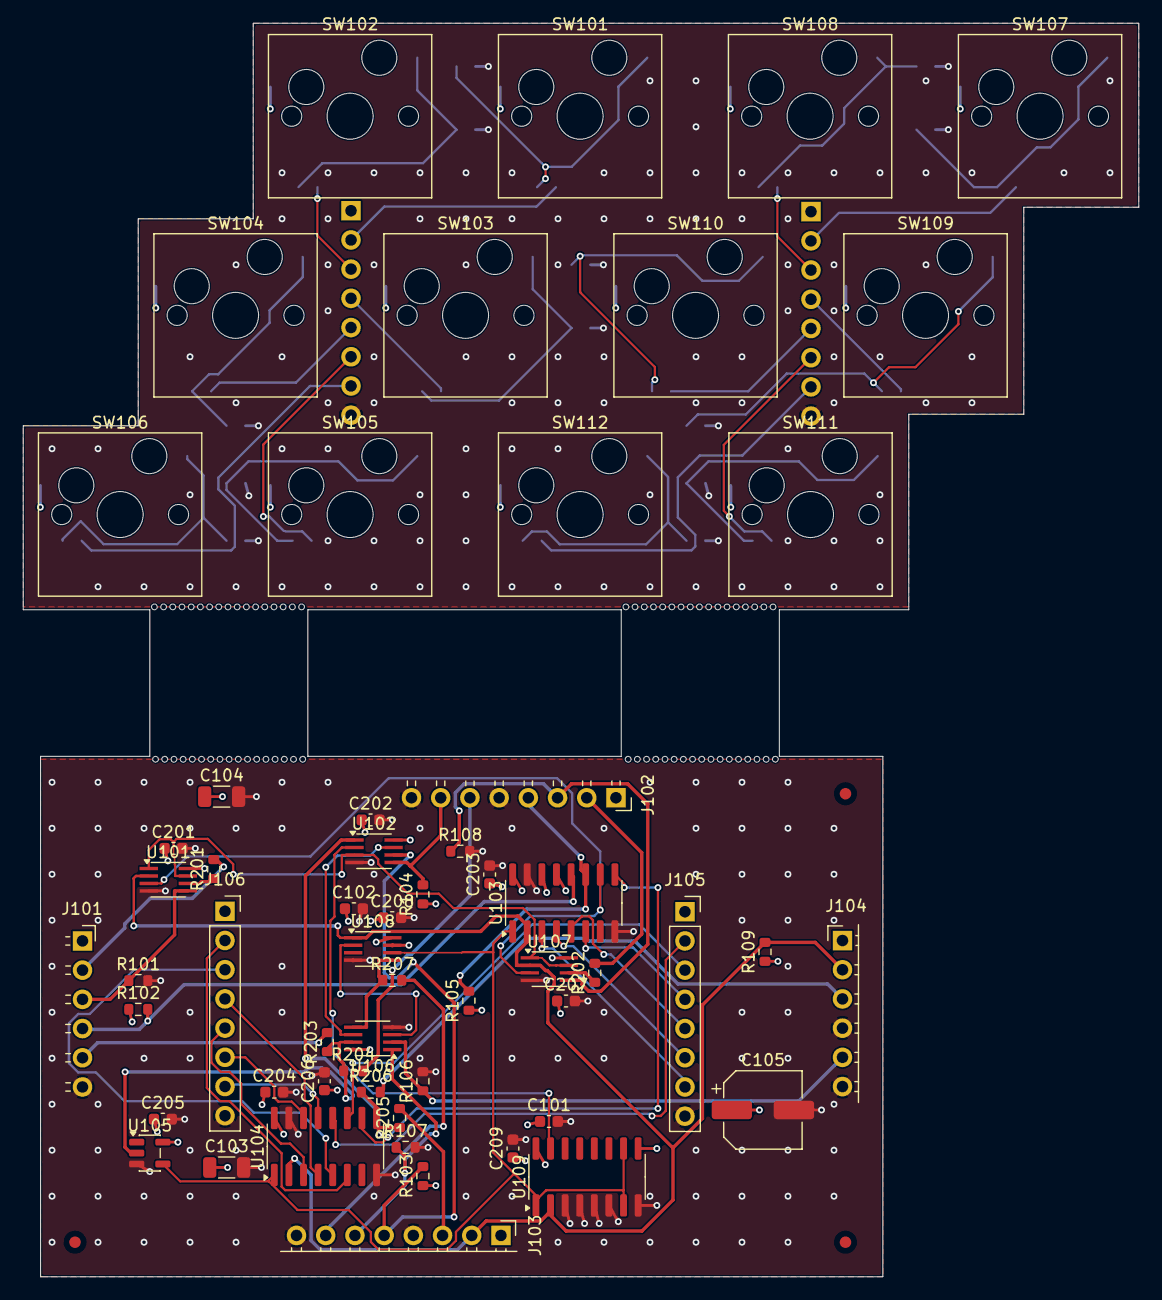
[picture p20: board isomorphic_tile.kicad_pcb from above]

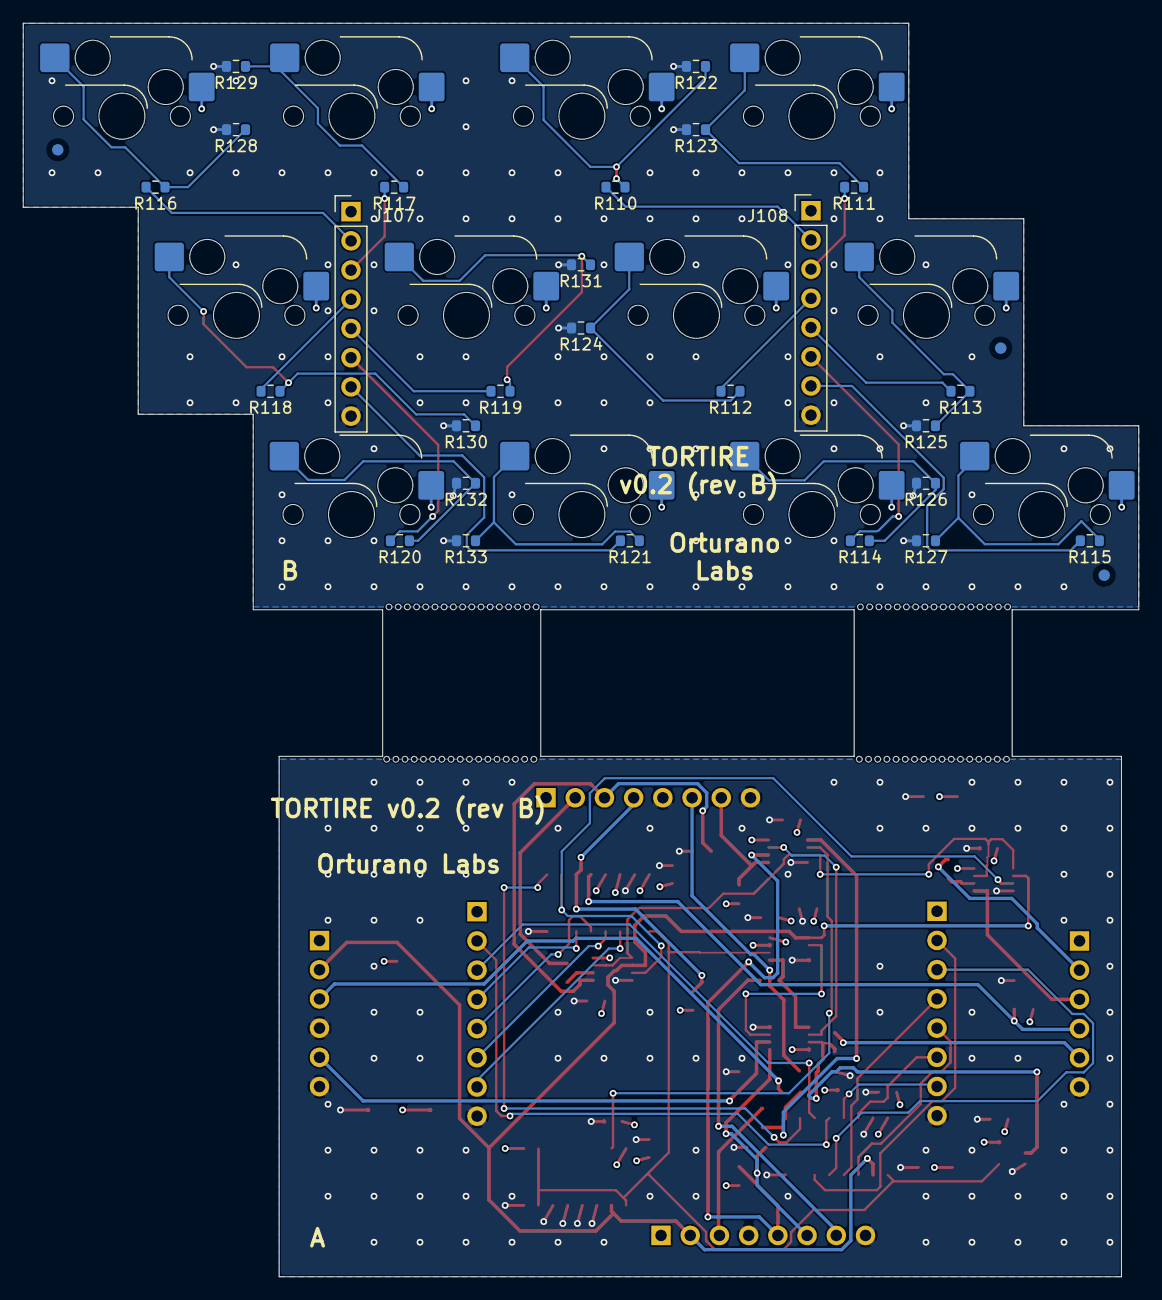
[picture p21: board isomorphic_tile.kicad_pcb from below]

Board: 4 copper layers, 97.0 x 109.0 mm, 157 parts (29 on the bottom side), 68 nets.

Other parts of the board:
FID1, FID2, FID3, FID4, FID5, FID6: Fiducial; Fiducial_1mm_Mask2mm
MB1, MB2, MB3, MB4, MB5, MB6, MB7, MB8, MB9, MB10, MB11, MB12, MB13, MB14, MB15, MB16, MB17, MB18, MB19, MB20, MB21, MB22, MB23, MB24, MB25, MB26, MB27, MB28, MB29, MB30, MB31, MB32, MB33, MB34, MB35, MB36, MB37, MB38, MB39, MB40, MB41, MB42, MB43, MB44, MB45, MB46, MB47, MB48, MB49, MB50, MB51, MB52, MB53, MB54, MB55, MB56, MB57, MB58, MB59, MB60, MB61, MB62, MB63, MB64, MB65, MB66, MB67, MB68: Senza-titolo; MouseBite_NPTH_0.5mm

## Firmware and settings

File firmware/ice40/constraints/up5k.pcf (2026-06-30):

set_io --warn-no-port RESET_N 10
set_io --warn-no-port CLK_IN 35

set_io --warn-no-port BOARD_CLK 31
set_io --warn-no-port BOARD_DATA 34
set_io --warn-no-port BOARD_LATCH 38

set_io --warn-no-port PACKAGE_MIDI 21

set_io --warn-no-port LED_BLUE 40
set_io --warn-no-port LED_GREEN 39
set_io --warn-no-port LED_RED 41

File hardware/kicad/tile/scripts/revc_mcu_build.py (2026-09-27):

#!/usr/bin/env python3
# SPDX-License-Identifier: GPL-3.0-only
"""Rev C concept, microcontroller tile (docs/architecture/revc-mcu-tile.md): board build.

Run by revc_mcu_route.sh (see there for the whole flow):
    revc_mcu_build.py --netlist production/revc_mcu/revc_mcu.net   # stage 1: place -> DSN
    (router)                                                        # KiCadRoutingTools
    revc_mcu_build.py --finish                                      # stage 2: pours, fill

The circuit is defined in revc_mcu_circuit.py and drawn by revc_mcu_schematic.py; this
script takes EVERY net from the netlist KiCad exports from that schematic, checks that the
board has exactly the schematic's components with the same footprints, and links each
footprint to its symbol (so KiCad's DRC schematic-parity check applies). What is decided
here is only geometry: starting from the 18.36 mm rev-C board of revc_build.py (switches on
the lattice, stepped outline), it adds the LEDs, the edge contacts, the MCU and the
passives, places them and writes the routing rules. Two copper layers.
"""
import importlib.util
import os
import shutil
import sys

import pcbnew

HERE = os.path.dirname(os.path.abspath(__file__))
ROOT = os.path.abspath(os.path.join(HERE, "..", "..", "..", ".."))
OUT = os.path.join(ROOT, "production", "revc_mcu")
BRD = os.path.join(OUT, "revc_mcu.kicad_pcb")
MM, TOMM = pcbnew.FromMM, pcbnew.ToMM


def _load(name, path):
    spec = importlib.util.spec_from_file_location(name, path)
    m = importlib.util.module_from_spec(spec)
    spec.loader.exec_module(m)
    return m


revb = _load("revb", os.path.join(HERE, "revb_pcb.py"))
revc = _load("revc", os.path.join(HERE, "revc_build.py"))
circ = _load("revc_mcu_circuit", os.path.join(HERE, "revc_mcu_circuit.py"))
P, R, X0, Y0 = revc.P, revc.R, revc.X0, revc.Y0

def add_fp(board, fpid, ref, value, pos=None, side="B", rot=0):
    fp = revb.load_fp(fpid)
    board.Add(fp)
    fp.SetReference(ref); fp.SetValue(value)
    if pos:
        fp.SetPosition(pcbnew.VECTOR2I(MM(pos[0]), MM(pos[1])))
    fp.SetOrientationDegrees(rot)
    if side == "B":
        fp.SetLayerAndFlip(pcbnew.B_Cu)
    return fp


def in_rule_area(board, pos, r=0.0):
    """pos, or a disc of radius r (mm) around it, touches a rule area"""
    pts = [pos] + [pos + pcbnew.VECTOR2I(MM(dx * r), MM(dy * r))
                   for dx, dy in ((1, 0), (-1, 0), (0, 1), (0, -1), (.7, .7), (-.7, .7), (.7, -.7), (-.7, -.7))]
    for z in board.Zones():
        if z.GetIsRuleArea() and any(z.Outline().Contains(p) for p in pts):
            return True
    return False


def keepout_rect(board, bb, margin, tracks=True):
    z = pcbnew.ZONE(board)
    z.SetIsRuleArea(True)
    z.SetDoNotAllowTracks(tracks); z.SetDoNotAllowVias(True); z.SetDoNotAllowPads(False)
    z.SetDoNotAllowZoneFills(False); z.SetDoNotAllowFootprints(False)
    ls = pcbnew.LSET(); ls.AddLayer(pcbnew.F_Cu); ls.AddLayer(pcbnew.B_Cu); z.SetLayerSet(ls)
    o = z.Outline(); o.NewOutline()
    x0, y0, x1, y1 = bb
    for x, y in ((x0 - margin, y0 - margin), (x1 + margin, y0 - margin),
                 (x1 + margin, y1 + margin), (x0 - margin, y1 + margin)):
        o.Append(MM(x), MM(y))
    board.Add(z)


def apply_netlist(board, path):
    """nets, values and symbol links from the schematic's netlist; the board must hold
    exactly the schematic's components, with the same footprints"""
    comps, nets = circ.read_netlist(path)
    fps = {fp.GetReference(): fp for fp in board.GetFootprints()}
    errors = [f"{r}: on the board, not in the schematic" for r in fps if r not in comps]
    errors += [f"{r}: in the schematic, not on the board" for r in comps if r not in fps]
    for ref, c in comps.items():
        fp = fps.get(ref)
        if fp is None:
            continue
        fpid = f"{fp.GetFPID().GetLibNickname()}:{fp.GetFPID().GetLibItemName()}"
        if fpid != c["footprint"]:
            errors.append(f"{ref}: footprint {fpid} on the board, {c['footprint']} in the schematic")
        fp.SetValue(c["value"])
        fp.SetPath(pcbnew.KIID_PATH(c["path"]))
        for name, val in c["fields"].items():      # MPN, Manufacturer, Datasheet, ... (hidden)
            if name == "Footprint":
                continue
            fp.SetField(name, val)
            fp.GetField(name).SetVisible(False)
        for pad in fp.Pads():
            net = nets.get((ref, pad.GetNumber()))   # "unconnected-(...)": KiCad's single-pad net
            if net is None:
                pad.SetNetCode(0)
            else:
                pad.SetNet(revb.net(board, net))
    if errors:
        sys.exit("board does not match the schematic:\n  " + "\n  ".join(errors))
    # the short copper stubs of the edge pads take the net of their pad
    for t, pad in STUBS:
        t.SetNet(pad.GetNet())
    print("netlist applied:", len(comps), "components,", len(set(nets.values())), "nets")


STUBS = []      # (track, pad): edge-pad stubs, their net is set with the netlist


def contacts(board):
    """Edge contacts, 3 per edge (VCC, DATA, GND). Right/bottom: springs; left/top:
    castellated edge pads. Bottom springs are exactly P/2 left of the top pads (the
    up-lattice shift)."""
    pts = revc.outline()
    xr1, xl1, top, bot = pts[3][0], pts[10][0], pts[0][1], pts[6][1]
    c1 = Y0 + R
    ys = [c1 + 0.5 + j * 1.27 for j in range(3)]
    # top: castellated pads at the edge, centred on row-0 key 1. Copper may run under the
    # plastic body of the hot-swap socket (only its pads and the switch holes are keep-out).
    # The bottom springs sit P/2 to the left = halfway between row-2 keys 1 and 2, where
    # there is no LED cut-out.
    xk = revc.key_xy(0, 1)[0] - 0.8        # 0.8 mm left: clear of the switch pin hole
    xt = [xk + 1.27, xk, xk - 1.27]
    xb = [x - P / 2 for x in xt]
    J = {e: ref for e, (ref, _) in circ.EDGE_CONTACT.items()}
    rows = [(J["R"], [(xr1 - 1.35, y) for y in ys], (2.0, 0.8), "right"),
            (J["L"], [(xl1 + 0.45, y) for y in ys], (0.7, 0.8), "left"),
            (J["B"], [(x, bot - 1.35) for x in xb], (0.8, 2.0), "bottom"),
            (J["T"], [(x, top + 0.3) for x in xt], (0.8, 0.4), "top")]
    for ref, p, (w, h), side in rows:
        fp = pcbnew.FOOTPRINT(board)
        fp.SetReference(ref); fp.SetValue(f"contacts {side}")
        fp.SetFPID(pcbnew.LIB_ID("revc", f"EdgeContacts_{side}"))
        board.Add(fp)
        fp.SetPosition(pcbnew.VECTOR2I(MM(p[0][0]), MM(p[0][1]))); fp.SetLayer(pcbnew.B_Cu)
        for n, (x, y) in enumerate(p, start=1):
            pad = pcbnew.PAD(fp)
            pad.SetNumber(str(n)); pad.SetAttribute(pcbnew.PAD_ATTRIB_SMD)
            pad.SetShape(pcbnew.PAD_SHAPE_RECT); pad.SetSize(pcbnew.VECTOR2I(MM(w), MM(h)))
            ls = pcbnew.LSET(); ls.AddLayer(pcbnew.B_Cu); ls.AddLayer(pcbnew.B_Mask)
            if side in ("right", "bottom"):
                ls.AddLayer(pcbnew.B_Paste)
            else:
                pad.SetProperty(pcbnew.PAD_PROP_CASTELLATED)
            pad.SetLayerSet(ls); fp.Add(pad)
            pad.SetPosition(pcbnew.VECTOR2I(MM(x), MM(y)))
            if side in ("left", "top"):
                c = pad.GetPosition()
                if side == "left":
                    a, b = pcbnew.VECTOR2I(c.x + MM(w / 2 - .05), c.y), pcbnew.VECTOR2I(c.x + MM(w / 2 + .9), c.y)
                else:
                    a, b = pcbnew.VECTOR2I(c.x, c.y + MM(h / 2 - .05)), pcbnew.VECTOR2I(c.x, c.y + MM(h / 2 + .9))
                t = pcbnew.PCB_TRACK(board); t.SetStart(a); t.SetEnd(b); t.SetWidth(MM(0.25))
                t.SetLayer(pcbnew.B_Cu); board.Add(t); STUBS.append((t, pad))
        xs = [q[0] for q in p]; ys_ = [q[1] for q in p]
        depth = {"right": 3.0, "bottom": 3.0, "left": 1.0, "top": 0.55}[side]
        if side == "right":
            box = (max(xs) + w / 2 - depth, min(ys_) - h / 2 - .2, max(xs) + w / 2 + .2, max(ys_) + h / 2 + .2)
        elif side == "left":
            box = (min(xs) - w / 2 - .2, min(ys_) - h / 2 - .2, min(xs) - w / 2 + depth, max(ys_) + h / 2 + .2)
        elif side == "bottom":
            box = (min(xs) - w / 2 - .2, max(ys_) + h / 2 - depth, max(xs) + w / 2 + .2, max(ys_) + h / 2 + .2)
        else:   # top: one courtyard per contact (they are split over the socket gaps)
            box = None
            for x, y in p:
                _court(fp, (x - w / 2 - .2, y - h / 2 - .2, x + w / 2 + .2, y - h / 2 + depth))
        if box:
            _court(fp, box)
        # in the schematic (J1..J4) but not in the BOM yet: the spring part is still to be
        # chosen, and the edge pads are only copper
        fp.SetExcludedFromBOM(True); fp.SetExcludedFromPosFiles(True)


def _court(fp, box):
    for (a, b), (c, d) in (((box[0], box[1]), (box[2], box[1])), ((box[2], box[1]), (box[2], box[3])),
                           ((box[2], box[3]), (box[0], box[3])), ((box[0], box[3]), (box[0], box[1]))):
        s = pcbnew.PCB_SHAPE(fp); s.SetShape(pcbnew.SHAPE_T_SEGMENT)
        s.SetStart(pcbnew.VECTOR2I(MM(a), MM(b))); s.SetEnd(pcbnew.VECTOR2I(MM(c), MM(d)))
        s.SetLayer(pcbnew.B_CrtYd); s.SetWidth(MM(0.05)); fp.Add(s)


def stage1(netlist):
    os.makedirs(OUT, exist_ok=True)
    src = os.path.join(ROOT, "production", "revc18", "revc18.kicad_pcb")
    board = pcbnew.LoadBoard(src)
    for t in list(board.GetTracks()):
        board.Delete(t)
    for z in list(board.Zones()):
        board.Delete(z)
    for fp in list(board.GetFootprints()):
        if not fp.GetReference().startswith("SW"):
            board.Delete(fp)
    # keys: SW<n> = key K<n>, numbered in row-major order (row 0 = top row, left to right)
    sws = sorted((fp for fp in board.GetFootprints() if fp.GetReference().startswith("SW")),
                 key=lambda f: (round(TOMM(revb.switch_centre(f).y)), TOMM(revb.switch_centre(f).x)))
    for n, sw in enumerate(sws):
        sw.SetReference(f"SW{n + 1}")
    # LEDs: D<n> south of SW<n>'s centre, chained in circ.CHAIN order (every link goes to a
    # neighbour). An LED whose chain runs left to right is turned 180 deg, so that DOUT faces
    # the next LED (and DIN the previous one).
    xs_ = [TOMM(revb.switch_centre(sws[n]).x) for n in circ.CHAIN]
    for k, n in enumerate(circ.CHAIN):
        c = revb.switch_centre(sws[n])
        step = xs_[k + 1] - xs_[k] if k + 1 < len(xs_) else xs_[k] - xs_[k - 1]
        led = add_fp(board, circ.FP["led"], f"D{n + 1}", "SK6812MINI-E", (TOMM(c.x), TOMM(c.y) + 5.08),
                     side="B", rot=180 if step > 0 else 0)
        # the reverse-mount LED has a board cut-out inside its footprint; routers that only
        # know the outer outline route through it, so fence it with a rule area
        xs, ys = [], []
        for g in led.GraphicalItems():
            if g.GetLayer() == pcbnew.Edge_Cuts:
                b = g.GetBoundingBox()      # plain numbers only: BOX2I.Merge on temporaries crashed
                xs += [TOMM(b.GetX()), TOMM(b.GetRight())]; ys += [TOMM(b.GetY()), TOMM(b.GetBottom())]
        if xs:
            keepout_rect(board, (min(xs), min(ys), max(xs), max(ys)), 0.35)
    # MCU and passives
    mcu = add_fp(board, circ.FP["mcu"], "U1", "ATtiny1616-MNR", side="B")
    parts, targets = [mcu], {}
    contacts(board)
    for e, rref in circ.EDGE_RES.items():
        r = add_fp(board, circ.FP["r"], rref, "100", side="B"); parts.append(r)
        # series resistor next to its edge contacts: it protects the hot-plug contact
        c = board.FindFootprintByReference(circ.EDGE_CONTACT[e][0]).GetPosition()
        targets[rref] = (TOMM(c.x), TOMM(c.y))
    for ref, v, near in circ.DECOUPLING:
        c = add_fp(board, circ.FP["c100n"] if v == "100n" else circ.FP["c4u7"], ref, v, side="B")
        parts.append(c)
        if near:        # LED decoupling next to the corner LEDs, away from the MCU
            led = board.FindFootprintByReference(near).GetPosition()
            targets[ref] = (TOMM(led.x), TOMM(led.y) + 3.0)
    tp = add_fp(board, circ.FP["tp"], "TP1", "UPDI", side="B"); parts.append(tp)
    targets["TP1"] = (revc.key_xy(2, 0)[0] + P / 2, Y0 + 2 * R + 5.5)
    apply_netlist(board, netlist)

    outline = pcbnew.SHAPE_POLY_SET(); board.GetBoardPolygonOutlines(outline, False)
    placer = revb.Placer(board, outline)
    centre = (revc.key_xy(1, 0)[0] + 1.5 * P, Y0 + R)
    targets["U1"] = centre
    failed = []
    ring = None
    for fp in parts:
        tgt = targets.get(fp.GetReference(), centre)
        fp.SetPosition(pcbnew.VECTOR2I(MM(300), MM(300)))
        try:
            placer.place(fp, "B", tgt, "key", rmax=40)
        except RuntimeError:
            failed.append(fp.GetReference())
        if fp.GetReference() == "U1":
            # keep a 2.5 mm ring free around the 0.4 mm-pitch VQFN so every pin can escape
            # straight out (a tightly packed first placement left 13 nets unroutable)
            bb = fp.GetCourtyard(pcbnew.B_CrtYd).BBox()
            ring = pcbnew.FOOTPRINT(board); ring.SetReference("KEEPOUT_U1"); board.Add(ring)
            ring.SetPosition(fp.GetPosition()); ring.SetLayer(pcbnew.B_Cu)
            g = 2.5
            _court(ring, (TOMM(bb.GetX()) - g, TOMM(bb.GetY()) - g, TOMM(bb.GetRight()) + g, TOMM(bb.GetBottom()) + g))
    if ring is not None:
        board.Delete(ring)
    print("placement failed for:", failed or "none")
    # turn the (square) MCU so that its VDD pin faces the 100 nF at C1: the shortest supply
    # loop, and the VDD pin (boxed in between GND and a key pin) escapes straight to it
    vdd = next(p for p in mcu.Pads() if p.GetNetname() == "VCC")
    c1 = board.FindFootprintByReference(circ.DECOUPLING[0][0])
    c1_vcc = next(p for p in c1.Pads() if p.GetNetname() == "VCC").GetPosition()
    best = min((0, 90, 180, 270), key=lambda a: (mcu.SetOrientationDegrees(a),
                                                 (vdd.GetPosition() - c1_vcc).EuclideanNorm())[1])
    rot = os.environ.get("MCU_ROT", "auto")      # the flow may try the other orientations
    if rot == "stored" and circ.stored_orientation() is not None:
        best = circ.stored_orientation()           # the one of the last clean board
    elif rot not in ("auto", "stored"):
        best = int(rot)
    mcu.SetOrientationDegrees(best)
    print("MCU orientation:", best)
    if assign_pins(board, mcu):
        sys.exit(3)         # the flow redraws the schematic with the new pin map and re-runs

    # no vias in or next to any SMD land (LEDs, sockets, MCU, passives, edge contacts): a
    # boxed-in pad otherwise gets a via-in-pad, which needs filled and capped vias
    # (IPC-4761 type VII); the MCU exposed pad reaches GND through the bottom pour instead
    for fp in board.GetFootprints():
        for pad in fp.Pads():
            if pad.GetAttribute() != pcbnew.PAD_ATTRIB_SMD:
                continue
            b = pad.GetBoundingBox()
            # 0.2 mm around the 0.4 mm-pitch MCU (it needs the room to fan out), 0.3 elsewhere
            keepout_rect(board, (TOMM(b.GetX()), TOMM(b.GetY()), TOMM(b.GetRight()), TOMM(b.GetBottom())),
                         0.2 if fp.GetReference() == "U1" else 0.3, tracks=False)
    # 2 layers (no fast inter-tile clock any more, low density): the top (switch side, no
    # parts) becomes an almost continuous GND plane, the bottom carries the parts, the
    # signals, VCC and a stitched GND pour (see revc_mcu_route.sh)
    board.SetCopperLayerCount(2)
    pcbnew.SaveBoard(BRD, board)
    write_libs(board)
    shutil.copy(os.path.join(ROOT, "hardware", "kicad", "tile", "isomorphic_tile.kicad_pro"),
                os.path.join(OUT, "revc_mcu.kicad_pro"))
    # the VQFN-20 has 0.40 mm pitch and 0.15 mm between pads: 0.2 mm clearance would make
    # every pin unreachable. 0.15 mm clearance/track is a standard fab capability.
    import json
    pro = os.path.join(OUT, "revc_mcu.kicad_pro")
    d = json.load(open(pro))
    d["board"]["design_settings"]["rules"].update(min_clearance=0.15, min_track_width=0.15, min_connection=0.15)
    for c in d["net_settings"]["classes"]:
        c["clearance"] = 0.15
    json.dump(d, open(pro, "w"), indent=2)
    # the reverse-mount LED land pattern puts its pads close to its own board cut-out by
    # design (KiCad library footprint): allow that, and only that, in a custom DRC rule
    open(os.path.join(OUT, "revc_mcu.kicad_dru"), "w").write(
        '(version 1)\n'
        '(rule "reverse-mount LED pads next to their cut-out"\n'
        '  (condition "A.Type == \'Pad\' && A.memberOfFootprint(\'D*\')")\n'
        '  (constraint edge_clearance (min 0.05mm)))\n')
    pcbnew.ExportSpecctraDSN(pcbnew.LoadBoard(BRD), os.path.join(OUT, "revc_mcu.dsn"))
    print("stage 1 done")


def assign_pins(board, mcu):
    """Pin swapping: give the 15 interchangeable signals the pins whose angle around the MCU
    matches, in order, the angle of where each signal goes, so that the fan-out has no
    crossings. Returns True if the stored pin map changed."""
    import math
    c = mcu.GetPosition()
    ang = lambda p: math.atan2(TOMM(p.y - c.y), TOMM(p.x - c.x))     # noqa: E731
    pad_of_port = {port: mcu.FindPadByNumber(str(circ.PIN[port])) for port in circ.FLEX_PORTS}
    ports = sorted(circ.FLEX_PORTS, key=lambda p: ang(pad_of_port[p].GetPosition()))
    target = {}
    for net in circ.FLEX_NETS:
        pts = [p.GetPosition() for fp in board.GetFootprints() if fp.GetReference() != "U1"
               for p in fp.Pads() if p.GetNetname() == net]
        target[net] = math.atan2(sum(TOMM(p.y - c.y) for p in pts) / len(pts),
                                 sum(TOMM(p.x - c.x) for p in pts) / len(pts))
    nets = sorted(circ.FLEX_NETS, key=lambda n: target[n])
    wrap = lambda a: abs((a + math.pi) % (2 * math.pi) - math.pi)   # noqa: E731
    k = len(ports)
    shift = min(range(k), key=lambda s: sum(wrap(ang(pad_of_port[ports[(i + s) % k]].GetPosition())
                                                 - target[nets[i]]) for i in range(k)))
    new = {nets[i]: ports[(i + shift) % k] for i in range(k)}
    orientation = int(round(mcu.GetOrientationDegrees())) % 360
    if new == circ.pinmap():
        if circ.stored_orientation() != orientation:
            circ.save_pinmap(new, orientation)
        print("pin map: unchanged")
        return False
    circ.save_pinmap(new, orientation)
    print("pin map: updated", circ.PINMAP_FILE)
    return True


def write_libs(board):
    """project footprint libraries next to the board: the generated edge-contact footprints
    (library 'revc') and the local Kailh socket library, so that the schematic's footprint
    links resolve (ERC) and 'Update PCB from Schematic' works in the GUI"""
    lib = os.path.join(OUT, "revc.pretty")
    shutil.rmtree(lib, ignore_errors=True)
    io = pcbnew.PCB_IO_KICAD_SEXPR()     # the path-guessing helpers find no plugin here
    io.CreateLibrary(lib)
    for ref, _ in circ.EDGE_CONTACT.values():
        io.FootprintSave(lib, board.FindFootprintByReference(ref))
    kailh = os.path.relpath(os.path.join(ROOT, "hardware", "kicad", "lib"), OUT)
    write_fp_lib_table(OUT, "${KIPRJMOD}/" + kailh)


def write_fp_lib_table(folder, kailh_dir):
    open(os.path.join(folder, "fp-lib-table"), "w").write(
        '(fp_lib_table\n\t(version 7)\n'
        f'\t(lib (name "revc")(type "KiCad")(uri "${{KIPRJMOD}}/revc.pretty")(options "")'
        '(descr "rev C edge contacts, generated by revc_mcu_build.py"))\n'
        f'\t(lib (name "Switch_Keyboard_Hotswap_Kailh")(type "KiCad")'
        f'(uri "{kailh_dir}/Switch_Keyboard_Hotswap_Kailh.pretty")(options "")'
        '(descr "Kailh MX hot-swap socket (keyswitch-kicad-library v2.3)"))\n)\n')


def stage2(ses=None):
    """ses: Freerouting session to import, or None when KiCadRoutingTools routed BRD in place."""
    board = pcbnew.LoadBoard(BRD)
    if ses and not pcbnew.ImportSpecctraSES(board, ses):
        sys.exit("SES import failed")
    outline = pcbnew.SHAPE_POLY_SET(); board.GetBoardPolygonOutlines(outline, False)
    # GND stitching (3 mm grid): ties the bottom pour islands to the almost continuous top pour
    revb.KEY_Y_MAX, revb.LOGIC_Y_MIN = 200, 300
    # a VCC plane on top (from route_planes) keeps GND on the bottom only; with a GND plane
    # or no plane on top, stitch the bottom GND pour to it
    top_plane = any(z.GetLayer() == pcbnew.F_Cu and not z.GetIsRuleArea() and z.GetNetname() == "VCC"
                    for z in board.Zones())
    top_gnd = any(z.GetLayer() == pcbnew.F_Cu and not z.GetIsRuleArea() and z.GetNetname() == "GND"
                  for z in board.Zones())
    items = [p for fp in board.GetFootprints() for p in fp.Pads()] + list(board.GetTracks())
    gnd = board.FindNet("GND"); n = 0
    y = 40.0
    while y < 100 and not top_plane:
        x = 100.0
        while x < 205:
            pos = pcbnew.VECTOR2I(MM(x), MM(y))
            if revb.outline_ok(board, pos, margin=1.0) and not in_rule_area(board, pos, 0.35):
                v = revb.via_fits(board, items, pos, gnd.GetNetCode(), clearance=0.3)
                if v is not None:
                    v.SetNet(gnd); board.Add(v); items.append(v); n += 1
            x += 3.0
        y += 3.0
    print("stitching vias:", n)
    if not top_plane and not top_gnd:
        revb.add_zone(board, outline, pcbnew.F_Cu, "GND")
    revb.add_zone(board, outline, pcbnew.B_Cu, "GND")
    revb.fix_text_mirroring(board)
    board.BuildConnectivity(); pcbnew.ZONE_FILLER(board).Fill(board.Zones())
    pcbnew.SaveBoard(BRD, board)
    print("stage 2 done")


if __name__ == "__main__":
    if "--route-in" in sys.argv:
        stage2(sys.argv[sys.argv.index("--route-in") + 1])
    elif "--finish" in sys.argv:
        stage2(None)
    else:
        stage1(sys.argv[sys.argv.index("--netlist") + 1])

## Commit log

2026-01-04 Adding module-tile kicad project
    [blocco.kicad_sch, tastiera_isomorfa.kicad_pcb, tastiera_isomorfa.kicad_sch]
2026-01-04 Added horizontal control line UTF-8 like. Updated capacitor and resistor values.
    [blocco.kicad_sch, tastiera_isomorfa.kicad_sch]
2026-01-07 starting new topology
    [blocco.kicad_sch, tastiera_isomorfa.kicad_pcb, tastiera_isomorfa.kicad_sch]
2026-01-08 Init VHDL simulation
    [tastiera_isomorfa.kicad_sch]
2026-01-08 Now VHDL simulation is working. VHDL descirption must be converted to kicad schematic.
2026-01-10 Start kicad design
    [keyboard.kicad_sch, tastiera_isomorfa.kicad_sch]
2026-02-23 Improving schematics
    [counter.kicad_sch, keyboard.kicad_sch, tastiera_isomorfa.kicad_sch]
2026-02-24 Schematics update
    [counter.kicad_sch, keyboard.kicad_sch, power.kicad_sch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]
2026-02-24 Schematic complete
    [counter.kicad_sch, keyboard.kicad_sch, power.kicad_sch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]
2026-02-24 Pcb started
    [keyboard.kicad_sch, tastiera_isomorfa.kicad_pcb, tile.kicad_sch]
2026-02-25 First commit new branch
    [counter.kicad_sch, keyboard.kicad_sch, power.kicad_sch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]
2026-02-25 Updated cpb with FreeRouting
    [tastiera_isomorfa.dsn, tastiera_isomorfa.kicad_pcb]
2026-02-25 Design completed
    [tastiera_isomorfa.kicad_pcb]
2026-02-26 Create gerber files
    [tastiera_isomorfa-B_Cu.gbr, tastiera_isomorfa-B_Mask.gbr, tastiera_isomorfa-B_Silkscreen.gbr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]
2026-02-27 Adjust interboard pitch
    [tastiera_isomorfa-B_Cu.gbr, tastiera_isomorfa-B_Mask.gbr, tastiera_isomorfa-B_Silkscreen.gbr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]
2026-02-27 Adjust borders
    [tastiera_isomorfa-B_Cu.gbr, tastiera_isomorfa-B_Mask.gbr, tastiera_isomorfa-B_Silkscreen.gbr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]
2026-06-14 test per integrare logica base con i2c
2026-06-15 Un po' di roba
2026-06-24 Removed i2c sending. Added keyboard state latching.
2026-06-25 logica di detection dei cambiamenti
2026-06-29 midi uart ok
2026-06-30 fixed polarity and ref pitch
    [up5k.pcf]
2026-09-26 Stop tracking generated files; add ledger and rootless tooling
    - Add a root .gitignore for HDL build/simulation outputs, KiCad
    backups/caches/project-local settings and FreeRouting exchange files.
    - Untrack build products, simulation objects, waveforms, KiCad backups
    and fp-info-cache (history is left untouched).
    - Remove the empty firmware/platformio.ini (there is no RP2040 firmware).
    - Add docs/LEDGER.md, the engineering log of attempts and lessons.
    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
    [tastiera_isomorfa.dsn]
2026-09-26 Reorganise folders and rename the KiCad project to English
    - firmware/iCE40_firmware -> firmware/ice40
    - firmware/test_parziali/* -> firmware/experiments/{i2c_picoice,scan_low_rate,scan_low_rate_i2c}
    - hardware/kicad/module-tile -> hardware/kicad/tile, project
    tastiera_isomorfa -> isomorphic_tile (instance project names and the
    sheetfile references updated accordingly)
    - rev-A gerbers and BOM kept as the manufactured record in
    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
    [bom.csv, counter.kicad_sch, isomorphic_tile.kicad_pcb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]
2026-09-26 Translate firmware and simulation sources to English; clean up build flow
    - Translate all comments in the iCE40 top level, testbenches, the
    experiments and the tile simulation models; add SPDX headers and a
    description of the top level.
    - Fix the ref_pitch comment (the value is 60 = C4, not 96 = C7).
    - firmware/ice40/Makefile: tools from PATH or OSS_CAD_SUITE, optional
    PICO_ICE_SERIAL, no sudo for dfu-util (udev rule instead).
    - Experiments: same OSS_CAD_SUITE handling and no sudo.
    - Prune the vendored open-logic copy to the 9 files actually used, add
    its upstream License.txt (PSI HDL Library License 1.0) and VENDORED.md.
    - Drop the unused i2c_master.vhd from firmware/ice40/src (it s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
2026-09-26 KiCad: rename Italian field and footprint names
    - Symbol field "Codice" (manufacturer part number) -> "MPN".
    - Mouse-bite footprint "Senza-titolo" -> "MouseBite_NPTH_0.5mm".
    Verified: netlist identical to rev A, switch/connector/outline
    invariants OK, DRC report counts unchanged.
    [counter.kicad_sch, isomorphic_tile.kicad_pcb, isomorphic_tile.kicad_sch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]
2026-09-26 Write the project documentation in English
    - New root README, LICENSE.md (license map), hardware/ and firmware
    READMEs.
    - docs/: architecture (overview, scan protocol and topology discovery,
    electrical, mechanical), build guides (firmware, hardware checks,
    BOM, assembly), known issues, curated rev-A media, ledger update.
    - tools/scripts/export_reference.sh extracts the rev-A reference design
    and netlist for check_invariants.py.
    - SPDX identifiers match the repository licenses (GPL-3.0-only for
    firmware and tools).
    - .gitignore: anchor build/ patterns so docs/build/ is not ignored.
2026-09-26 Add a first SPICE model of the board clock link
    hardware/si/clock_link.py builds and runs ngspice decks for the
    controller-to-first-tile clock (driver, dupont wire, tile track, lumped
    load) with a sweep of the series source resistor, and reports
    overshoot, undershoot, rise time and threshold re-crossings.
    Parameters are generic and the model is not yet calibrated against a
    measurement; findings and limits are logged in docs/LEDGER.md.
2026-09-26 Migrate the tile project to KiCad 10 file format
    Files upgraded with kicad-cli 10.0.6 (sch upgrade / pcb upgrade), no
    content changes. KiCad 9 can no longer open the project.
    invariants OK, ERC and DRC report counts unchanged.
    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
    [counter.kicad_sch, isomorphic_tile.kicad_pcb, isomorphic_tile.kicad_sch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]
2026-09-26 SI: add tile-to-tile clock hop model and input clamp diodes
    - hardware/si/tile_hop.py compares the rev-A hop (2 layers, ~110 ohm,
    141 mm B_clk tree) with the rev-B target (4 layers, ~55 ohm) and
    sweeps the series resistor; it counts threshold crossings.
    - clock_link.py: add input clamp diodes; the fall-edge window no longer
    includes the next rising edge.
    - Ledger: KiCad 10 migration notes, measured inter-board net lengths,
    SI results and the 33 ohm decision.
2026-09-26 Rev B schematic: series termination, decoupling, assembly-ready parts
    Function unchanged (no logic connection changes). Applied by
    hardware/kicad/tile/scripts/revb_schematic.py:
    - 33 ohm series resistors R201-R207 at every driver leaving the tile
    (L_clk, T_clk, L_latch, T_latch, B_data, R_data, B_W).
    - 100 nF per logic IC (C201-C209); PWR_FLAGs on VCC, GND, VCC_T, GND_T.
    - Values match the ordered parts (74LVC..., 74HC161); footprints:
    0603 passives, TI DCT land pattern for the 2G parts, standard
    SOT-23-5, SMD bulk capacitor, Kailh MX hot-swap sockets; Manufacturer
    and MPN fields, Link field dropped.
    - Project footprint library with the hot-swap socket from
    keyswitch-kicad-library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
    [counter.kicad_sch, isomorphic_tile.kicad_sch, keyboard.kicad_sch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]
2026-09-26 Rev B PCB: 4 layers, single-sided assembly, hot-swap sockets
    Produced by hardware/kicad/tile/scripts/revb_pcb.py and
    revb_pipeline.sh (rev-A board -> netlist update -> placement ->
    Freerouting -> stitching/pours), fully reproducible.
    - 4-layer 1.6 mm stack-up, In1 GND/GND_T and In2 VCC/VCC_T planes,
    Interboard net class 0.3 mm (~55 ohm), 4 mm ground stitching grid.
    - Key board: Kailh MX hot-swap sockets and all resistors on B.Cu;
    switch centres unchanged (edge-trimmed socket footprint variant for
    the switches next to the stepped outline).
    - Logic board: every SMD part on F.Cu; series resistors within 2.6 mm
    of their drivers; one 100 nF next to each IC.
    - Fiducials (3 per board), boa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
    [isomorphic_tile.kicad_pcb, keyboard.kicad_sch]
2026-09-26 Add assembler-neutral production outputs
    hardware/kicad/tile/scripts/production.sh (kicad-cli only) refuses to
    export when ERC/DRC report errors, then writes Gerber X2 (4 layers),
    Excellon drill + maps, IPC-2581, BOM with manufacturer/MPN, an SMD-only
    pick-and-place file (hot-swap sockets reported on the bottom side),
    top/bottom assembly drawings, schematic PDF, STEP model and the fab
    notes (docs/build/fab-notes.md).
2026-09-26 Add KiKit assembly panel script and document the output set
    hardware/kicad/tile/scripts/panel.sh builds a 2-tile panel (rails,
    tooling holes, panel fiducials, mouse-bite tabs, zones refilled) in a
    rootless KiKit container and checks it with DRC (0 errors).
2026-09-27 Rev C study: single-board tile feasibility
    Scripts (hardware/kicad/tile/scripts/revc_*.py) fold the logic board
    onto the bottom of the key board using the stack transform derived
    from the stacking connectors, report conflicts, place the logic with
    the rev-B placer, measure free edge windows and run a route test.
    Findings (docs/architecture/revc-single-board.md):
    - the 2.54 mm edge connectors cannot stay (61 conflicts with switch
    bodies, holes and socket pads);
    - all logic parts fit (U109 in TSSOP-16, C105 as 1210 ceramic) and
    the folded board routes with 0 DRC errors / 0 unconnected;
    - a single-board tile needs a new edge-contact system (castellations
    on top/left, spring contacts on b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
    [revc_edges.py, revc_feasibility.py, revc_route_test.py]
2026-09-27 SI: vendor IBIS models, digitised capture, calibrated measurement model
    - digitize_scope.py turns the rev-A scope photo into CSV (grid-line
    calibration with keystone correction).
    - ibis_lite.py converts TI IBIS models (LVC2G125/126, LVC1G04; fetched
    by models/fetch.sh, not redistributed) into ngspice behavioural
    subcircuits; si_lib.py collects the blocks (drivers, receivers,
    T-line trees, AD2 front end, timeout-guarded runs). Fixes the Q of
    the AD2 Butterworth (was 1.41).
    - fit_measurement.py calibrates the controller-link model on the
    capture (RMS 0.20 V) and shows node vs AD2 views; probe_effect.py
    quantifies the probe ground loop; controller_fix.py sizes the series
    resisto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
    [scope_2026-06-15.csv]
2026-09-27 Rev C: rule out through-hole edge connectors on a single board
    Exhaustive search (revc_tht_search.py) over every right-angle THT
    position, 2.54 and 1.27 mm pitch: none is feasible on any edge, since
    switch bodies come within 1.1-1.5 mm of every edge on the top side and
    any body further in would run under a row of switch posts/sockets on
    the bottom. A single-board tile has to be all-SMD, connectors included.
2026-09-27 Rev B: keep vias off SMD pads; add KiCadRoutingTools as optional router
    - Fan-out vias now keep >= 0.35 mm of mask to their own pad and treat
    same-net SMD pads as obstacles; the previous layout had 83 vias
    within 0.2 mm of an SMD pad (solder wicking risk), found by
    KiCadRoutingTools' fab check. New tools/scripts/check_via_in_pad.py
    runs in the pipeline and in production.sh (0 on the new layout).
    - revb_pipeline.sh: ROUTER=freerouting (default) or ROUTER=krt
    (KiCadRoutingTools in a rootless container, strict options);
    revb_pcb.py gains --finish and --export-dsn.
    - Regenerated rev-B board: DRC 0 errors / 0 unconnected / 0 parity,
    invariants OK.
    [isomorphic_tile.kicad_pcb]
2026-09-27 Rev C: explain the oblique tiling vs orthogonal links, with a figure
    revc_lattice_figure.py draws rev A/B and rev C tiles from the real
    board coordinates; the rev-C document explains how rev A/B absorb the
    10 mm row skew with connector positions on a rectangular logic board,
    and how rev C keeps x/y links on the stepped key-board edges (and why
    spring contacts allow dropping a tile in from above).
2026-09-27 Rev C rework (WIP): single board on the 18.36 mm equilateral MX lattice
    - revc_pitch_figure.py / docs/media/revc-pitch-comparison.png compare
    today (20 mm), minimum equilateral (18.36 mm) and squeezed (15.9 mm)
    lattices with the MX body (15.6 mm), sockets and custom keycaps.
    - revc_build.py builds the concept board: switches on the new lattice,
    stepped outline with 1 mm gaps, logic folded on the bottom (TSSOP-16
    for U103/U104/U109, 1210 bulk cap), castellated/spring contact rows
    replacing J101-J104 with the same pin order and nets. Stage 1 places
    every part; routing is not complete yet (see ledger).
    [revc_build.py, revc_pitch_figure.py]
2026-09-27 Rev C rework (WIP): routing trials at 18.36 mm pitch
    Edge-pad stubs, fiducial rule areas, solid VCC plane restored,
    via_fits checks all copper layers. Trial 3 leaves 13 connections open:
    the top contacts need to move into the inter-socket gaps (7 contacts
    at 1.27 mm, or 8 at 1.0 mm) and the internal nets need more signal
    layers. Documented in the ledger; decisions pending.
    [revb_pcb.py, revc_build.py]
2026-09-27 Rev C: architecture draft for a microcontroller tile
    One ATtiny1616 per tile at 5 V replaces the nine logic ICs: keys on
    internal pull-ups, one bidirectional data line per edge (key events up,
    LED commands down), optional reverse-mount SK6812MINI-E per key on one
    pin. Pin budget, power/LED budget, protocol sketch, controller changes,
    open-source toolchain and open questions; LED window position checked
    on the Cherry MX drawing (south, opposite the socket).
2026-09-27 Rev C: first placement of the microcontroller tile (WIP)
    revc_mcu_build.py builds the 18.36 mm MCU tile concept (ATtiny1616
    VQFN-20 at 5 V, 12 keys, 4 edge data lines, 12 reverse-mount
    SK6812MINI-E, UPDI pad, 5 symmetric contacts per edge). Everything
    places, but the bottom-edge contacts land on the row-2 LED cut-outs
    (the up-lattice shift maps the top socket gaps onto the bottom LED
    windows); options recorded in the ledger.
    [revc_mcu_build.py]
2026-09-27 GAL experiment: rev-A/B glue logic in one ATF22V10C
    tile_glue.pld replaces the seven glue ICs (2G126, 2G08, 1G04, 2G32,
    2G125, 2G74, '161) with one ATF22V10C; assembled with galette (open
    source, rootless container): 10/10 macrocells, JEDEC generated. Two
    22V10 adaptations (single-term OE and AR) documented. Not simulated;
    kept as an alternative since it offers no LED return path.
2026-09-27 Rev C MCU tile: 3 contacts per edge, vertical link between LEDs, 2 layers
    Contacts reduced to VCC/DATA/GND (tiles never rotate). Top castellated
    pads centred on row-0 key 1 (copper may run under the socket plastic),
    bottom springs P/2 to the left, halfway between two row-2 LEDs: the LED
    cut-out conflict is gone. The board is now 2 layers (no fast
    inter-tile clock; GND poured on both sides). Placement complete;
    routing not run yet (stopped by the system for low memory).
2026-09-27 Rev C MCU tile: routed on 2 layers, DRC clean
    - GND plane on the top (switch) side, VCC as tracks and a stitched GND pour
    on the bottom; routed with KiCadRoutingTools by revc_mcu_route.sh
    (plane first, then a routing pass and repair passes that also re-queue
    ripped-up nets).
    - Via-only rule areas around every SMD land: no via-in-pad anywhere.
    - Rule areas fence the reverse-mount LED cut-outs; the custom DRC rule
    now matches with memberOfFootprint().
    - LED chain as a serpentine so every link goes to a neighbour; LED
    decoupling next to the corner LEDs; MCU paste-only pads left without net.
    - Routed board kept in hardware/kicad/revc-mcu-tile/: KiCad DRC 0 errors,
    0 unconnected; no v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
    [revc_mcu.kicad_pcb]
2026-09-27 Rev C MCU tile: KiCad schematic drives the board
    - revc_mcu_circuit.py defines the circuit once; revc_mcu_schematic.py
    writes it as a KiCad schematic (stock symbols embedded, stable UUIDs).
    - The board build takes every net, value and field from the netlist that
    kicad-cli exports, checks that board and schematic hold the same parts
    and footprints, and links footprints to symbols.
    - Pin swapping: the 15 interchangeable MCU signals get the pins in the
    angular order of their destinations; stored in pinmap.json (also for
    the firmware), and the schematic is redrawn when it changes.
    - LED chain starts at D6, next to the MCU; the flow tries MCU
    orientations until the board is clean.
    - F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
    [revc_mcu.kicad_pcb, revc_mcu.kicad_sch]
2026-10-12 Single-board tile: self-checking logic and drop-in connector experiments
2026-10-13 Single-board tile: consolidate FPGA development and retire obsolete designs
2026-10-16 Checkpoint FPGA electrical design and incomplete four-layer routing trial
    Work stopped 2026-10-16 15:18 CEST by user request. Four-layer GW1NZ
    ground-pour repair left at: 0 error-severity DRC, 150 warnings, 54 ground
    opens, 44/52 post-import power attaches, 2 copper-neck warnings open,
    8 unplaced. No acceptance gate closed.
